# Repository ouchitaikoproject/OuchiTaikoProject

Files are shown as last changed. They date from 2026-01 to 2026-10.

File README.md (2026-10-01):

<div align="center">
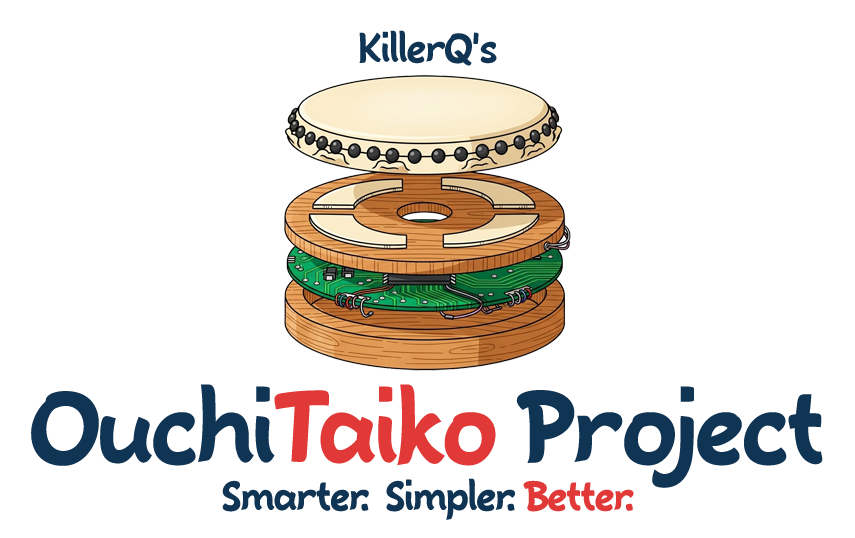
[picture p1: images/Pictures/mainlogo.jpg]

</div>

---

<div align="center">
<i>In Japanese, "ouchi" means "home," and "taiko" means "drum."
</br>  
Together, OuchiTaiko represents the joy of bringing the arcade Taiko experience into your own space.</i>
</div>

---

# Table of Contents

- [1. Project Overview](#project-overview)
- [Key Features and World Firsts Not Seen In Any Other Existing Projects](#key-features)
  - [1) Guided Calibrate](#guided-calibrate)
  - [2) Adaptive Baseline Software Intelligence (ABSI)](#absi)
  - [3) Custom Arcade Sensor Suspension Modeled After Japanese Taiko Arcade Hardware](#sensor-suspension)
  - [Complete Hardware & Features](#complete-hardware-features)
- [2. Parts List for Electronics](#parts-list-electronics)
- [3. Parts List for Hardware](#parts-list-hardware)
- [4. Assemble the Controller PCB](#assemble-controller-pcb)
- [5: Build the Sensor Housings](#build-sensor-housings)
  - [5.0: Print The Sensor Housings](#print-sensor-housings)
  - [5.1: Assemble Sensor Electronics](#assemble-sensor-electronics)
- [6: Build the Drum](#build-drum)
  - [6.1: Prepare the Wood](#prepare-the-wood)
  - [6.2: Assemble the Drum Structure](#assemble-drum-structure)
  - [6.3: Assemble The Rubber Isolators](#assemble-rubber-isolators)
  - [6.4: Mount the Sensor Housings to The Drum](#mount-sensor-housings-to-drum)
  - [6.5: Mounting The Hardware And Faceplates](#mounting-hardware-and-faceplates)
- [7: Control Box Connection](#control-box-connection)
  - [7.1: Floor Stand Mode](#floor-stand-mode)
  - [7.2: Table-Top Mode](#table-top-mode)
- [8: Flash the Firmware](#flash-the-firmware)
- [9: Calibration & Settings](#calibration-settings)
- [10: Files & Downloads](#files-downloads)
- [11: Basic Troubleshooting](#basic-troubleshooting)
- [12: Menu System Reference](#menu-system-reference)
- [13: About](#about)
- [14: Copyright Information](#copyright-information)

---

# 1. Project Overview

## The Finished Build
This guide walks you through building a full Arcade-Scale Taiko drum and controller that can be used in either **Floor-Standing Tripod Mode** or **Table-Top Mode**.

<div align="center">
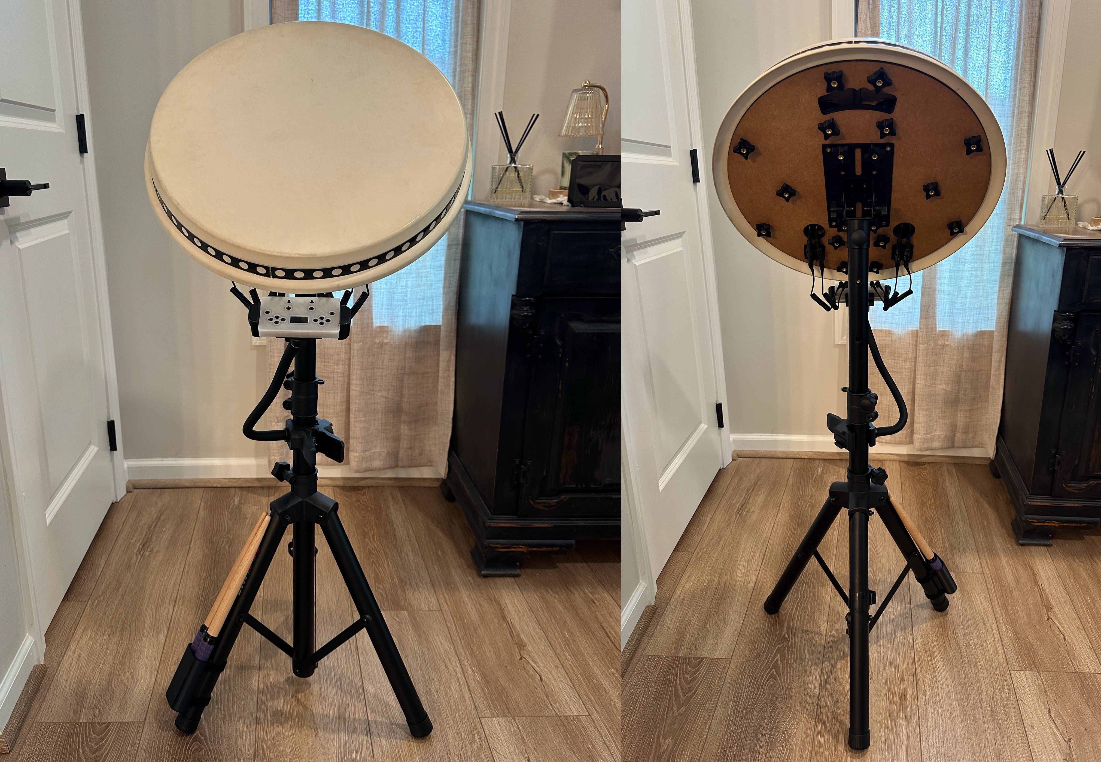
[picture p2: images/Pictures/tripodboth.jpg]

</div>

<div align="center">
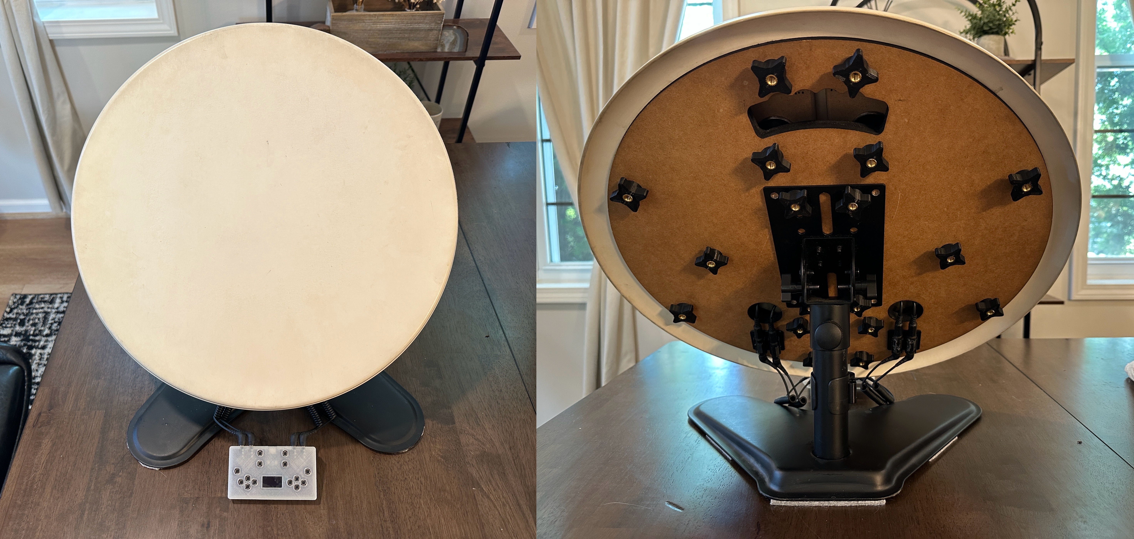
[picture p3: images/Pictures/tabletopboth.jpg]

</div>

---

Hi, I'm KillerQ - creator of the **OuchiTaiko Project**, an open-source guide for building a professional, arcade-grade Taiko drum controller.

This project is the result of over a year and a half of Research & Development focused on solving the high cost, limited availability, and inconsistent performance of commercial Taiko controllers. By combining a completely new software performance engine, a custom through-hole PCB, and a mechanically isolated sensor system, OuchiTaiko delivers arcade-level responsiveness with approachable DIY construction.

All you need are very basic soldering and woodworking skills.

This guide is intentionally thorough and detailed - the goal is simple: **less guessing, more building.**

---

# Key Features and World Firsts Not Seen In Any Other Existing Projects

Traditional Taiko controllers often require constant threshold tuning, extensive coding and firmware recompiling, or compromises between sensitivity and false triggers.

**OuchiTaiko solves these issues with three core systems:**

1. Guided Calibrate  
2. Adaptive Baseline Software Intelligence (ABSI)  
3. Custom Sensor Suspension System
---

## 1) Guided Calibrate
OuchiTaiko includes two Guided Calibrate options:

- Guided Calibrate for the preferred full setup workflow  
- On-device Guided Calibrate for the same method, but on the controller  
- No recompiling required  
- Fast threshold refinement  
- Easier crosstalk diagnosis  
- Quick retesting after hardware changes  

---

## 2) Adaptive Baseline Software Intelligence (ABSI)
ABSI was created by me just for this project, and I am very proud of it. It drastically improves stability through software rather than complex analog circuitry.

- Automatic sensitivity adjustment based on environmental noise  
- Dynamic baseline tracking  
- Stable long-term behavior without drift  

---

## 3) Custom Arcade Sensor Suspension Modeled After Japanese Taiko Arcade Hardware
A mechanically isolated sensor housing improves consistency and reduces noise.

Benefits include:

- More consistent hit detection  
- Reduced mechanical crosstalk  
- Cleaner signal processing  
- Long-term durability  

---

## Complete Hardware & Features

### Standalone Testing & Display
No PC required for basic verification.

- OLED display with live feedback  
- Visual confirmation of all 14 navigation buttons  
- Live hit display and mode readout  
- Instant sensor and button assignment wiring verification using only USB power  

---

### Professional Hardware

- Custom PCB designed specifically for this project  
- 14 navigation buttons for full game control  
- Adjustable drum mounting options  
- Dedicated sensor inputs for all four drum lanes 
- The entire Drum is modular so if a part ever fails, just that single part can be easily accessed and swapped out

---

### Controller Modes

| Mode | Platform Compatibility
|---|---|
| **Switch Tatacon** | Nintendo Switch
| **Switch Pro** | Nintendo Switch 
| **PS3 Dualshock3** | PC/Steam only
| **PS4 Tatacon** | PC/Steam only
| **PS4 Dualshock4** | PC/Steam only
| **Keyboard P1** | PC
| **Keyboard P2** | PC
| **Xbox 360** | PC/Xbox
| **Android (XInput)** | Android devices
| **iOS (XInput)** | iOS devices
| **Analog P1** | PC (TaikoArcadeLoader)
| **Analog P2** | PC (TaikoArcadeLoader)
| **MIDI** | PC/DAW software
| **Guided Calibrate** | Development/Testing

---

### Zero Coding Required

- Drag-and-drop firmware flashing  
- On-device menus  
- No recompiling for normal setup  
- No programming knowledge needed  

---

### Demo Video

- Gameplay: https://youtu.be/p4eFeo_LB5I?si=jDKb93B7uYx1qAux

---

# 2. Parts List for Electronics

<div align="right"><sub><a href="#table-of-contents">-Back to Top-</a></sub></div>

These linked parts are verified to work together as tested. Similar/comparable parts can be used, but at your own risk.

| Item | Pieces Needed | Product Link |
| --- | --- | --- |
| Waveshare RP2040-Zero | 1 | https://www.amazon.com/dp/B09SBCKYSC |
| 1N4148 diodes | 4 | https://www.amazon.com/dp/B0DN62QFYS |
| 0.1uF / 100nF ceramic capacitors | 4 | https://www.amazon.com/dp/B08B3VCK42 |
| 3.5mm female audio jack, PJ-320A | 4 | https://www.amazon.com/dp/B07KY862P6 |
| 3.5mm TRS male plugs with leads | 4 | https://www.amazon.com/dp/B0D72TV7Y5 |
| 1K ohm resistor, 1/2W | 4 | https://www.amazon.com/dp/B0FP1YFMVM |
| 27mm piezo sensors (for full size Drum Sensors) | 4 | https://www.amazon.com/dp/B07RK2TQ8D |
| 20mm piezo sensors (for smaller sensor option) | 4 | https://www.amazon.com/dp/B00SWO6VJ0 |
| 128x64 mono OLED display (I2C) | 1 | https://www.amazon.com/dp/B09T6SJBV5 |
| 6mm tactile switches with caps | 14 | https://www.amazon.com/dp/B07VQF8P2Y |
| 6" coiled 3.5mm TRS extension cable | 4 | https://www.amazon.com/dp/B0D7CXJ5LQ |
| 3.5mm TRS barrel coupler | 4 | https://www.amazon.com/dp/B072J3LGSQ |
| 6ft USB-A to USB-C cable | 1 | https://www.amazon.com/dp/B0CKXZML11 |

---

# 3. Parts List for Hardware

<div align="right"><sub><a href="#table-of-contents">-Back to Top-</a></sub></div>

## Required Tools & Supplies

1. Laser cutter, CNC, or alternative cutting method  
2. Soldering iron + solder  
3. Wire strippers / cutters  
4. Screwdrivers  
5. Hot glue gun  
6. Strong clamps  
7. Drill  
8. Router  
9. Sandpaper  
10. Utility knife  
11. Rubber mallet  

## Hardware Parts List

| Item | Pieces Needed | Product Link |
| --- | --- | --- |
| 1/4" (6mm) MDF, 2ft x 4ft | 2 | https://www.homedepot.com/p/1-4-in-x-2-ft-x-4-ft-MDF-1508104/202089069 |
| 1/4" x 1-1/2" OD stainless fender washers | 46 | https://www.amazon.com/dp/B0D8ZRL1CP |
| Wood glue | 1 | https://www.amazon.com/dp/B0002YQ378 |
| M3 x 8mm bolts (for full size sensors) | 8 | https://www.amazon.com/dp/B0FS1Q3FC2 |
| M3 x 8mm bolts (for smaller size sensors) | 8 | https://www.amazon.com/dp/B0FS1Q3FC2 |
| M3 x 5mm threaded inserts | 8 | https://www.amazon.com/dp/B0FS1Q3FC2 |
| M6 x 10mm wood threaded inserts | 14 | https://www.amazon.com/dp/B0CNLRFFH1 |
| M6 x 35mm nylon bolts | 14 | https://www.amazon.com/dp/B07L9ZS21T |
| M6 threaded 20mm x 15mm rubber isolators | 14 | https://www.amazon.com/dp/B0BKPHT6Y9 |
| PLA filament | 1 | https://www.amazon.com/dp/B081S5N5PC |
| Gel superglue | 1 | https://www.amazon.com/dp/B0006HUJCQ |
| Medium thread adhesive / Loctite | 1 | https://www.amazon.com/dp/B000FIXQXK |
| 2.2mm scuba knit neoprene fabric | 1 | https://www.amazon.com/dp/B0DK1B5LZ7 |
| Finger knobs with pass-through M6 threads | 18 | https://www.amazon.com/dp/B07RW9ZH4H |
| Mini PA speaker tripod stand (optional) | 1 | https://www.amazon.com/dp/B094N9YG72 |
| Desktop monitor stand (optional) | 1 | https://www.amazon.com/dp/B072QDMRS8 |
| Adjustable angle speaker bracket | 1 | https://www.amazon.com/dp/B0DR8NCZP6 |
| Phone holder w/ gooseneck arm (optional) | 1 | https://www.amazon.com/dp/B0F32MLBZX |
| Rubber Taiko drum cover (recommended) | 1 | https://taiko.ac/products/rubber-drum-pad |
| 1/4" roundover router bit | 1 | https://www.amazon.com/dp/B0C5DVBNLS |
| Clear spray glaze / lacquer | 1 | https://www.amazon.com/dp/B00D0293SA |
| Deburring tool (optional) | 1 | https://www.amazon.com/dp/B07RM1D6WD |

---

# 4. Assemble the Controller PCB

<div align="right"><sub><a href="#table-of-contents">-Back to Top-</a></sub></div>

<div align="center">
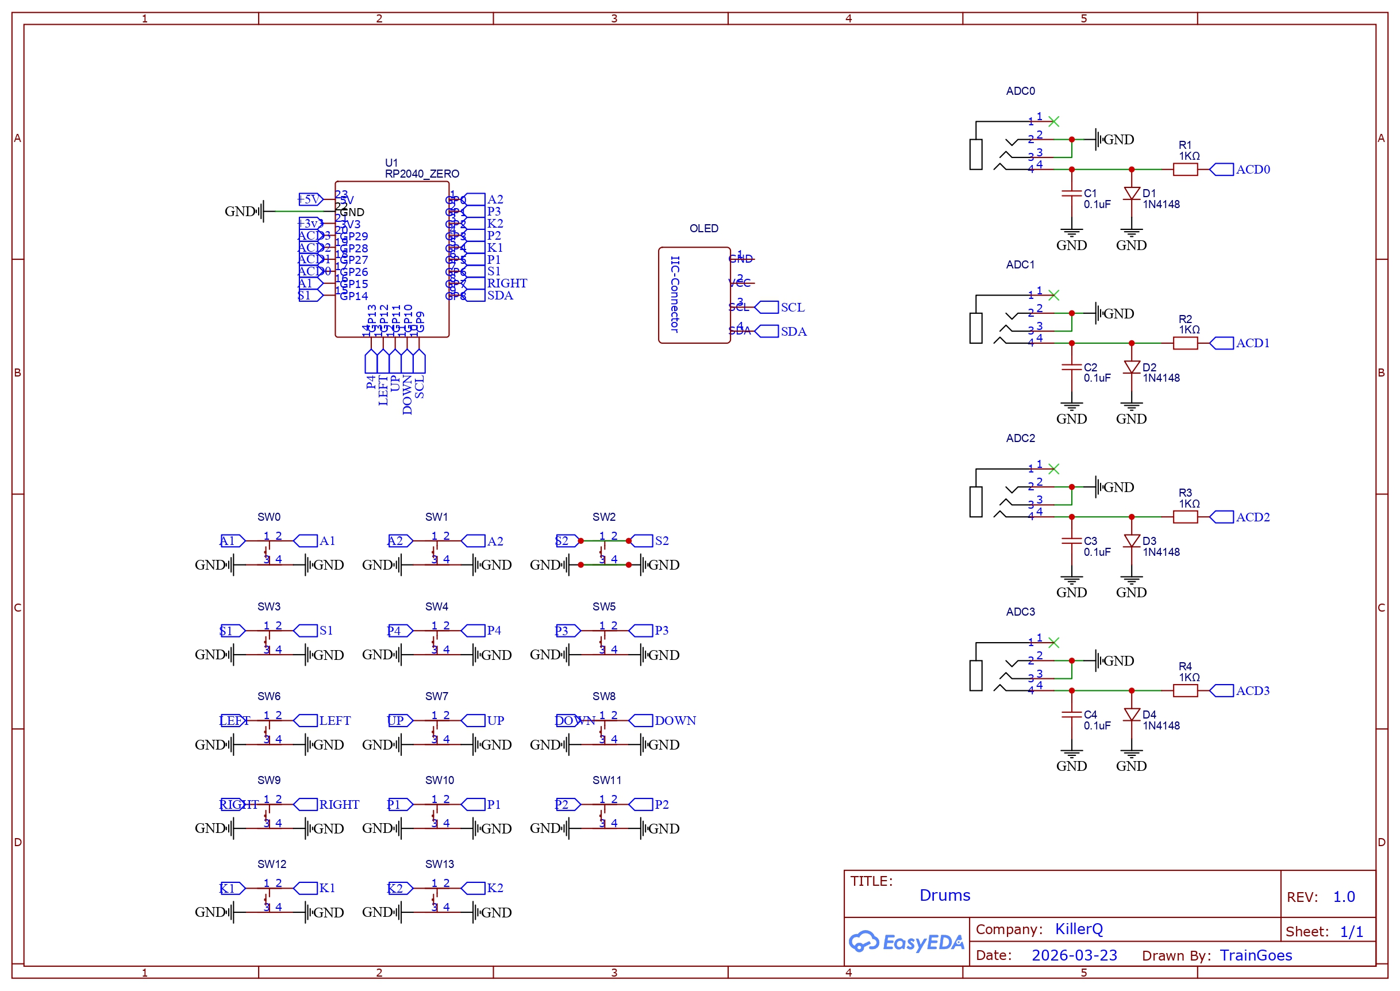
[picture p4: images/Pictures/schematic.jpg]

</div>

<div align="center">
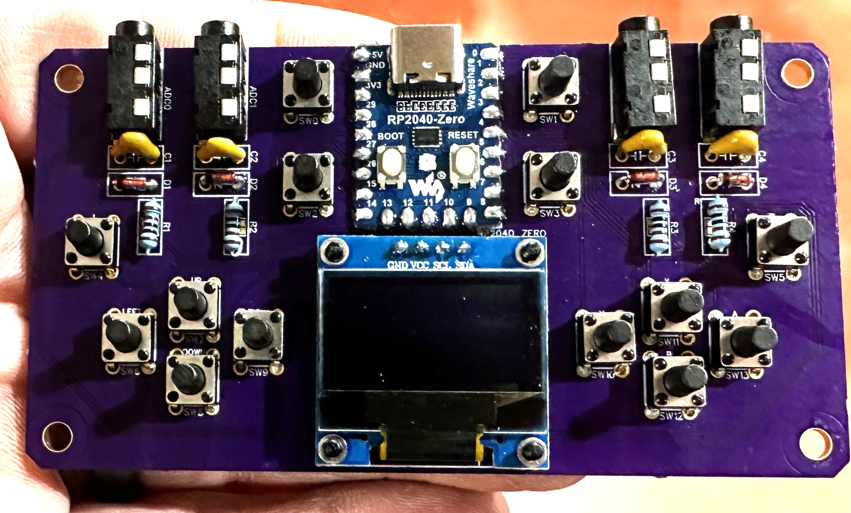
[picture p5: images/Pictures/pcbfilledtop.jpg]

</div>

## Purchase the OuchiTaiko Controller PCB (Circuit Board).

My project is set up to where you will order the through-hole circuit board and then solder the basic components in yourself.  This saves time, money, and eliminates any room for error.

I <i>highly</i> recommend purchasing the raw Controller PCB from OSHPARK PCB Fabrications. They are in the US, and all manufacturing is done in the US. They are very reasonably priced, and you can even pay for expedited production/shipping. They sell in sets of 3 only, but that price is still reasonable, and that way you have a spare in case you damage one, or you can split the order with a friend.  You may notice that this company charges more than others that manufacture outside of the US, but if you read around their site, you'll see that they quality is above-and-beyond and the boards have an amazing look and feel to them.

If you decide use OSHPARK here is a link to the Board that's already uploaded and verified on their site, and you can hit purchase right away. I do not make any money off of this link or benefit in any way - they just offer the convenient service of allowing me to upload the board so that people can simply add it to their cart and check out without the hassle of uploading the raw files and hoping everything is correct and verified after the upload, etc.

<a href="https://oshpark.com/shared_projects/mY0Hmilt">HERE is the link to the OSHPARK OuchiTaiko Controller Board Page</a>

However, since I made my project open source, you have 100% control over where to have the board manufactured.  If you have a company that you trust that you would like to use instead, here is the Gerber .zip file that contains all of the universal project files that the company will need to produce my OuchiTaiko PCB.  

[`ouchitaiko_pcb_gerber_v1_final.zip`](https://raw.githubusercontent.com/ouchitaikoproject/OuchiTaikoProject/main/download_files/ouchitaiko_pcb_gerber_v1_final.zip) is the PCB Gerber file package.

One person used https://jlcpcb.com/ and ordered my board (by uploading the above Gerber file) and had 5 boards made for about $6 total including shipping and it took around 2 weeks.

## Control PCB Overview

My custom OuchiTaiko PCB integrates controller logic, display wiring, navigation buttons, and drum input circuitry all together into a single compact board.

To finish building it, you will solder the following components to the board you have made:

- **1x Waveshare RP2040-Zero**  
- **14x tactile buttons**  
- **4x 1N4148 diodes**  
- **4x 1K resistors**  
- **4x 0.1uF capacitors**  
- **1x I2C OLED**  
- **4x PJ-320A TRS jacks**

That's it!  Everything is just attached via basic soldering.

---

## Recommended Assembly Order

### Step 1: Solder Passive Components
Install:

- `R1-R4` = 1K resistors

<div align="center">
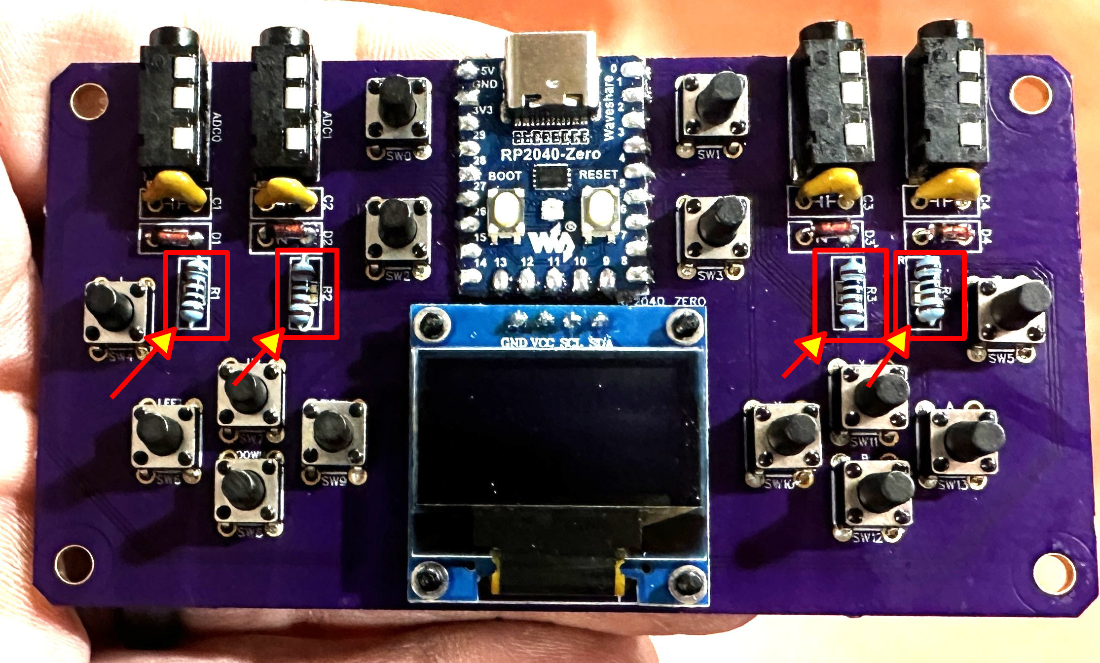
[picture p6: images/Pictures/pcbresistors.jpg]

</div>

- `C1-C4` = 0.1uF capacitors

<div align="center">
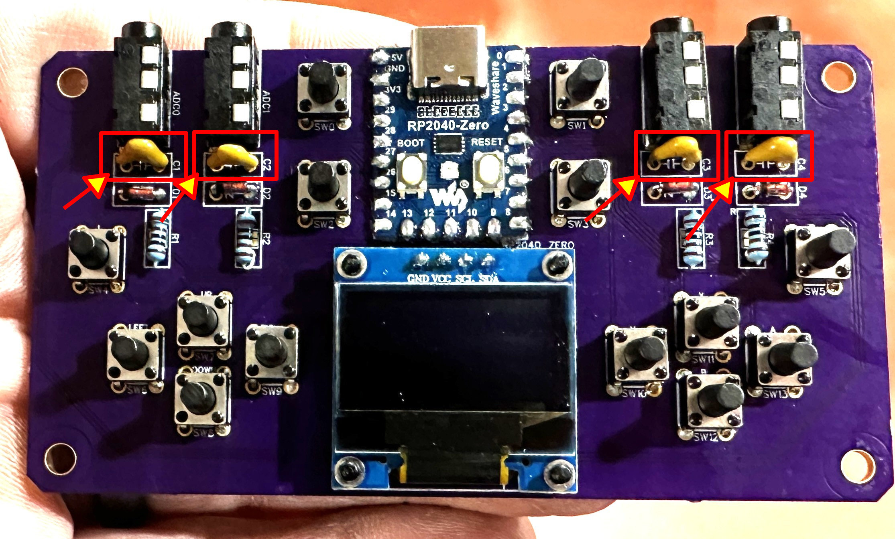
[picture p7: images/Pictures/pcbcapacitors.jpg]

</div>

- `D1-D4` = 1N4148 diodes

<div align="center">
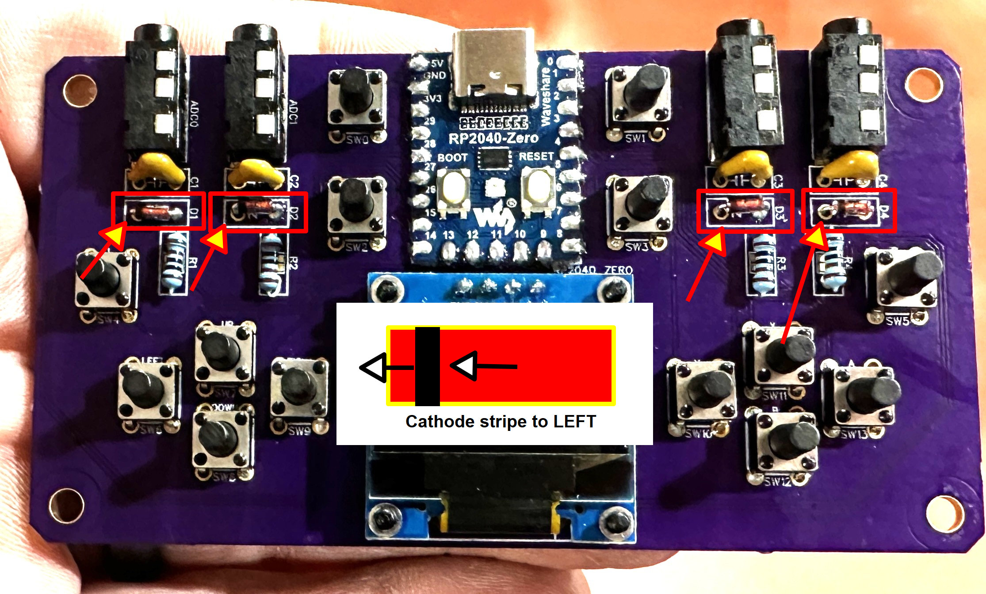
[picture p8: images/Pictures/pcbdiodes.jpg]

</div>

Important: Ensure diode black bands match the silkscreen (cathode to the **left** when viewed from above).

---

### Step 2: Solder the 14 Buttons
Install all navigation buttons.

<div align="center">
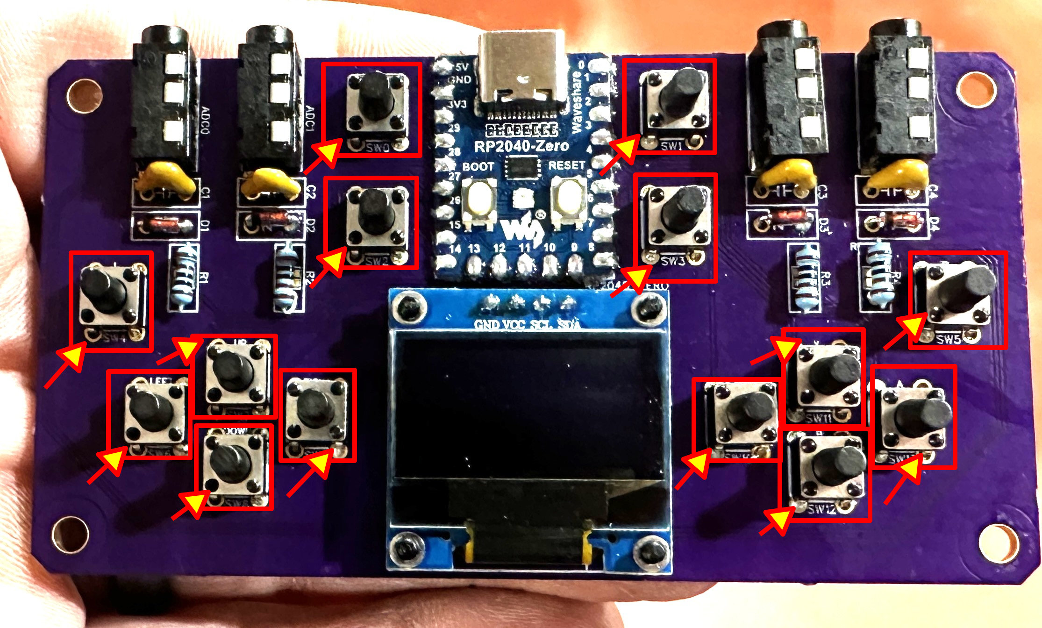
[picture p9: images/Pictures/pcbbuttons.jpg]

</div>

The button legs will actually appear in a rectangular layout orientation - longer on one side. The holes in the board will match that slightly rectangular shape - there is no polarity as long as that orientation is adhered to. Ensure each button sits flat before soldering all four legs.

---

### Step 3: Mount the OLED
Install the OLED using the following pin order (verify that yours matches):

- GND  
- VCC  
- SCL  
- SDA  

<div align="center">
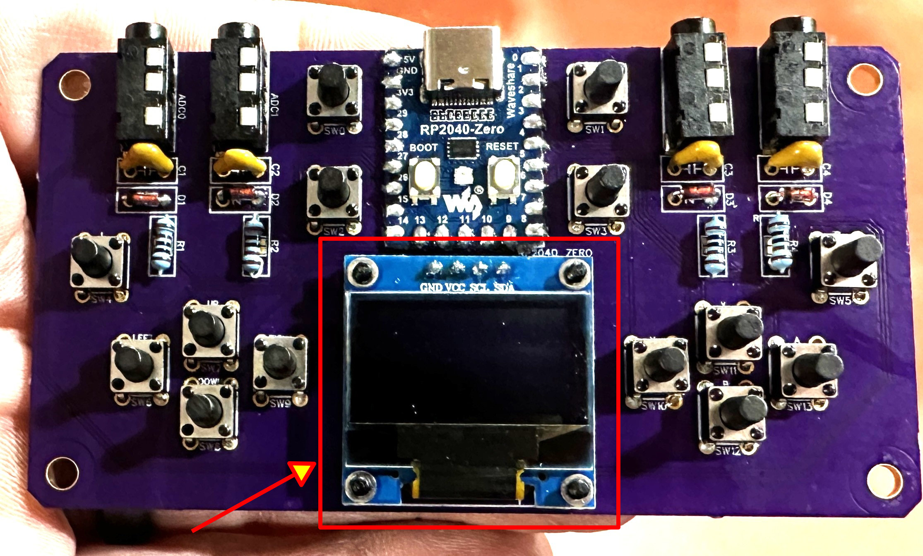
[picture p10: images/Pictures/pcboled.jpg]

</div>

---

### Step 4: Install the TRS Drum Input Jacks
Install the four PJ-320A jacks. Their pin layout only fits into one orientation.

<div align="center">
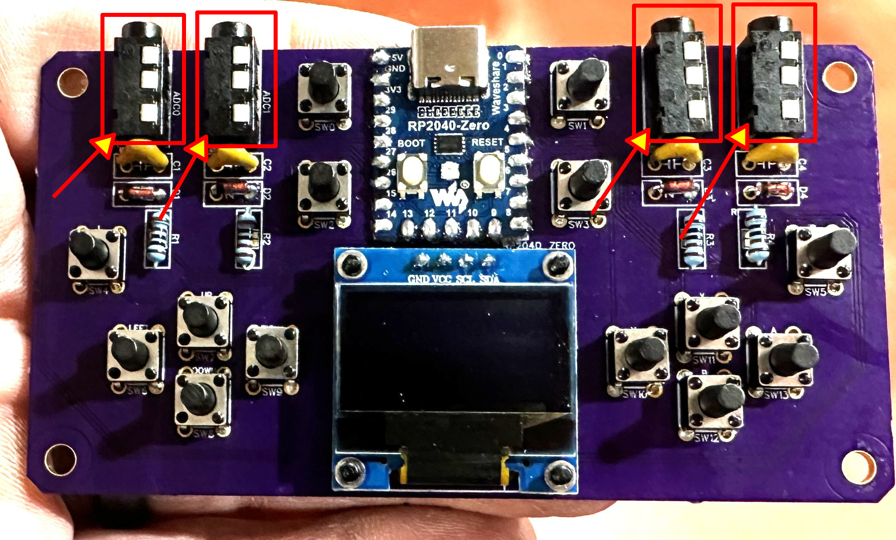
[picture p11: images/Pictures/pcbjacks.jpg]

</div>

---

### Step 5: Mount the RP2040-Zero
Install the Waveshare RP2040-Zero. Only the 20 castellated <i>perimeter pads</i> need soldering.

<div align="center">
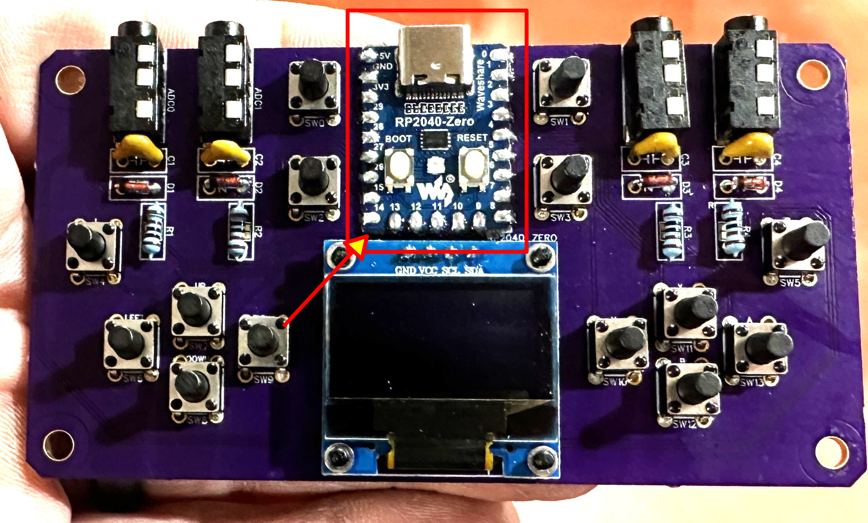
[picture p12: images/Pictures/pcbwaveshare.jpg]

</div>

A helpful soldering demonstration for soldering castellated pads:  
https://youtu.be/rGvvwXrv310?t=312

---

## Inspect Your Work

Before powering on, confirm:

- RP2040-Zero is aligned correctly  
- OLED pins are correct  
- All 14 buttons are soldered  
- All four drum lanes have resistor, capacitor, and diode installed  
- No solder bridges  
- All joints look solid  

If you were just building the controller and sensors for an existing drum that you already had, you can skip ahead to **Section 8: Flash the Firmware**.

---

# **5: Build the Sensor Housings**

## **5.0: Print The Sensor Housings**

\*\* download \*\* [`ouchitaiko_sensor_housing.stl`](https://raw.githubusercontent.com/ouchitaikoproject/OuchiTaikoProject/main/download_files/ouchitaiko_sensor_housing.stl) is the sensor housing STL file

Print 4 complete sets of Sensor Housings (each set has a top and bottom).

Use **PLA filament**.

**Printer Settings:** 0.2mm layer height, 40% Gyroid infill, no supports needed.

## **5.1: Assemble Sensor Electronics**

\*\* video \*\* [Video overview of sensor housing assembly](https://youtu.be/tQe-xDEqEdY)

(Note: If you choose to make the smaller version of the sensor housings because you're using them on a smaller drum, the below procedure is the same except you'll 3D print the smaller housing and bracket, you'll cut a 8mm neoprene disc (instead of 12mm) and you'll use the 20mm Piezo (instead of the 27mm Piezo).  The installation is the same, just smaller parts).

### **Cut neoprene discs**

Cut four **12mm neoprene discs** by using the SVG template.

\*\* download \*\* [Neoprene Disc Template Files are in the file packet here](#files-downloads)

### **Glue neoprene disc to housing**

Place several drops of **Superglue** into the raised center ring in the bottom shell of the housing. Place a single neoprene disc in this ring on top of the glue. Press lightly for 30 seconds.

<div align="center">
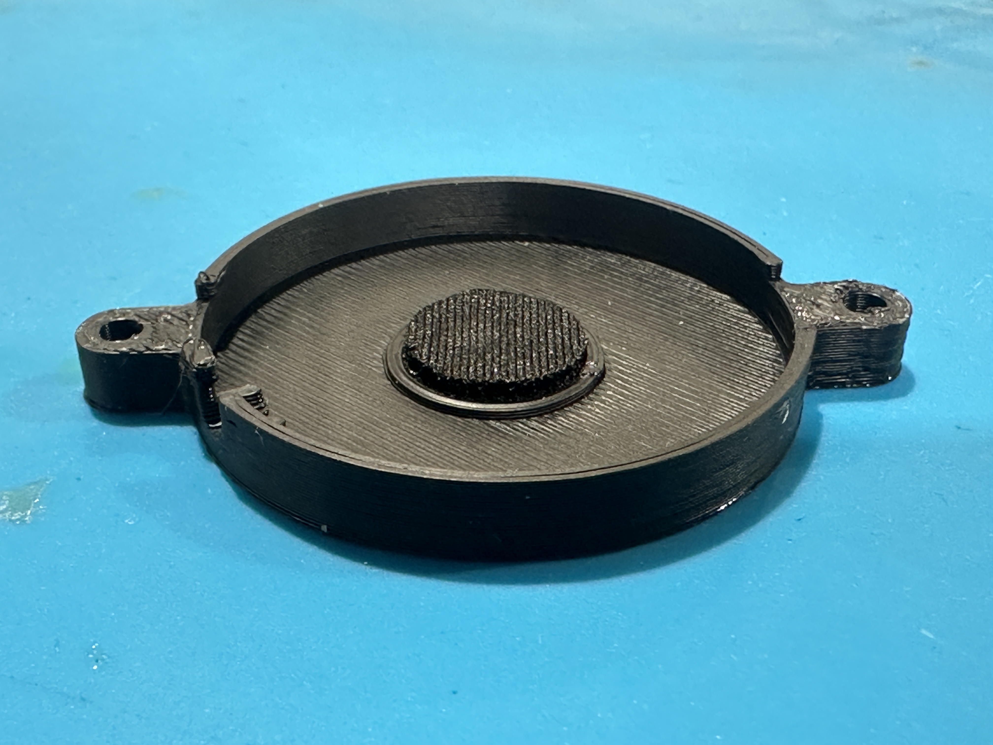
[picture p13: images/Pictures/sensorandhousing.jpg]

</div>

### **Prepare end of TRS Sensor Wires**

(**IMPORTANT** 
This guide assumes that your 3.5mm cable has the RED wire connected to the TIP of the TRS jack 
and that the BLACK wire is connected to the SLEEVE of the TRS jack. 

The result of the sensor wiring needs to be that the center of the disc is connected to the TIP
and that the brass part of the ring is connected to the SLEEVE of the TRS jack.)  

Since you are starting with long lengths of wire, you have two choices to proceed.

1. If you plan on building the drum in my guide, then you can cut the length of wire down to approximately 12" so that it will route cleanly through the drum and end up at the connectors at the base of the drum.
2. If you plan on using these sensors to add to a different or already existing drum, I suggest that you leave the wires at their full length. This allows more freedom of mounting and routing when using them with another drum.

With your chosen length of wire, strip the ends of each so that they expose approximately 10mm of red wire and approximately 8mm of black wire. Now strip off approximately 1mm of red and black insulation to expose the bare wire and tin each end with solder.

Repeat this process for all 4 wires.

The difference in length is because you want them to be slightly offset as in this photo: 

<div align="center">
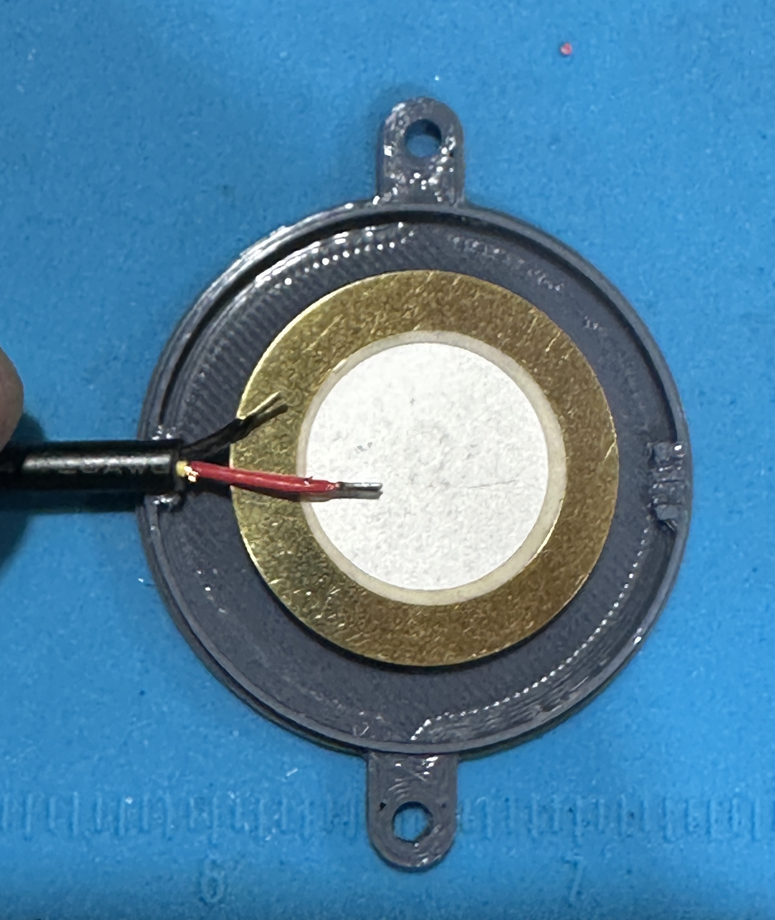
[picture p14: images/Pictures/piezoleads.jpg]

</div>

### **Solder to Piezo**

Now solder the **red** wire to piezo center disc, and solder the **black** wire to outer brass ring. The video linked at the beginning of this section illustrates how to do this easily.

<div align="center">
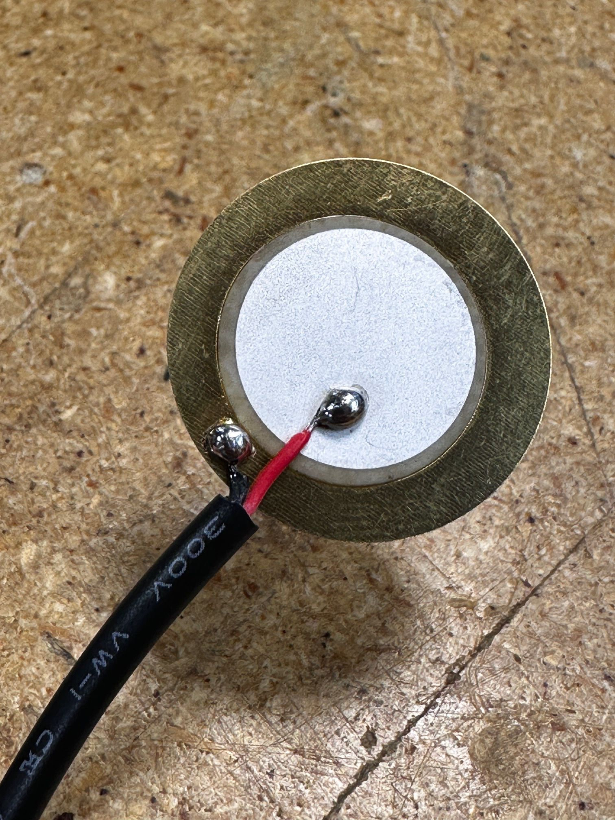
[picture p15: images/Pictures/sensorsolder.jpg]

</div>

### **Glue Piezo to Neoprene Mount**

Add several drops of **Superglue** onto the top surface of neoprene that is already glued to the bottom housing shell. Center the **piezo sensor** face up (the all-brass side faces *down*, your wires will be on the top) onto the neoprene. Press lightly for 30 seconds. 

\*\* note \*\* Pic varies slightly from your version - this was an earlier version.

<div align="center">
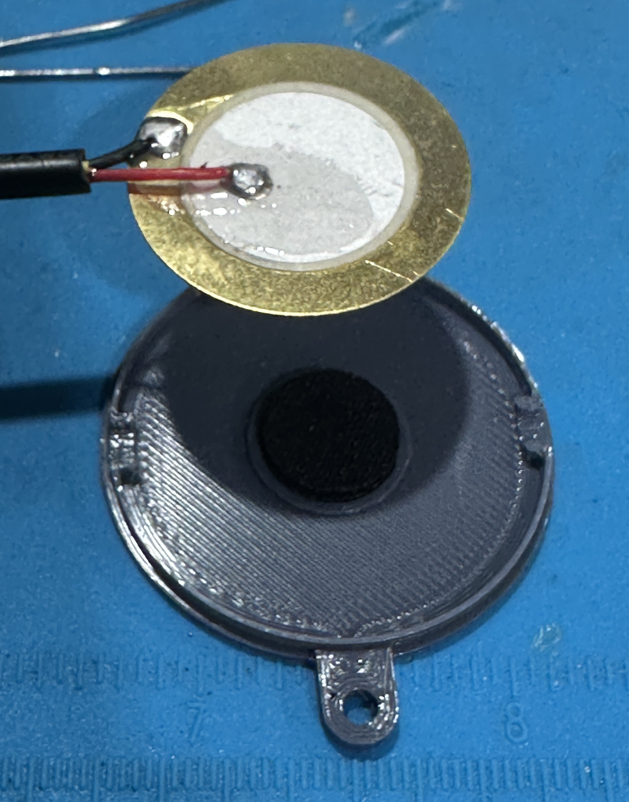
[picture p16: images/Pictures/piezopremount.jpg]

</div>

<div align="center">
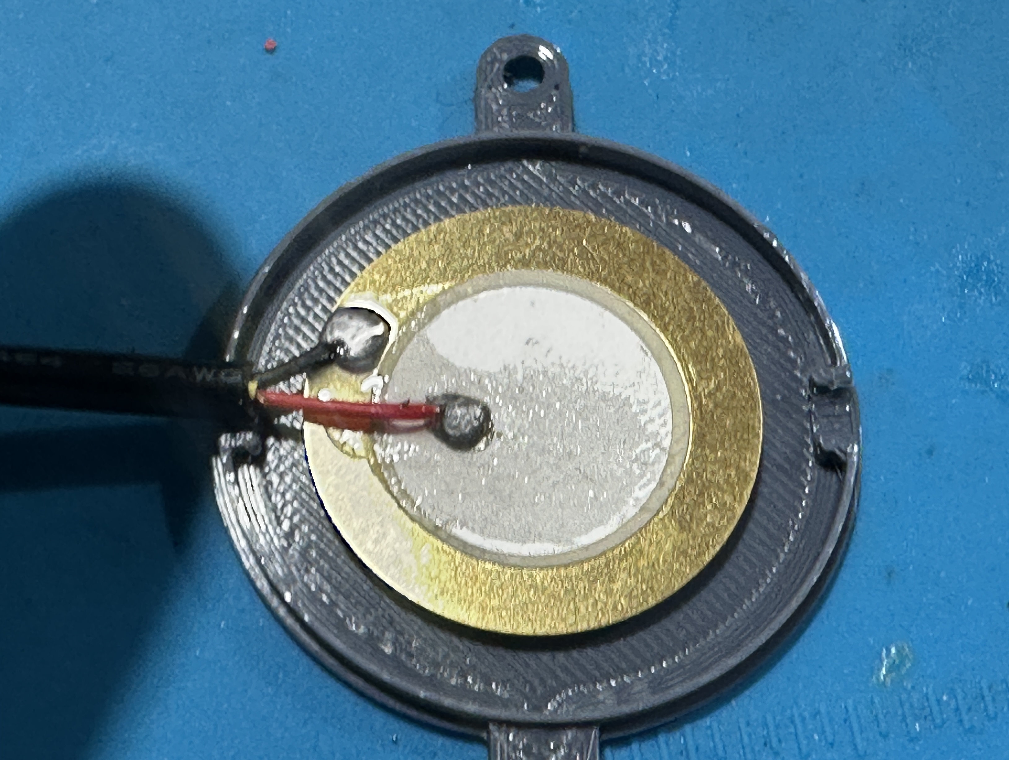
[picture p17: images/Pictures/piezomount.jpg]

</div>

### **Enclose Housing**

Add a drop of **Superglue** around the inner rim of the housing and then press the two halves together. Press and hold for 30 seconds. The top shell of the housing will nest into place when aligned properly.

After 30 seconds, add a little bit of **Hot Glue** to the wire where it meets against the outside of the housing - this will act as additional strain relief. 

<div align="center">
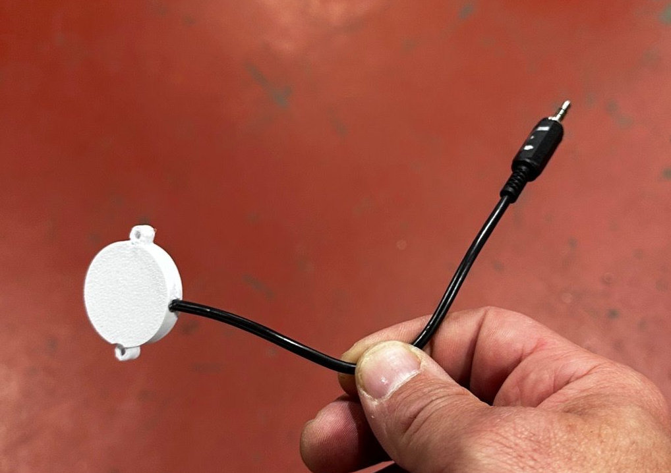
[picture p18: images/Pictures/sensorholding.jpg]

</div>

> Repeat these steps until you have 4 complete sensor assemblies.
>
> **Using these sensors with an existing drum that you have?**
> You can skip the full drum build. Jump to [**Section 6.4: Mount the Sensor Housings to The Drum**](#mount-sensor-housings-to-drum), then continue to [**Section 8: Flash the Firmware**](#flash-the-firmware).
>
> **Building a new drum using my guide?**
> If you are building the complete OuchiTaiko drum, continue below to Step #6 to begin constructing your Taiko Drum.

# **6: Build the Drum**

<div align="right"><sub><a href="#table-of-contents">-Back to Top-</a></sub></div>

**Important Scale Notice:** The SVG files provided in the download are the correct scale and should **NOT** be resized. The drum dimensions are precisely calculated to work with the sensor housings and other non-scalable components. If you try to make the drum smaller, other parts will not fit later in the project.

\*\* note \*\* Before cutting, verify the SVG files are at correct scale by checking the shapes in the SVG file against the listed dimensions noted in the KEY section of that same SVG file. 

**No laser cutter or CNC access?** No worries - there are other options. Ask a friend, local shop, or check if your area has a Makerspace. Alternatively, you can print the SVG files full-size across multiple sheets of paper (ensure your printer is set to 100% scale / "Actual Size"), and then overlay the paper on your wood as a template.  You would then cut and drill by hand. Double check that your printed templates are sized properly before cutting or drilling anything.

## **6.1: Prepare the Wood**

### **Cut all MDF wood pieces per SVG templates**

\*\* download \*\* [`ouchitaiko_laser_files.svg`](https://raw.githubusercontent.com/ouchitaikoproject/OuchiTaikoProject/main/download_files/ouchitaiko_laser_files.svg) and [`ouchitaiko_laser_files.lbrn2`](https://raw.githubusercontent.com/ouchitaikoproject/OuchiTaikoProject/main/download_files/ouchitaiko_laser_files.lbrn2) are the wood template files

Use your laser or CNC machine (or the method available to you) to cut out all of the wood components in the template files.

- You'll be printing one set of upper faceplates
- You'll be printing one set of lower faceplates
- You'll be printing 2x identical baseplates

<div align="center">
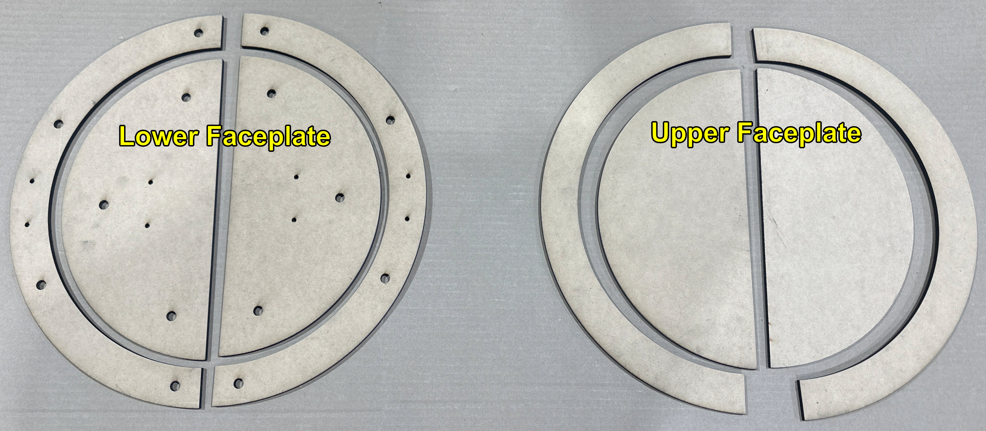
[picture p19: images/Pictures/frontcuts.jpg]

</div>

<div align="center">
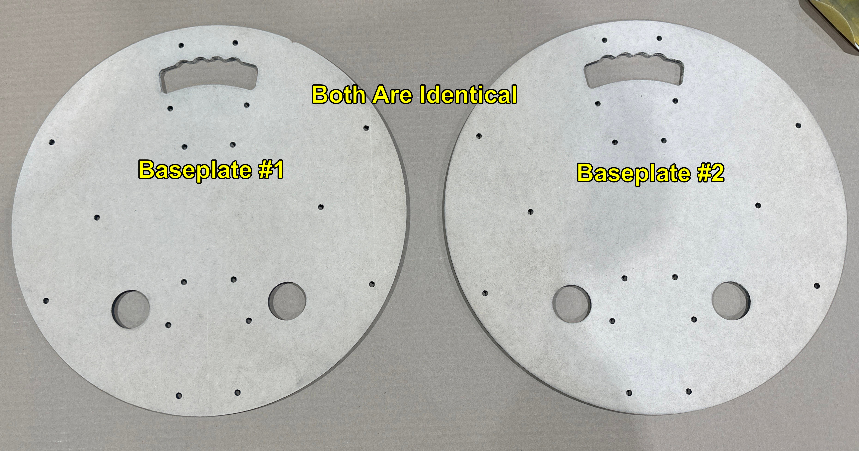
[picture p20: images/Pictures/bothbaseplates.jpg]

</div>

### **Sand smooth as needed**

Sand down any rough edges and surfaces from the cutting step, and wipe off sawdust to prepare for gluing.

## **6.2: Assemble the Drum Structure**

### **Glue the rear baseplates together**

Use **wood glue** to glue the two identical rear baseplates together (they are 100% identical, just align the holes and glue together). Clamp securely or weigh down and let dry for several hours. You can also temporarily insert some 6mm bolts into the holes to ensure the two plates remain exactly aligned. Until the glue really starts to set, periodically check the plates to make sure no shifting has occurred - if so, re-align and clamp harder.

Leave the clamps and weight on for at least 6 hours. Let the glue fully cure for 24 hours before continuing past the gluing steps.

<div align="center">
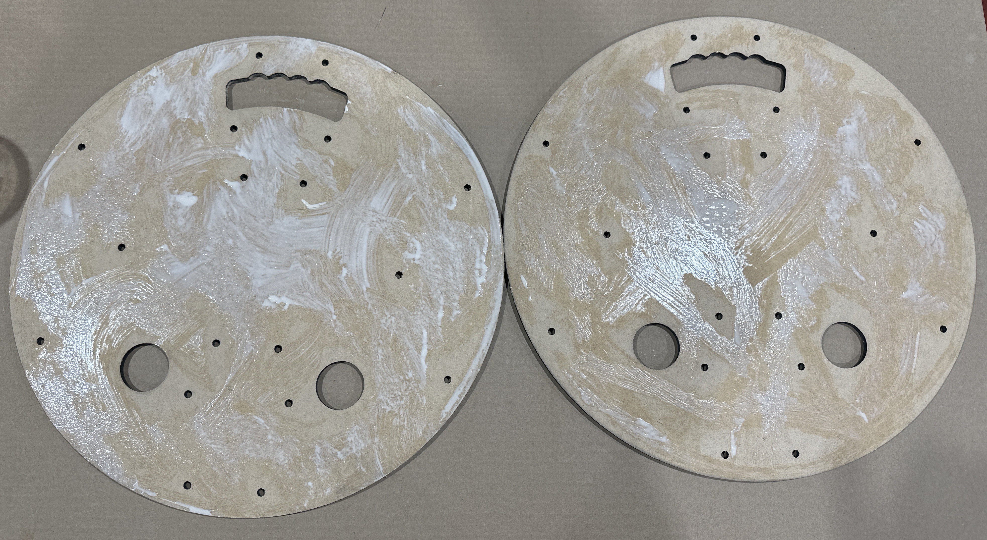
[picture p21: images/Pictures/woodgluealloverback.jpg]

</div>

<div align="center">
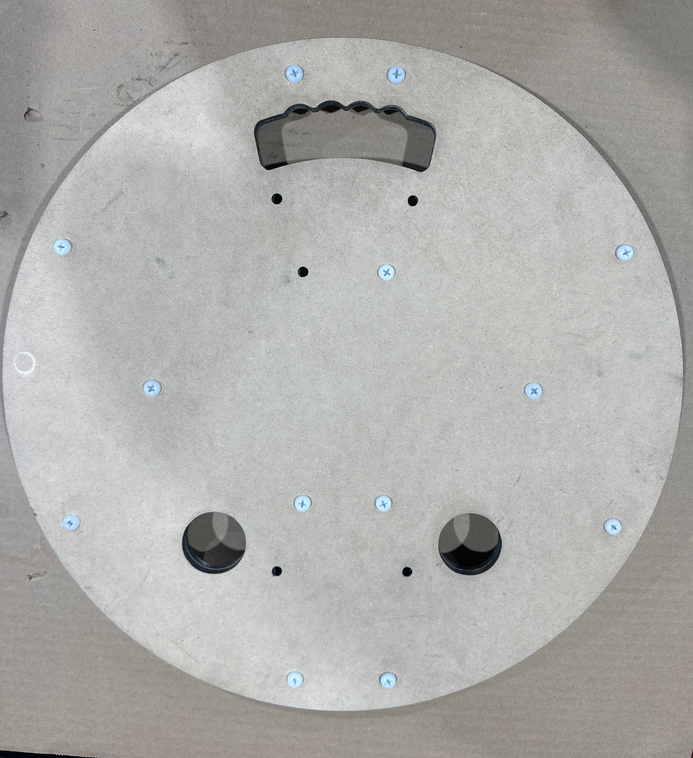
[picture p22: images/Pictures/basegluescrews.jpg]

</div>

<div align="center">
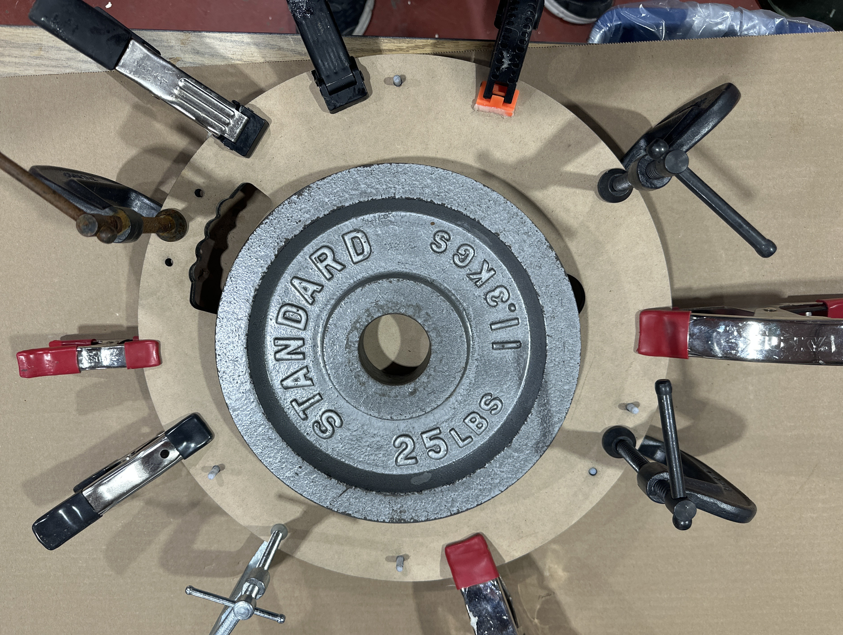
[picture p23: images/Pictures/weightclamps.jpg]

</div>

### **Assemble and glue the drum faceplates together**

There will be 4 finished drum faceplates that you will be assembling during this step: Left Ka, Left Don, Right Don, and Right Ka. Each faceplate consists of TWO pieces - a smooth TOP plate along with a corresponding BOTTOM plate with holes in it.

<div align="center">
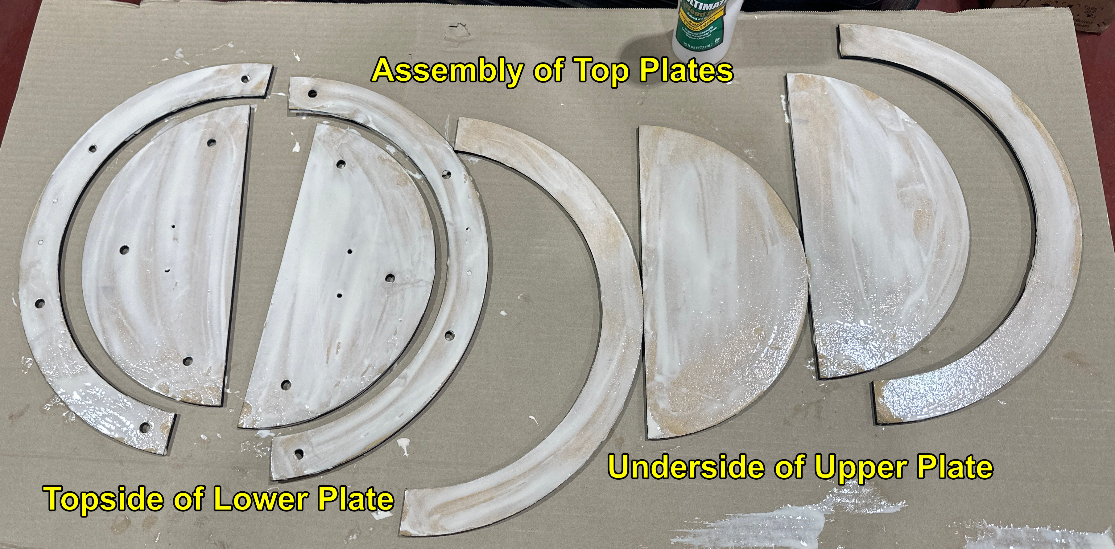
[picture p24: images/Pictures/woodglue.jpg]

</div>

<div align="center">
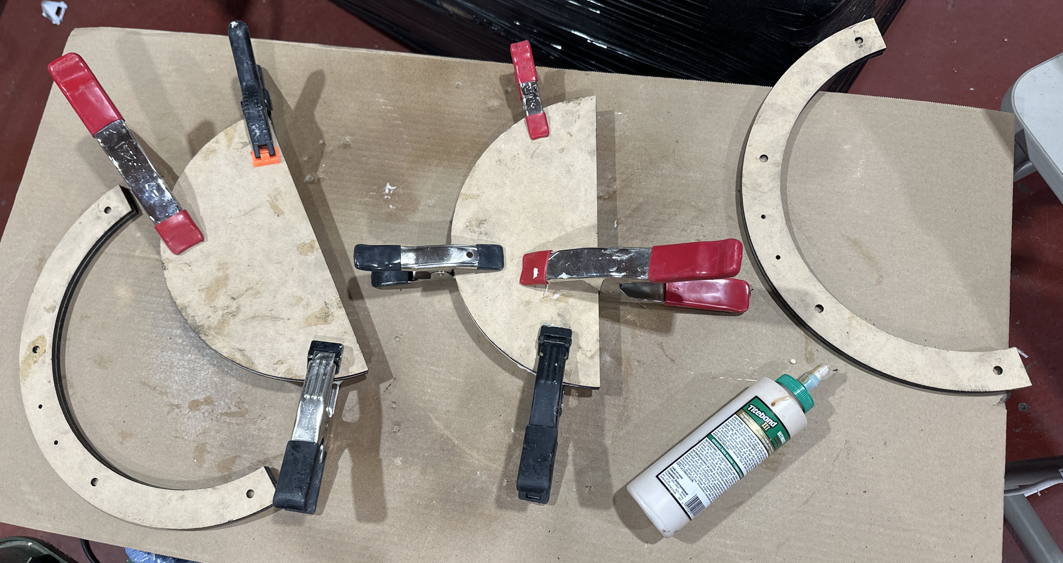
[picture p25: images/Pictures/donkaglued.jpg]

</div>

#### For Ka Plates

Let's start with the Ka plates - specifically, the Left Ka. You will be using the Left Ka TOP and the Left Ka BOTTOM plate.

Apply wood glue to the underside of the top Ka plate and apply wood glue to the topside of the lower Ka plate. Press the two pieces together and clamp or weigh them down. Until the glue really starts to set, periodically check the plates to make sure no shifting has occurred - if so, re-align and clamp harder. Leave the clamps and weight on for at least 6 hours. Let the glue fully cure for 24 hours before continuing past the gluing steps.

**Repeat this exact same process for the Right Ka.**

#### For Don Plates

Apply wood glue to the underside of the top Don plate and apply wood glue to the topside of the lower Don plate (don't forget, each piece is exactly the same in this step only, so it is up to you which is the top part and which is the bottom part). Press the two pieces together and clamp or weigh them down. Until the glue really starts to set, periodically check the plates to make sure no shifting has occurred - if so, re-align and clamp harder. Leave the clamps and weight on for at least 6 hours. Let the glue fully cure for 24 hours before continuing past the gluing steps.

**Repeat this exact same process for the Right Don.**

When complete, you will have 4 faceplates - each consisting of a top half and a bottom half.

### **Sand all Don, Ka, and Baseplate Edges**
- Sand any extra glue off of the surfaces of the drum and
- Be EXTRA sure to sand off any excess glue that has dripped out of the edges/seams.  This will ensure a clean, uniform surface to work with.

<div align="center">
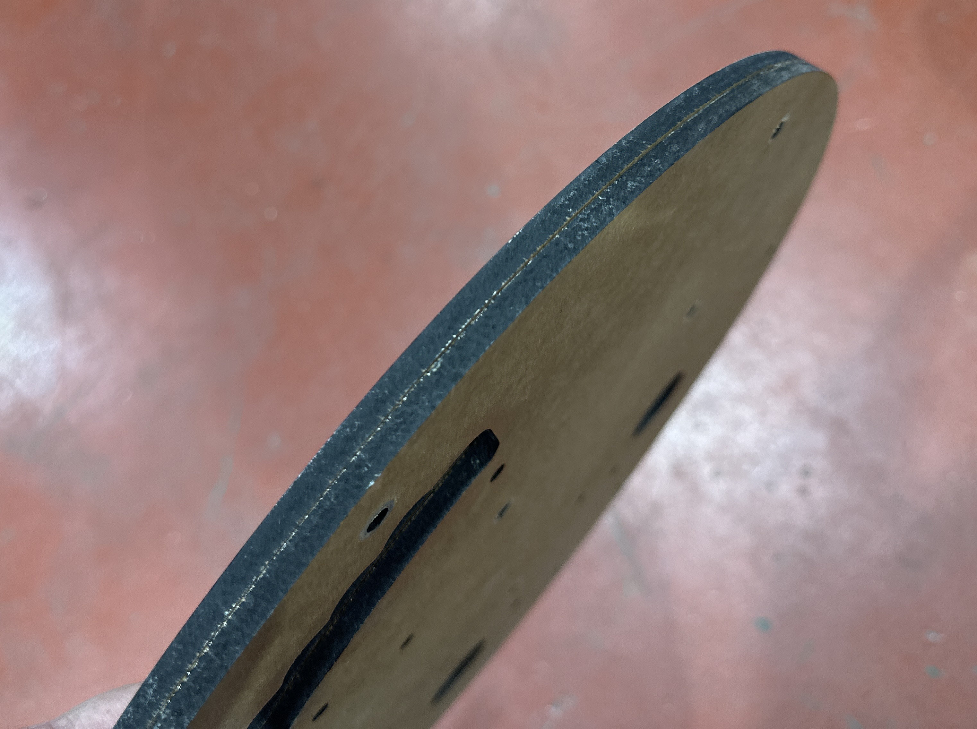
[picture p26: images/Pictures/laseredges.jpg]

</div>

### **Rout/Chamfer all Don Ka rim edges**

Using a router and a 1/4" roundover bit, route down every edge on the top and bottom of all glued pieces. If you don't have a router, you can use a deburring tool to lightly shave off the outer edges on the Don and Ka pieces. Sandpaper can also achieve a similar effect.

This procedure helps prevent stick damage and wear and tear on your drum and cover, as well as gives your drum a professional, clean look by softening/rounding down all of the sharp, 90 degree edges.

<div align="center">
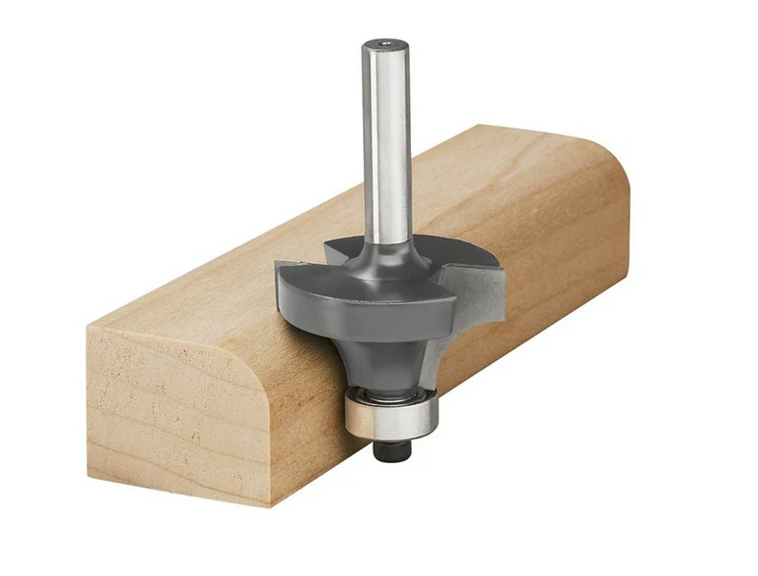
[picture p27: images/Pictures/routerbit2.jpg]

</div>

<div align="center">
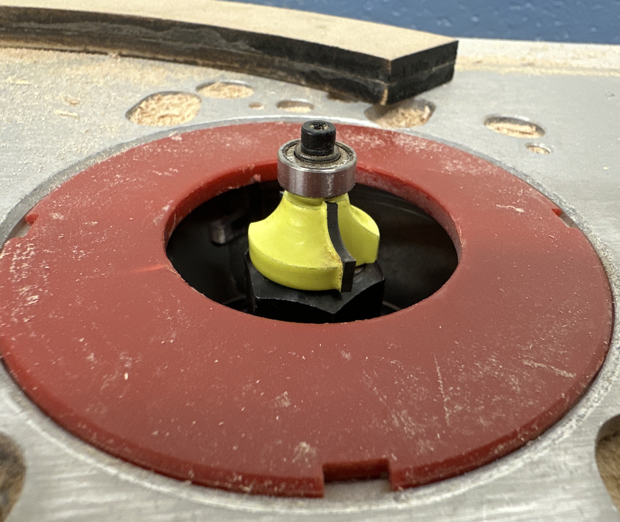
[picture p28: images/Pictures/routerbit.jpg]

</div>

<div align="center">
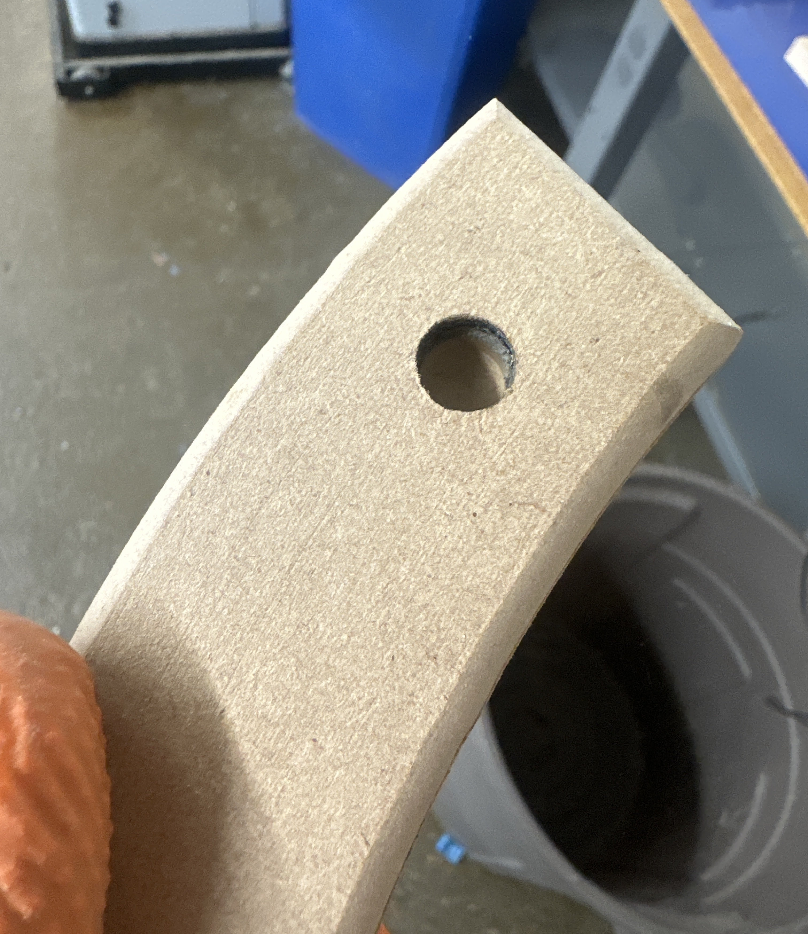
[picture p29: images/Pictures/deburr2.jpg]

</div>

<div align="center">
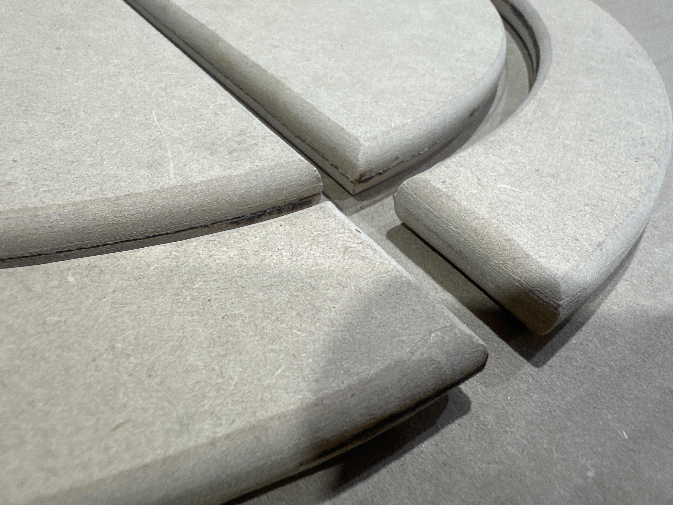
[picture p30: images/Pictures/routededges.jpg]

</div>

<div align="center">
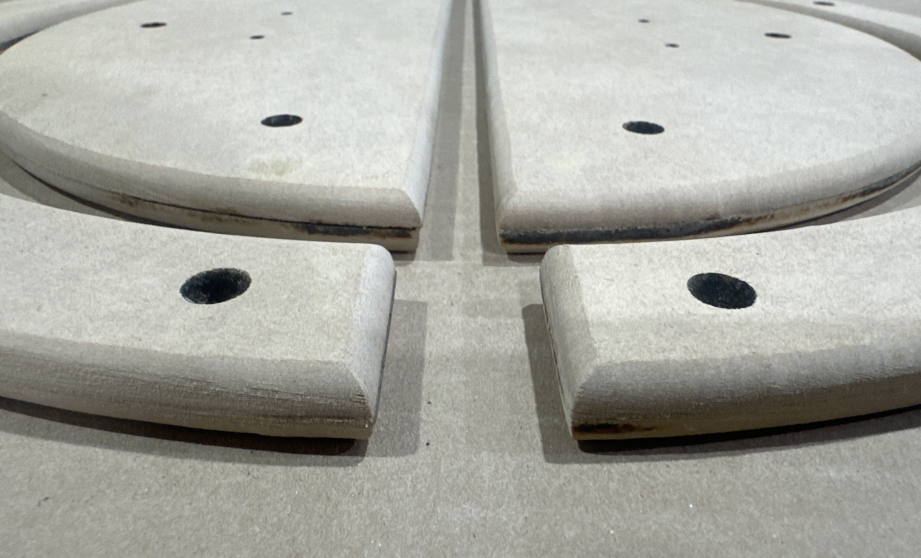
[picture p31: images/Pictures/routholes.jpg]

</div>

<div align="center">
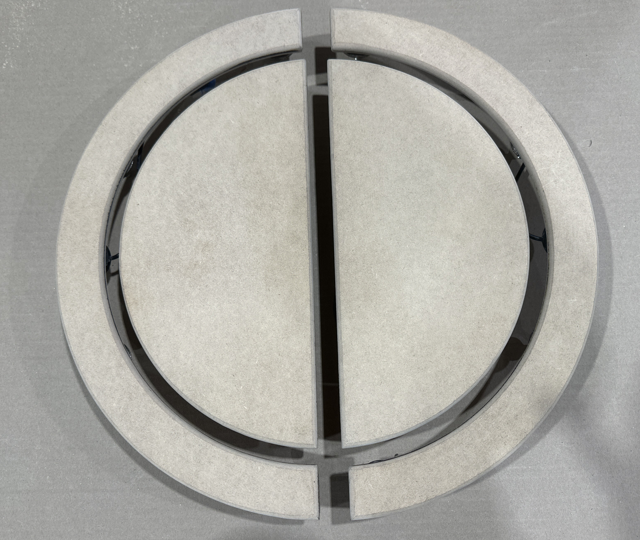
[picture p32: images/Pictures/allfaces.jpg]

</div>

### **Spray All Wood With Clear Lacquer**
You may now spray several coats of Clear Lacquer Spray Paint to the front back and sides all wood pieces.  This will help protect and seal the wood and reduce wear and tear.  Spray a single coat, let sit for 45 minutes.  Spray two more coats in a similar manner.  Let dry completely for 4 hours after the final coat before continuing.

### **Drill Holes For Threaded Inserts**

The following step allows the drum to be built with no visible mounting holes on the drum face. This improves aesthetics and reduces wear on sticks and the drum cover. You will drill holes into the underside of the top faceplates so the threaded inserts for the grommets can be installed from beneath and remain invisible.

The holes you will be working with are on the underside of the bottom Drum Face Plates.

Using a Drill press, insert a **9mm** diameter drill bit (or the specialized drill bit that came with your threaded wood inserts), and set it up so that when you drill press is fully lowered, the bottom of the drill bit is exactly 2mm above your drill press plate/table.  This way, you can ensure that every time you lower the drill press, you're getting the exact depth needed each time.

<div align="center">
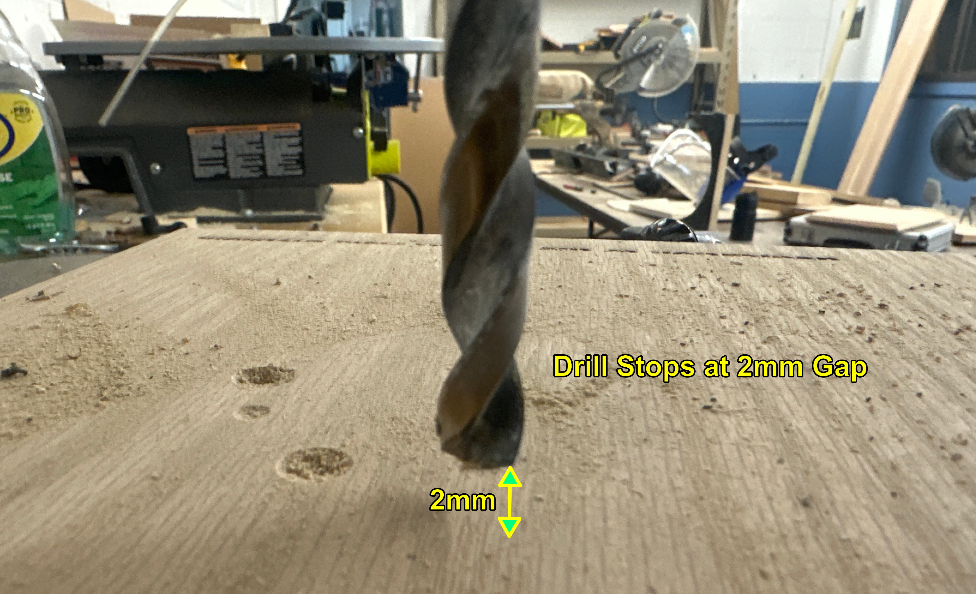
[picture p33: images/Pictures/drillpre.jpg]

</div>

If you don't have a drill press, and only have a standard drill, that's still ok.  In that case, measure the exact thickness of your Don and Ka Plates (should be 12mm-13mm) and subtract 2mm from that measurement and mark that new, lower number on your 9mm drill bit with a piece of tape. 

For example, if your Plates are exactly 13mm thick, take a piece of tape and put it on your drill bit so that the bottom edge of the tape is at exactly 11mm from the tip of the drill bit.  You'll simply drill down until the bottom of the tape is at the surface of your plate.  It is suggested to practice holes on a scrap piece of wood to make sure you have the hang of it, and that everything is working as planned.

<div align="center">
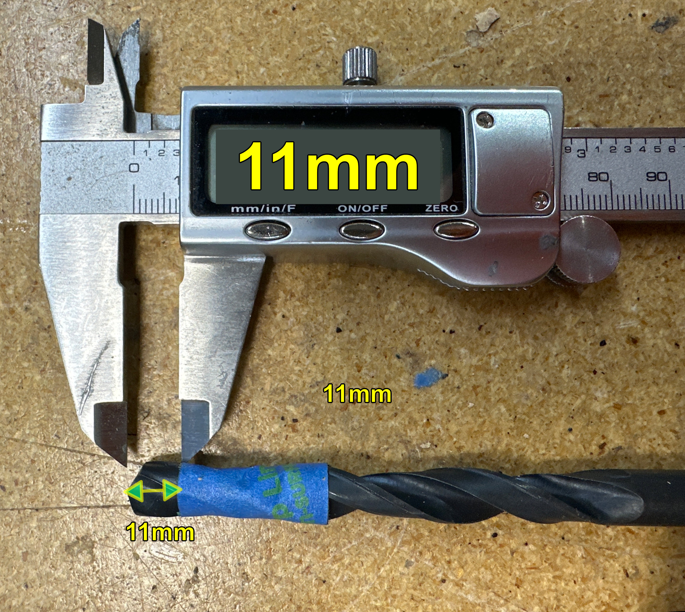
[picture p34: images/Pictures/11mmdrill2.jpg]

</div>

<div align="center">
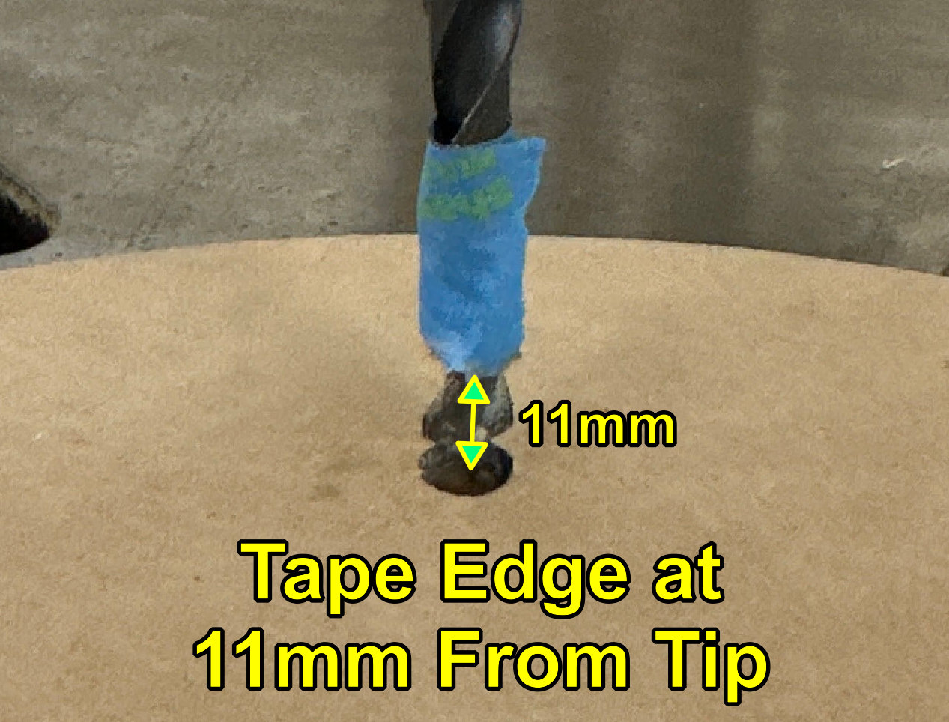
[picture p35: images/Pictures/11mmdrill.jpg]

</div>

Now that your drill depth is set, locate the 14 pre-cut **9.5mm** holes located on the underside of the top plates where the rubber grommets will go - you will be using those holes as a drill guide.

Carefully Drill **straight** down into those 9.5mm holes and turn them into new **9.5mm wide x 11mm deep** holes (or whatever your calculated depth was). **Repeat this for all 14 similar holes.**

<div align="center">
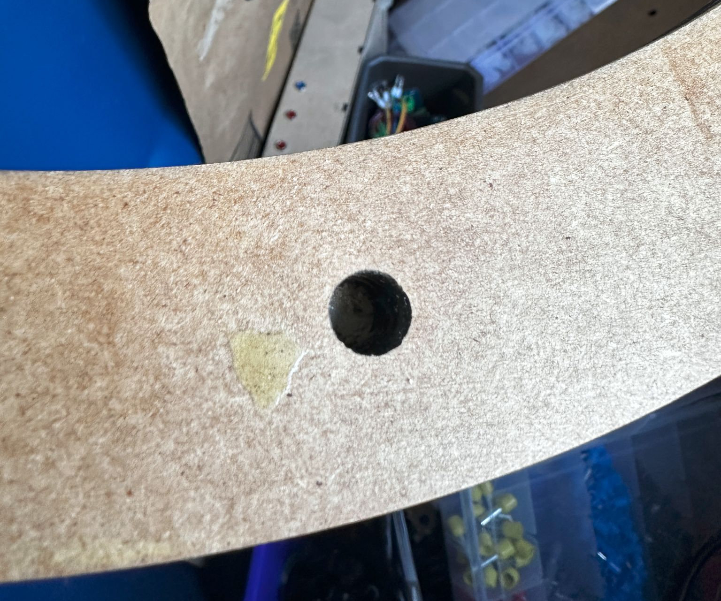
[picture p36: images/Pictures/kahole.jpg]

</div>

### **Chamfer/Bevel holes**

Using a Deburring tool, Chamfer/Bevel the (inner) rim of each of the 14 holes you just drilled hole so that the tapered head of the threaded inserts will tighten down flush and feel smooth when your fingers pass over them. This chamfering can be done with a sharp screwdriver or a sharp knife if you don't have a deburring tool. 

Additionally, if you have a drill press, or you can actually just twist the drill bit using your hand, you can use an 11mm drill bit and drill straight down into the top of your new 9.5mm holes for the depth of only about 1-2mm. This will create a chamfered rim just the same as the above steps.

Make sure you repeat this exact same process for all 14 holes.

<div align="center">
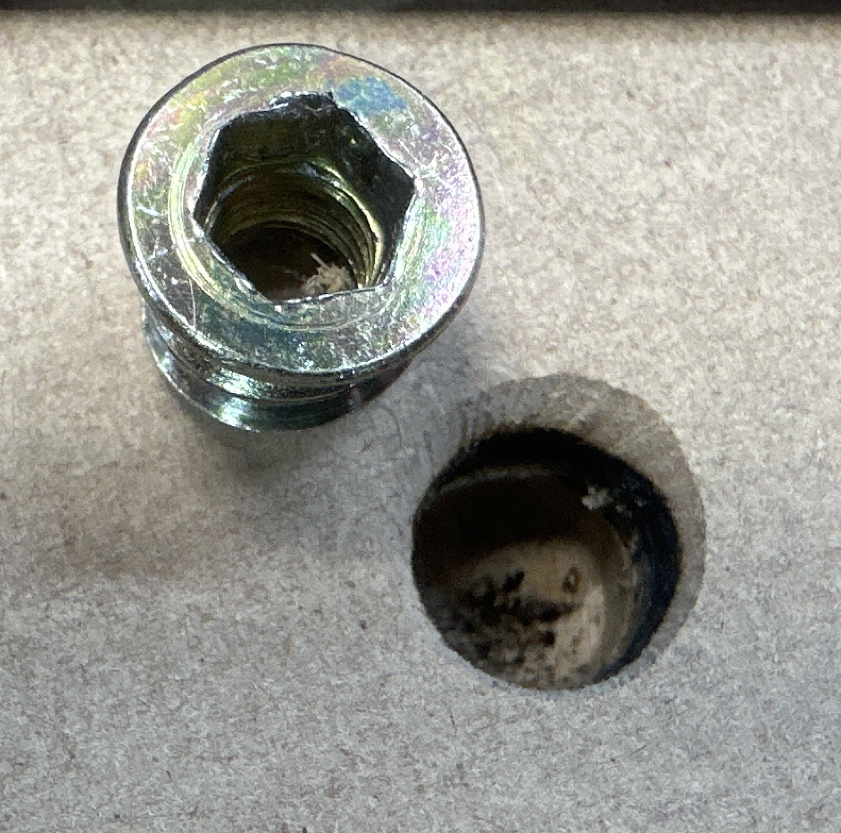
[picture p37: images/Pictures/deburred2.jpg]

</div>

<div align="center">
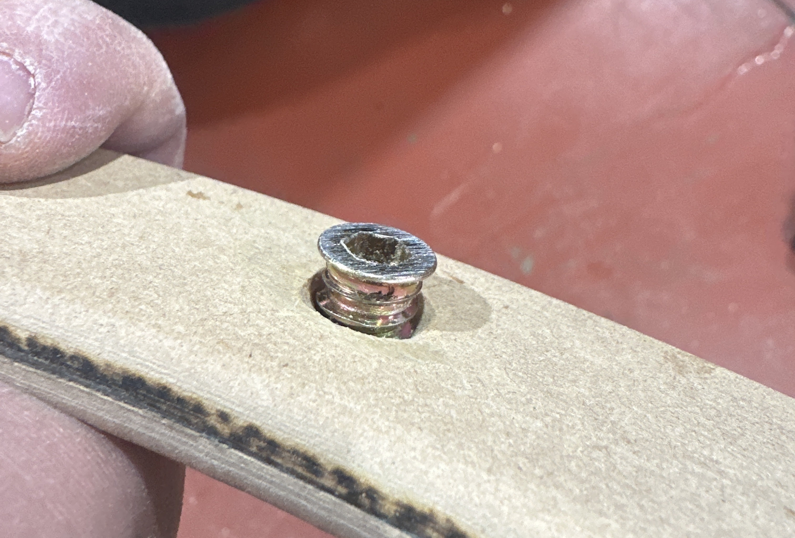
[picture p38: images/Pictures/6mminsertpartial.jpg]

</div>

### **Install the M6 threaded inserts**

Screw in the **14 individual M6 threaded wood inserts** into the corresponding holes until flush (add a drop of **Superglue** to the *outside* of threads to help permanently secure them to wood).  

If you feel that your threaded insert won't go flush, deburr a little more material to make the taper in the wood larger.

It is absolutely crucial that these threaded inserts are flush or JUST below the surface to ensure that the grommets in future steps will sit flush.

<div align="center">
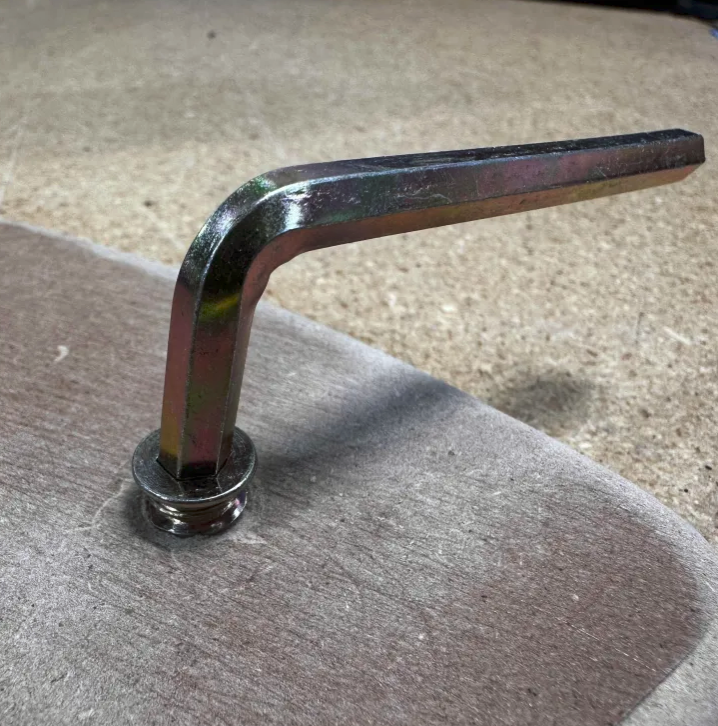
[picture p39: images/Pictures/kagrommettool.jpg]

</div>

<div align="center">
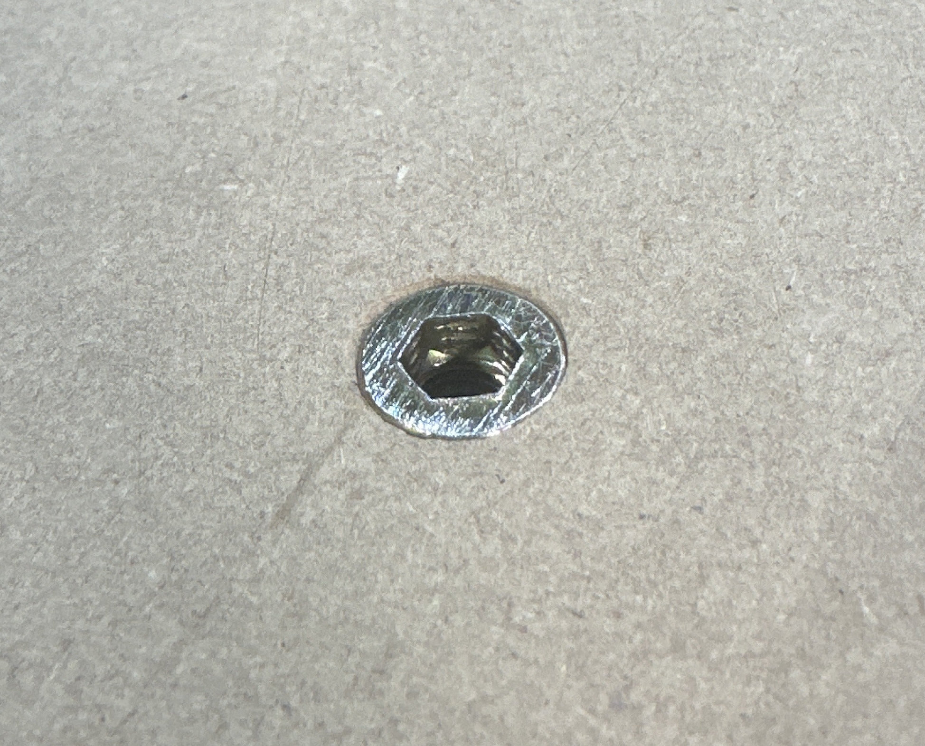
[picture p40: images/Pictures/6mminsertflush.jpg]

</div>

### **Install M3 threaded inserts into wooden faceplates**

Each faceplate has **two  4.5mm holes on the underside** where sensor housings will mount using M3 threaded inserts.  You'll be inserting a total of 8 M3x3mm threaded inserts

#### Installation

Place a small drop of superglue on the outer edge of each M3x3 threaded insert before you install it.  Rest the insert on top of the 4.5mm hole with the narrow side down, and make sure the insert is level.

<div align="center">

</div>
Using a hammer or rubber mallet, tap the insert into the wood until it's perfectly flush with the surface.  **Two M3x3mm threaded inserts** will be installed beneath each Don and Ka Top Plate.

<div align="center">

</div>

<div align="center">

</div>

This is how it will look when all M6 and M3 threaded inserts are installed:

<div align="center">

</div>

### **Prepare The Stainless Steel Mounts**

The Official Taiko Arcade Drum Controllers use large, machine-cut steel metal plates mounted to the rear of the wooden faceplates.  These metal plates add rigidity which, in turn, help absorb vibration, improve stick feedback, as well as help dampen the sound.  My original design for this project included plans to make your own metal plates, but that required heavy machinery which was extremely impractical and dangerous, not to mention, Steel plates can get very expensive.

I wouldn't let that stop me from creating the proper Arcade experience, however. I knew I needed to design a new method - a method that would replicate ALL of the benefits and feeling of the Steel Arcade Plates, without actual typical Steel Plate method.  After a few days of brainstorming, was able to create a solution that replaces the Steel Plates while retaining 100% of their benefit.

The 1/4" x 1-1/2 OD" Stainless Steel Fender Washers mounts you will be constructing in this next step is my perfect solution.  

You will still get the true arcade benefits of rigidity, vibration absorption, improved stick feedback, and sound dampening without ANY of trouble of using actual steel plates...and for only a few dollars!

#### Prepare the Stainless Steel Washer Stacks

(Note, the washers may have one side that is slightly sloped/rounded, if so, make that the top face and orient them all the same)

1. Use rubbing alcohol to clean the top and bottom surfaces of 42 1/4" x 1-1/2 OD" Stainless Steel Fender Washers .

2. Each stack will consist of 3 washers superglued together to make a single unit.

   <div align="center">
   
   </div>

3. Place 3 drops of superglue on top of one of the washers.

   <div align="center">
   
   </div>

4. Place another washer on top of the glue dots.  Hold the stack of two washers in your fingers and press them together for 30 seconds, making sure the edges stay evenly aligned.

   <div align="center">
   
   </div>

5. Place 3 drops of superglue on top of the new stack of two washers that you just fastened together.  Place the third washer on top of those new glue dots.

   <div align="center">
   
   </div>

6. Hold the new stack of three washers in your fingers and press them together for 30 seconds, making sure the edges stay evenly aligned.  This stack is complete, set it to the side.

   <div align="center">
   
   </div>

7. Repeat this until you have 14 stacks of 3 washers superglued together.

   <div align="center">
   
   </div>

8. Set these stacks off to the side and let them cure for at least 30 minutes while you assemble the rubber isolators in the next step.

## **6.3: Assemble The Rubber Isolators**

### **Cut nylon bolt head**

1. Measure 20mm of length on one of the 35mm Nylon Bolts.
2. Using a pair of cutters, cut and discard the remaining portion of the bolt that has the head attached. We will only be using the straight 20mm bolt portion for this project.
3. Repeat this process until you have 14 20mm bolts.

<div align="center">

</div>

<div align="center">

</div>

### **Apply Loctite to isolator**

Apply one drop or less of **Loctite** to threads on the inside of the rubber isolator threaded hole.

### **Install bolt in isolator**

Screw one end of the 20mm bolt into isolator until it stops.

<div align="center">

</div>

### **Apply Loctite to drum plate inserts**

Add one drop or less of **Loctite** to inside threads of the M6 threaded inserts on the bottom face of the drum plates.

### **Install isolator/Steel Washer assemblies**

(<a href="https://youtu.be/N6h3QC_hvl8?si=WZEyYCb-pd2_z-tV">HERE</a> is a timelapse video demonstrating how to mount the Isolators and Washers to the faceplate)

1. Place a washer stack over one of the 6mm threaded insert holes on the bottom of one of the faceplates.

   <div align="center">
   
   </div>

2. Feed the nylon end of the Isolator through the washer stack, and into the threaded insert.  Finger tighten and ensure that the washers do not move/spin and that there's no gap between the wood and the washers, or the washers and the grommet.

   <div align="center">
   
   </div>

3. This is how the sideview of the assembled Isolator/Washer set should look.  If there is a gap, ensure that the 6mm threaded insert is in fact flush to the wood surface.  If the washer stack IS flush, and a gap still remains, unscrew the nylon bolt from the wood, and carefully cut off an additional 1mm of length, and try again.  Repeat if necessary, only removing the smallest amount of bolt needed until everything is flush and snug.

   <div align="center">
   
   </div>

4. Repeat this step for all 14 mounting holes.

   <div align="center">
   
   </div>

## **6.4: Mount the Sensor Housings to The Drum**

(<a href="https://youtu.be/N6h3QC_hvl8?t=265">HERE</a> is a timelapse video demonstrating how to mount the sensor housings to the underside of the faceplates)

(Note: The smaller version of the sensor housings use mounting brackets that install using the same threaded-insert mounting hole spacing as the full-sized ones if you choose to go that route)

Mount your 4 completed housings to the underside of drum faces using **two M3x8mm screws** (you'll use M3x12 screws if using the smaller version of the sensors and brackets) for each housing and screwing them into the threaded inserts. Be sure that the bottom of the housing (the side with the neoprene disc glued to it) is flat against the wood.

Tighten snug so that the sensor housing is firmly pressed against the wood - but don't over-tighten.

<div align="center">

</div>

<div align="center">

</div>

Here is an example of the smaller housing with brackets mounted in the same holes:

<div align="center">

</div>

<div align="center">

</div>

Repeat this for each Don and Ka faceplate.

<div align="center">

</div>

## **6.5: Mounting The Hardware And Faceplates**

### **Mount Adjustable Speaker Plate**

1. Place your **speaker bracket** against the rear/bottom of your baseplate so aligns with the 4 pre-cut mounting holes.

2. Feed **Four M6x16 bolts** through a single 1/4" x 1-1/2 OD" Stainless Steel Fender Washer and then through the four mounting holes on the baseplate so that they come out through the speaker mounting plate holes. Use 4 M6 knobs to tightly secure the mounting plate against the rear of the Drum

<div align="center">

</div>

<div align="center">

</div>

### **Assemble Drum Faceplates to Rear Baseplate**

(<a href="https://youtu.be/N6h3QC_hvl8?t=488">HERE</a> is a timelapse video demonstrating how to mount the faceplates to the baseplate)

Now assemble the rest of the drum structure by feeding the 14 **M6x18 bolts** on the bottom of the 4 drum faces through baseplate holes of the rear baseplate. Be sure to route the sensor wires through the nearest, round cut-out in the baseplate.

<div align="center">

</div>

<div align="center">

</div>

### **Attach TRS barrel mounts**

\*\* download \*\* [`ouchitaiko_barrel_connector_mount.stl`](https://raw.githubusercontent.com/ouchitaikoproject/OuchiTaikoProject/main/download_files/ouchitaiko_barrel_connector_mount.stl) is the barrel mount STL file

1. Carefully flip the partially assembled drum over so that the drum faces don't fall out.
2. 3D print and attach **TRS barrel mounts** with adhesive tape as shown in the picture.
3. Place the four TRS couplers in the mounts. You will have one pair of barrel mounts on each side of the drum.
4. Attach the sensor wires to the top of their respective barrel connector.

<div align="center">

</div>

### **Attach the 6mm Knobs**

Attach a 6mm knob to all of the exposed bolts and tighten finger tight.  Now all 4 faceplates are securely fastened to the baseplate.

<div align="center">

</div>

### **Connect Control Box Extension cables**

Connect the ends of the coiled 3.5mm extension cables to the bottom of the Barrel Connectors.  These extension cables will eventually plug into the female TRS jacks on your Control Box. 

<div align="center">

</div>

---

# **7: Control Box Connection**

<div align="right"><sub><a href="#table-of-contents">-Back to Top-</a></sub></div>

## **7.1: Floor Stand Mode**

### **Mount drum to speaker stand**

Attach the drum and bracket to the speaker stand.

<div align="center">

</div>

### **Mount control box and connect signal wires**

Mount the control box to the phone holder arm and connect the drum TRS plugs to the matching control box TRS jacks. (This photo shows an older version of the control box, yours will be much smaller)

<div align="center">

</div>

## **7.2: Table-Top Mode**

### **Cut monitor stand tubing**

Shorten the monitor stand tube until the drum height feels right for your desk. The example shown is around `150mm`.

### **Place control box and connect wires**

Position the control box on the table and connect the drum signal wires.

### **Add drum cover**

Install an arcade drum cover if possible. Because the drum matches arcade diameter, official-style covers fit properly.

If needed, you can experiment with other materials such as:

- thin foam
- towel
- blanket
- mouse pad

Thresholds can always be adjusted later to match the cover you choose.

### **Adjust height and angle**

Set the final angle and height for comfort.

---

# **8: Flash the Firmware**

<div align="right"><sub><a href="#table-of-contents">-Back to Top-</a></sub></div>

\*\* download \*\* **Download the firmware files:**
- [`ouchitaiko_project_firmware_v1.uf2`](https://raw.githubusercontent.com/ouchitaikoproject/OuchiTaikoProject/main/download_files/ouchitaiko_project_firmware_v1.uf2)
- [`universal_flash_nuke.uf2`](https://raw.githubusercontent.com/ouchitaikoproject/OuchiTaikoProject/main/download_files/universal_flash_nuke.uf2)

## **Step 1: Enter Bootloader Mode**

Hold the **BOOT** button on the RP2040-Zero while connecting it to your PC. The board should appear as a removable `RPI-RP2` drive.

## **Step 2: Wipe the Board**

It is good practice to flash `universal_flash_nuke.uf2` before flashing the main firmware, especially when switching between builds.

1. Drag `universal_flash_nuke.uf2` onto the drive
2. Let the board reboot
3. Repeat once more if you want a completely clean start

## **Step 3: Flash the Firmware**

Drag `ouchitaiko_project_firmware_v1.uf2` onto the drive.

After the copy finishes, the board should automatically reboot into controller mode.

If it does not reboot on its own, wait a few seconds, unplug it, and reconnect it.

---

# **9: Calibration & Settings**

<div align="right"><sub><a href="#table-of-contents">-Back to Top-</a></sub></div>

## **Quick Hardware Check**

Before calibration:

1. Power the controller over USB
2. Verify the OLED turns on
3. Tap each drum lane and confirm you see hit feedback
4. Press each navigation button and confirm the correct label appears

## Guided Calibrate

The preferred calibration method is **Guided Calibrate**.

Note: Use the Web Browser/HTML method first whenever possible.

### Starting Thresholds

Start at:

- Ka Left: `225`
- Don Left: `190`
- Don Right: `190`
- Ka Right: `225`

### Build Expectations

Best results come from the intended OuchiTaiko build or another custom wooden drum that uses the same general mounting approach.

If you are not using the intended OuchiTaiko drum, make sure your drum build still does a good job reducing physical crosstalk. Sensor placement, mounting pressure, fit, adhesive use, and the drum's mechanical structure all matter. If the physical build is solid and crosstalk is well controlled, the sensors should still work perfectly fine. It may just take a little more calibration to get everything dialed in.

### Guided Calibrate (Web Tool)

1. Connect the controller over USB.
2. Put the controller in `Guided Calibrate` mode under `Controller Mode`.
3. Open the Guided Calibrate web tool using EDGE or CHROME.
4. Confirm the starting thresholds are `225 / 190 / 190 / 225`.
5. Follow the target pad shown on screen.
6. For each pad, do:
   - `5` fast normal hits
   - `1` hard hit
7. If another pad bleeds, raise only that pad and continue when prompted.
8. Repeat until the target pad stays clean.
9. Continue through all four pads.
10. Review the final thresholds.
11. Save to the controller.
12. Test in-game.

### Guided Calibrate (On-Device)

The same method is also available on the controller.

Menu path:

`Drum Tuning -> Guided Calibrate`

1. Select Guided Calibrate.
2. Read the intro and instruction screens, then follow the target pad shown on screen.
3. For each pad, do:
   - `5` fast normal hits
   - `1` hard hit
4. If bleed is detected, the controller will <b><i>automatically</i></b> raise only the offending pad and ask you to hit the same target pad again.
5. Continue until all four pads pass.
6. Review the final thresholds.
7. Save.

### Notes

- If one pad still false triggers, raise only that pad and test again.
- Good physical isolation still helps reduce crosstalk.

## **Manual Threshold Adjustment**

Use **Manual Thresholds** to fine-tune settings after testing in Guided Calibrate.

### **Access**

1. Tap **START + SELECT** together
2. Go to **Drum Tuning**
3. Select **Manual Thresholds**

### **Layout**

`KL   DL   DR   KR`

### **Controls**

| Button | Action |
| --- | --- |
| **LEFT / RIGHT** | Select drum |
| **UP / DOWN** | Adjust threshold |
| **A (EAST)** | Save |
| **B (SOUTH)** | Cancel |

### **Threshold Guide**

- lower value = more sensitive
- higher value = less sensitive
- range = `0-4095`

## **Controller Mode Selection**

Open the menu, select **Controller Mode**, choose the desired mode, and confirm with **A**. The controller will reboot automatically when the mode changes.

Available modes:

- Switch Tatacon
- Switch Pro
- PS3 Dualshock3
- PS4 Tatacon
- PS4 Dualshock4
- Keyboard Player 1
- Keyboard Player 2
- Xbox 360
- Android
- iOS
- Analog Player 1
- Analog Player 2
- MIDI Controller
- Guided Calibrate

---

# **10: Files & Downloads**

<div align="right"><sub><a href="#table-of-contents">-Back to Top-</a></sub></div>

Current download files:

- [`ouchitaiko_pcb_gerber_v1_final.zip`](https://raw.githubusercontent.com/ouchitaikoproject/OuchiTaikoProject/main/download_files/ouchitaiko_pcb_gerber_v1_final.zip) - PCB (circuit board) Gerber files
- [`ouchitaiko_laser_files.svg`](https://raw.githubusercontent.com/ouchitaikoproject/OuchiTaikoProject/main/download_files/ouchitaiko_laser_files.svg) - Wood cutting templates in SVG Format
- [`ouchitaiko_laser_files.lbrn2`](https://raw.githubusercontent.com/ouchitaikoproject/OuchiTaikoProject/main/download_files/ouchitaiko_laser_files.lbrn2) - LightBurn laser cutting project file
- [`ouchitaiko_sensor_housing.stl`](https://raw.githubusercontent.com/ouchitaikoproject/OuchiTaikoProject/main/download_files/ouchitaiko_sensor_housing.stl) - Standard size sensor housing STL
- [`ouchitaiko_sensor_housing_small.stl`](https://raw.githubusercontent.com/ouchitaikoproject/OuchiTaikoProject/main/download_files/ouchitaiko_sensor_housing_small.stl) - Smaller size sensor housing STL
- [`ouchitaiko_barrel_connector_mount.stl`](https://raw.githubusercontent.com/ouchitaikoproject/OuchiTaikoProject/main/download_files/ouchitaiko_barrel_connector_mount.stl) - TRS barrel mount STL
- [`ouchitaiko_controller_shell.stl`](https://raw.githubusercontent.com/ouchitaikoproject/OuchiTaikoProject/main/download_files/ouchitaiko_controller_shell.stl) - controller shell STL
- [`ouchitaiko_project_firmware_v1.uf2`](https://raw.githubusercontent.com/ouchitaikoproject/OuchiTaikoProject/main/download_files/ouchitaiko_project_firmware_v1.uf2) - main controller firmware
- [`universal_flash_nuke.uf2`](https://raw.githubusercontent.com/ouchitaikoproject/OuchiTaikoProject/main/download_files/universal_flash_nuke.uf2) - flash wipe/reset utility
- [`guided_calibrate.html`](https://raw.githubusercontent.com/ouchitaikoproject/OuchiTaikoProject/main/download_files/guided_calibrate.html) - web-based guided calibration tool

---

# **11: Basic Troubleshooting**

<div align="right"><sub><a href="#table-of-contents">-Back to Top-</a></sub></div>

## **OLED does not turn on**
- check OLED pin order
- inspect solder joints
- confirm the RP2040-Zero is installed correctly

## **A drum lane does not register**
- check piezo solder joints
- confirm the TRS wiring
- verify the lane components are populated on the PCB
- confirm the sensor jack is fully inserted

## **A lane causes false hits on another lane**
- switch to **Guided Calibrate**
- use the Guided Calibrate web tool
- raise the threshold of the falsely triggered lane
- retest

## **Board does not appear as `RPI-RP2`**
- reconnect while holding **BOOT**
- try another USB cable
- try another USB port

---

# **12: Menu System Reference**

<div align="right"><sub><a href="#table-of-contents">-Back to Top-</a></sub></div>

## **Quick Access**

- Tap **START + SELECT** together to open the system menu

## **Navigation Controls**

| Button | Action |
| --- | --- |
| **LEFT / RIGHT** | Navigate menu items or move between threshold fields |
| **UP / DOWN** | Adjust selected threshold |
| **EAST (A)** | Confirm / save |
| **SOUTH (B)** | Back / cancel |

## **Main Menu**

- Controller Mode
- Drum Tuning
- Advanced
- USB Flash Mode
- About

## **Drum Tuning**

- Guided Calibrate
- Manual Thresholds
- Reset Thresholds

## **Advanced**

- Reset ALL Settings
- Hold Time (Debounce)

## **Idle Screen**

When not in the menu, the OLED shows:

- current controller mode
- live drum hit feedback
- button press indicator
- menu hint text

---

# **13: About**

<div align="right"><sub><a href="#table-of-contents">-Back to Top-</a></sub></div>

This project builds on the work of several excellent open-source projects and community members.

The original firmware base, menu logic, and OSD direction were adapted from **[DonCon2040](https://github.com/ravinrabbid/DonCon2040)** by **ravinrabbid**.

Circuit inspiration came from **[HIDtaiko](https://github.com/kasasiki3/HIDtaiko/tree/master)** by **kasasiki3**.

Additional thanks:

- **Gadgetoid** for [pico-universal-flash-nuke](https://github.com/Gadgetoid/pico-universal-flash-nuke)
- **Allspice** for early prototype testing from a beginner-builder perspective as well as excellent guide formatting suggestions.
- **Moshir** for helping review the guide for clarity and flow.
- **Train** for converting my custom circuit diagram circuit into a proper Gerber file. Amazing Work!
- **Frost** for being the first user to order a PCB and assemble the complete controller.
- **Ermagerd** for testing the sensors and controller and putting it to the ultimate player test - since I feel he's the best, and most engaging live streaming Taiko Player on the Internet!

Useful community resources:

- [Taiko no Tatsujin Modding Discord](https://discord.com/invite/HFm37aA5zr)
- [Cons&Stuff :) Discord](https://discord.gg/kMBTYTmw7)
- [OpenStick Community / GP2040-CE Discord](https://discord.com/invite/openstickcommunity-1049366310389289001)

## **Closing Thoughts**

Thanks for taking the time to build OuchiTaiko.

If you have project-specific questions or suggestions, use the GitHub Discussions page. You can also ask in the Discord communities above.  I am unsure how much time I will be able to dedicate to answering questions and troubleshooting edge-case scenarios, but I will try to check in and assist when possible.

### **Spread the Word**

If you build one, share it. Tag me (`KillerQ97`) if you post your results.

Enjoy, have fun, and peace out.

[www.ouchitaiko.com](https://www.ouchitaiko.com)

---

# **14: Copyright Information**

<div align="right"><sub><a href="#table-of-contents">-Back to Top-</a></sub></div>

## **Attribution Chain**

- **Original DonCon2040 firmware:** (c) ravinrabbid (MIT License)
- **HIDtaiko components:** (c) kasasiki3 (Apache License 2.0)
- **Custom modifications and features:** Created by KillerQ

**Copyright (c) 2025 KillerQ**

## **Legal Compliance Notice**

Any distribution of this firmware, binary or source, must include:

1. the MIT license from DonCon2040
2. the Apache 2.0 license from HIDtaiko
3. copyright notices from both upstream projects
4. attribution to contributors

Repository license files:

- [LICENSE-MIT](LICENSE-MIT)
- [LICENSE-APACHE](LICENSE-APACHE)

## **Summary**

This project is transparent about its licensing and gives full credit to the upstream projects that made it possible.

Thank you to ravinrabbid and kasasiki3 for their open-source work.

**KillerQ**

[www.ouchitaiko.com](https://www.ouchitaiko.com)

---

*OuchiTaiko Project | Smarter. Simpler. Better.*

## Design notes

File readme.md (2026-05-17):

<div align="center">

</div>

---

<div align="center">
<i>In Japanese, “ouchi” means “home,” and “taiko” means “drum.”  
Together, OuchiTaiko represents the joy of bringing the arcade Taiko experience into your own space.</i>
</div>

---

# 1. Project Overview

### The Finished Build
My guide walks you through building a full arcade‑style Taiko drum controller that can be used in either **Floor‑Standing Tripod Mode** or **Table‑Top Mode**.

<div align="center">

</div>

<div align="center">

</div>

---

Hi, I’m KillerQ — creator of the **OuchiTaiko Project**, an open‑source guide for building a professional, arcade‑grade Taiko drum controller.

This project is the result of over a year of R&D focused on solving the high cost, limited availability, and inconsistent performance of commercial Taiko controllers. By combining **Adaptive Baseline Software Intelligence (ABSI)**, a custom through‑hole PCB, and a mechanically isolated sensor system, OuchiTaiko delivers arcade‑level responsiveness with approachable DIY construction.

All you need is basic soldering and woodworking skill. The linked parts are verified to work together, though compatible alternatives are welcome.

This guide is intentionally thorough — the goal is simple: **less guessing, more building.**

---

# Key Features

## World‑First Innovations

Traditional Taiko controllers often require constant threshold tuning, firmware recompiles, or compromises between sensitivity and false triggers.

**OuchiTaiko solves these issues with three core systems:**

1. Guided Calibration  
2. Adaptive Baseline Software Intelligence (ABSI)  
3. Custom Sensor Suspension System
---

### 1) Guided Calibration
OuchiTaiko includes two guided calibration options:

- HTML Guided Calibration for the preferred full setup workflow  
- on-device Guided Calibrate for the same method on the controller  
- no recompiling required  
- fast threshold refinement  
- easier crosstalk diagnosis  
- quick retesting after hardware changes  

---

### 2) Adaptive Baseline Software Intelligence (ABSI)
ABSI improves stability through software rather than complex analog circuitry.

- automatic sensitivity adjustment based on environmental noise  
- dynamic baseline tracking  
- stable long‑term behavior without drift  

---

### 3) Custom Arcade Sensor Suspension
A mechanically isolated sensor housing improves consistency and reduces noise.

Benefits include:

- More consistent hit detection  
- Reduced mechanical crosstalk  
- Cleaner signal processing  
- Long‑term durability  

---

## Complete Hardware & Features

### Standalone Testing & Display
No PC required for basic verification.

- OLED display with live feedback  
- Visual confirmation of all 14 navigation buttons  
- Live hit display and mode readout  
- Instant wiring verification using only USB power  

---

### Professional Hardware

- Custom PCB designed specifically for this project  
- 14 navigation buttons for full game control  
- Adjustable drum mounting options  
- Dedicated sensor inputs for all four drum lanes  

---

### Controller Modes

| Mode | Platform Compatibility
|---|---|
| **Switch Tatacon** | Nintendo Switch
| **Switch Pro** | Nintendo Switch 
| **PS3 Dualshock3** | PC/Steam only
| **PS4 Tatacon** | PC/Steam only
| **PS4 Dualshock4** | PC/Steam only
| **Keyboard P1** | PC
| **Keyboard P2** | PC
| **Xbox 360** | PC/Xbox
| **Android (XInput)** | Android devices
| **iOS (XInput)** | iOS devices
| **Analog P1** | PC (TaikoArcadeLoader)
| **Analog P2** | PC (TaikoArcadeLoader)
| **MIDI** | PC/DAW software
| **Debug** | Development/Testing

---

### Zero Coding Required

- Drag‑and‑drop firmware flashing  
- On‑device menus  
- No recompiling for normal setup  
- No programming knowledge needed  

---

### Demo Video

- Gameplay: https://youtu.be/p4eFeo_LB5I?si=jDKb93B7uYx1qAux

---

# 2. Parts List for Electronics

<div align="right"><sub><a href="#table-of-contents">-Back to Top-</a></sub></div>

These linked parts are verified to work together as tested.

| Item | Pieces Needed | Product Link |
| --- | --- | --- |
| Waveshare RP2040‑Zero | 1 | https://www.amazon.com/dp/B09SBCKYSC |
| 1N4148 diodes | 4 | https://www.amazon.com/dp/B0DN62QFYS |
| 0.1uF / 100nF ceramic capacitors | 4 | https://www.amazon.com/dp/B08B3VCK42 |
| 3.5mm female audio jack, PJ‑320A | 4 | https://www.amazon.com/dp/B07KY862P6 |
| 3.5mm TRS male plugs with leads | 4 | https://www.amazon.com/dp/B0D72TV7Y5 |
| 1K ohm resistor, 1/2W | 4 | https://www.amazon.com/dp/B0FP1YFMVM |
| 27mm piezo sensors | 4 | https://www.amazon.com/dp/B07RK2TQ8D |
| 128x64 mono OLED display (I2C) | 1 | https://www.amazon.com/dp/B09T6SJBV5 |
| 6mm tactile switches with caps | 14 | https://www.amazon.com/dp/B07VQF8P2Y |
| 6" coiled 3.5mm TRS extension cable | 4 | https://www.amazon.com/dp/B0D7CXJ5LQ |
| 3.5mm TRS barrel coupler | 4 | https://www.amazon.com/dp/B07YSCGBL7 |
| 6ft USB‑A to USB‑C cable | 1 | https://www.amazon.com/dp/B0CKXZML11 |

---

# 3. Parts List for Hardware

<div align="right"><sub><a href="#table-of-contents">-Back to Top-</a></sub></div>

## Required Tools & Supplies

1. Laser cutter, CNC, or alternative cutting method  
2. Soldering iron + solder  
3. Wire strippers / cutters  
4. Screwdrivers  
5. Hot glue gun  
6. Strong clamps  
7. Drill  
8. Router  
9. Sandpaper  
10. Utility knife  
11. Rubber mallet  

## Hardware Parts List

| Item | Pieces Needed | Product Link |
| --- | --- | --- |
| 1/4" (6mm) MDF, 2ft x 4ft | 2 | https://www.homedepot.com/p/1-4-in-x-2-ft-x-4-ft-MDF-1508104/202089069 |
| 1/4" x 1‑1/2" OD stainless fender washers | 46 | https://www.amazon.com/dp/B0D8ZRL1CP |
| Wood glue | 1 | https://www.amazon.com/dp/B0002YQ378 |
| M3 x 8mm bolts | 8 | https://www.amazon.com/dp/B07CMQ1SQH |
| M3 x 5mm threaded inserts | 8 | https://www.amazon.com/dp/B0CLKCQ2SH |
| M6 x 10mm wood threaded inserts | 14 | https://www.amazon.com/dp/B0CNLRFFH1 |
| M6 x 35mm nylon bolts | 14 | https://www.amazon.com/dp/B07L9ZS21T |
| M6 threaded 20mm x 15mm rubber isolators | 14 | https://www.amazon.com/dp/B0BKPHT6Y9 |
| PLA filament | 1 | https://www.amazon.com/dp/B081S5N5PC |
| Gel superglue | 1 | https://www.amazon.com/dp/B0006HUJCQ |
| Medium thread adhesive / Loctite | 1 | https://www.amazon.com/dp/B000FIXQXK |
| 2.2mm scuba knit neoprene fabric | 1 | https://www.amazon.com/dp/B0DK1B5LZ7 |
| Finger knobs with pass‑through M6 threads | 18 | https://www.amazon.com/dp/B07RW9ZH4H |
| Mini PA speaker tripod stand (optional) | 1 | https://www.amazon.com/dp/B094N9YG72 |
| Desktop monitor stand (optional) | 1 | https://www.amazon.com/dp/B072QDMRS8 |
| Adjustable angle speaker bracket | 1 | https://www.amazon.com/dp/B0DR8NCZP6 |
| Phone holder w/ gooseneck arm (optional) | 1 | https://www.amazon.com/dp/B0F32MLBZX |
| Rubber Taiko drum cover (recommended) | 1 | https://taiko.ac/products/rubber-drum-pad |
| 1/4" roundover router bit | 1 | https://www.amazon.com/dp/B0C5DVBNLS |
| Clear spray glaze / lacquer | 1 | https://www.amazon.com/dp/B00D0293SA |
| Deburring tool (optional) | 1 | https://www.amazon.com/dp/B07RM1D6WD |

---

# 4. Assemble the Control PCB

<div align="right"><sub><a href="#table-of-contents">-Back to Top-</a></sub></div>

<div align="center">

</div>

<div align="center">

</div>

## Control PCB Overview

The custom PCB integrates controller logic, display wiring, navigation buttons, and drum input circuitry into one compact board.

You will solder:

- **1× Waveshare RP2040‑Zero**  
- **14× tactile buttons**  
- **4× 1N4148 diodes**  
- **4× 1K resistors**  
- **4× 0.1uF capacitors**  
- **1× I2C OLED**  
- **4× PJ‑320A TRS jacks**

---

## Recommended Assembly Order

### Step 1: Solder Passive Components
Install:

- `R1-R4` = 1K resistors

<div align="center">

</div>

- `C1-C4` = 0.1uF capacitors

<div align="center">

</div>

- `D1-D4` = 1N4148 diodes

<div align="center">

</div>

Important: Ensure diode black bands match the silkscreen (cathode to the **left** when viewed from above).

---

### Step 2: Solder the 14 Buttons
Install all navigation buttons.

<div align="center">

</div>

The button legs will actually appear in a rectangular layout - longer on one side. The holes will match that shape - there is no polarity as long as that orientation is adhered to. Ensure each button sits flat before soldering all four legs.

---

### Step 3: Mount the OLED
Install the OLED using the following pin order (verify yours matches):

- GND  
- VCC  
- SCL  
- SDA  

<div align="center">

</div>

---

### Step 4: Install the TRS Drum Input Jacks
Install the four PJ‑320A jacks. Their pin layout only fits one orientation.

<div align="center">

</div>

---

### Step 5: Mount the RP2040‑Zero
Install the Waveshare RP2040‑Zero. Only the 20 castellated perimeter pads need soldering.

<div align="center">

</div>

A helpful soldering demonstration:  
https://youtu.be/rGvvwXrv310?t=312

---

## Inspect Your Work

Before powering on, confirm:

- RP2040‑Zero is aligned correctly  
- OLED pins are correct  
- All 14 buttons are soldered  
- All four drum lanes have resistor, capacitor, and diode installed  
- No solder bridges  
- All joints look solid  

Firmware flashing is covered in **Section 7**.

---

# **5: Build the Drum**

<div align="right"><sub><a href="#table-of-contents">-Back to Top-</a></sub></div>

**Important Scale Notice:** The SVG files provided in the download are the correct scale and should **NOT** be resized. The drum dimensions are precisely calculated to work with the sensor housings and other non-scalable components. If you try to make the drum smaller, other parts will not fit later in the project.

💡 **Scale Verification:** Before cutting, verify the SVG files are at correct scale by checking the shapes in the SVG file against the listed dimensions noted in the KEY section of that same SVG file. 

**No laser cutter or CNC access?** No worries - there are other options. Ask a friend, local shop, or check if your area has a Makerspace. Alternatively, you can print the SVG files full-size across multiple sheets of paper (ensure your printer is set to 100% scale / "Actual Size"), and then overlay the paper on your wood as a template.  You would then cut and drill by hand. Double check that your printed templates are sized properly before cutting or drilling anything.

---

## **5.1: Prepare the Wood**

### **Cut all MDF wood pieces per SVG templates**

💾 [SVG Template packet located here](#9-files--downloads)

Use your laser or CNC machine (or the method available to you) to cut out all of the wood components in the template files.

- You'll be printing one set of upper faceplates
- You'll be printing one set of lower faceplates
- You'll be printing 2x identical baseplates

<div align="center">

</div>

<div align="center">

</div>

---

### **Sand smooth as needed**

Sand down any rough edges and surfaces from the cutting step, and wipe off sawdust to prepare for gluing.

---

## **5.2: Assemble the Drum Structure**

### **Glue the rear baseplates together**

Use **wood glue** to glue the two identical rear baseplates together (they are 100% identical, just align the holes and glue together). Clamp securely or weigh down and let dry for several hours. You can also temporarily insert some 6mm bolts into the holes to ensure the two plates remain exactly aligned. Until the glue really starts to set, periodically check the plates to make sure no shifting has occurred - if so, re-align and clamp harder.

Leave the clamps and weight on for at least 6 hours. Let the glue fully cure for 24 hours before continuing past the gluing steps.

<div align="center">

</div>

<div align="center">

</div>

<div align="center">

</div>

---

### **Assemble and glue the drum faceplates together**

There will be 4 finished drum faceplates that you will be assembling during this step: Left Ka, Left Don, Right Don, and Right Ka. Each faceplate consists of TWO pieces - a smooth TOP plate along with a corresponding BOTTOM plate with holes in it.

<div align="center">

</div>

<div align="center">

</div>

**For Ka Plates:**

Let's start with the Ka plates - specifically, the Left Ka. You will be using the Left Ka TOP and the Left Ka BOTTOM plate.

Apply wood glue to the underside of the top Ka plate and apply wood glue to the topside of the lower Ka plate. Press the two pieces together and clamp or weigh them down. Until the glue really starts to set, periodically check the plates to make sure no shifting has occurred - if so, re-align and clamp harder. Leave the clamps and weight on for at least 6 hours. Let the glue fully cure for 24 hours before continuing past the gluing steps.

**Repeat this exact same process for the Right Ka.**

**For Don Plates:**

Apply wood glue to the underside of the top Don plate and apply wood glue to the topside of the lower Don plate (don't forget, each piece is exactly the same in this step only, so it is up to you which is the top part and which is the bottom part). Press the two pieces together and clamp or weigh them down. Until the glue really starts to set, periodically check the plates to make sure no shifting has occurred - if so, re-align and clamp harder. Leave the clamps and weight on for at least 6 hours. Let the glue fully cure for 24 hours before continuing past the gluing steps.

**Repeat this exact same process for the Right Don.**

When complete, you will have 4 faceplates - each consisting of a top half and a bottom half.

---
### **Sand all Don, Ka, and Baseplate Edges**
- Sand any extra glue off of the surfaces of the drum and
- Be EXTRA sure to sand off any excess glue that has dripped out of the edges/seams.  This will ensure a clean, uniform surface to work with.

<div align="center">

</div>

---
### **Rout/Chamfer all Don Ka rim edges**

Using a router and a 1/4" roundover bit, rout down every edge on the top and bottom of all glued pieces. If you don't have a router, you can use a deburring tool to lightly shave off the outer edges on the Don and Ka pieces.  Sandpaper can also achieve a similar effect.

This procedure helps prevent stick damage and wear and tear on your drum and cover, as well as gives your drum a professional, clean look by softening/rounding down all of the sharp, 90 degree edges.

<div align="center">

</div>

<div align="center">

</div>

<div align="center">

</div>

<div align="center">

</div>

<div align="center">

</div>

<div align="center">

</div>

---

### **Spray All Wood With Clear Lacquer**
You may now spray several coats of Clear Lacquer Spray Paint to the front back and sides all wood pieces.  This will help protect and seal the wood and reduce wear and tear.  Spray a single coat, let sit for 45 minutes.  Spray two more coats in a similar manner.  Let dry completely for 4 hours after the final coat before continuing.

---

### **Drill Holes For Threaded Inserts**

The following step allows the drum to be built with no visible mounting holes on the drum face. This improves aesthetics and reduces wear on sticks and the drum cover. You will drill holes into the underside of the top faceplates so the threaded inserts for the grommets can be installed from beneath and remain invisible.

The hols you will be workin with are on the underside of the bottom Drum Face Plates.

Using a Drill press, insert a **9mm** diameter drill bit (or the specialized drill bit that came with your threaded wood inserts), and set it up so that when you drill press is fully lowered, the bottom of the drill bit is exactly 2mm above your drill press plate/table.  This way, you can ensure that every time you lower the drill press, you're getting the exact depth needed each time.

<div align="center">

</div>

If you don't have a drill press, and only have a standard drill, that's still ok.  In that case, measure the exact thickness of your Don and Ka Plates (should be 12mm-13mm) and subtract 2mm from that measurement and mark that new, lower number on your 9mm drill bit with a piece of tape. 

For example, if your Plates are exactly 13mm thick, take a piece of tape and put it on your drill bit so that the bottom edge of the tape is at exactly 11mm from the tip of the drill bit.  You'll simply drill down until the bottom of the tape is at the surface of your plate.  It is suggested to practice holes on a scrap piece of wood to make sure you have the hang of it, and that everything is working as planned.

<div align="center">

</div>

<div align="center">

</div>

Now that your drill depth is set, locate the 14 pre-cut **9.5mm** holes located on the underside of the top plates where the rubber grommets will go - you will be using those holes as a drill guide.

Carefully Drill **straight** down into those 9.5mm holes and turn them into new **9.5mm wide x 11mm deep** holes (or whatever your calculated depth was). **Repeat this for all 14 similar holes.**

<div align="center">

</div>

---

### **Chamfer/Bevel holes**

Using a Deburring tool, Chamfer/Bevel the (inner) rim of each of the 14 holes you just drilled hole so that the tapered head of the threaded inserts will tighten down flush and feel smooth when your fingers pass over them. This chamfering can be done with a sharp screwdriver or a sharp knife if you don't have a deburring tool. 

Additionally, if you have a drill press, or you can actually just strist the drill bit using your hand, you can use an 11mm drill bit and drill straignt down intop the top of your new 9.5mm holes for the depth of ONLY anout 1-2mm.  this will create a chamfered rim just the same as the above steps.

Make sure you repeat this exact same process for all 14 holes.

<div align="center">

</div>

<div align="center">

</div>

---

### **Install the M6 threaded inserts**

Screw in the **14 individual M6 threaded wood inserts** into the corresponding holes until flush (add a drop of **Superglue** to the *outside* of threads to help permanently secure them to wood).  

If you feel that your threaded insert won't go flush, deburr a little more material to make the taper in the wood larger.

It is absolutely crucial that these threaded inserts are flush or JUST below the surface to ensure that the grommets in future steps will sit flush.

<div align="center">

</div>

<div align="center">

</div>

---

### **Install M3 threaded inserts into wooden faceplates**

Each faceplate has **two  4.5mm holes on the underside** where sensor housings will mount using M3 threaded inserts.  You'll be inserting a total of 8 M3x3mm threaded inserts

**Installation:**

Place a small drop of superglue on the outer edge of each M3x3 threaded insert before you install it.  Rest the insert on top of the 4.5mm hole with the narrow side down, and make sure the insert is level.

<div align="center">
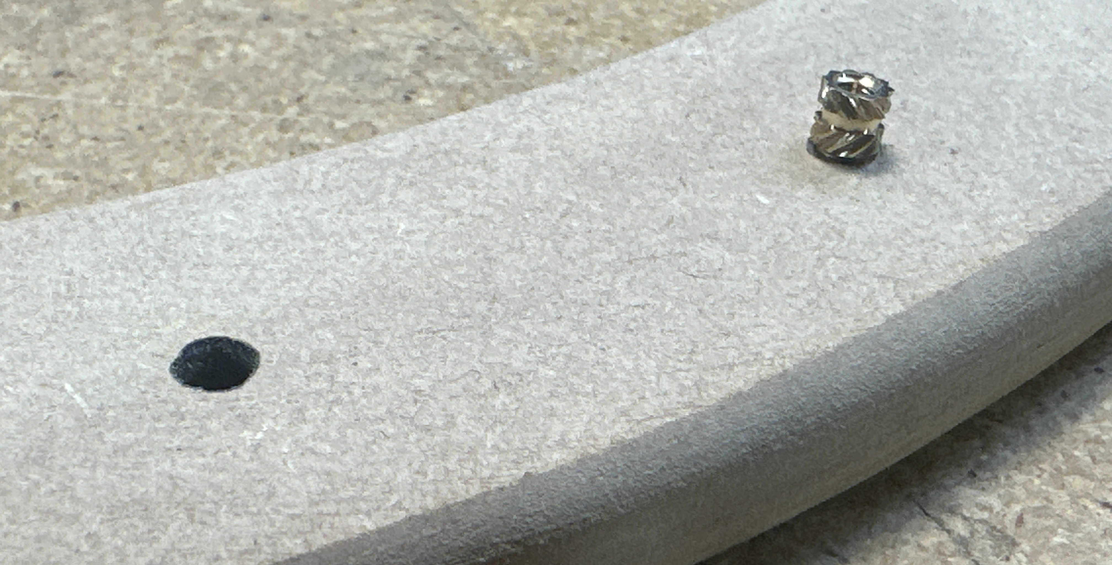
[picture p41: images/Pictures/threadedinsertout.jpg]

</div>
Using a hammer or rubber mallet, tap the insert into the wood until it's perfectly flush with the surface.  **Two M3x3mm threaded inserts** will be installed beneath each Don and Ka Top Plate.

<div align="center">
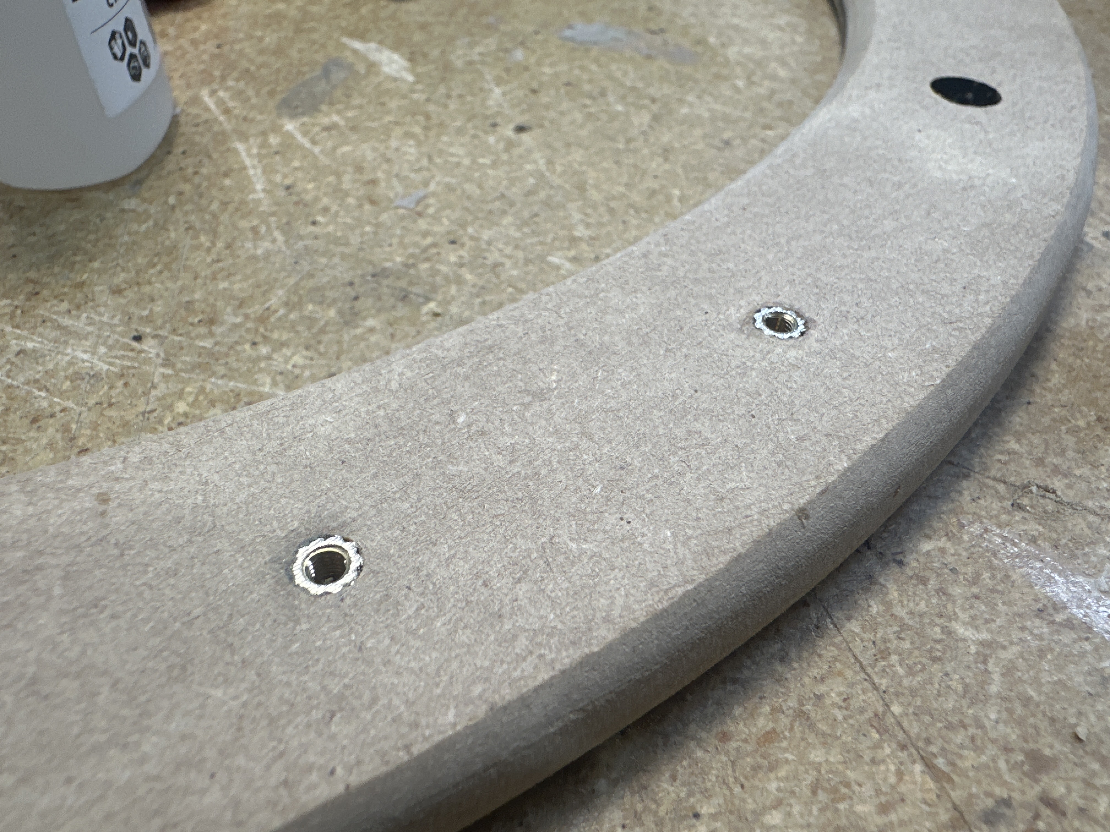
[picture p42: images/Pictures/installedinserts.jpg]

</div>

<div align="center">
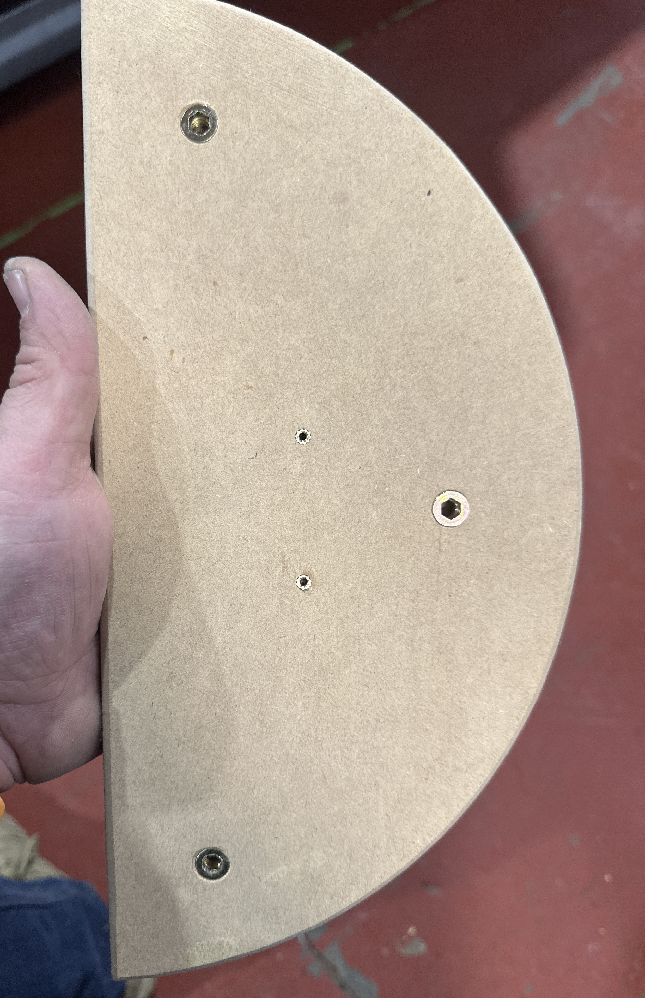
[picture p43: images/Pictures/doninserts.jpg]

</div>

This is how it will look when all M6 and M3 threaded inserts are installed:

<div align="center">
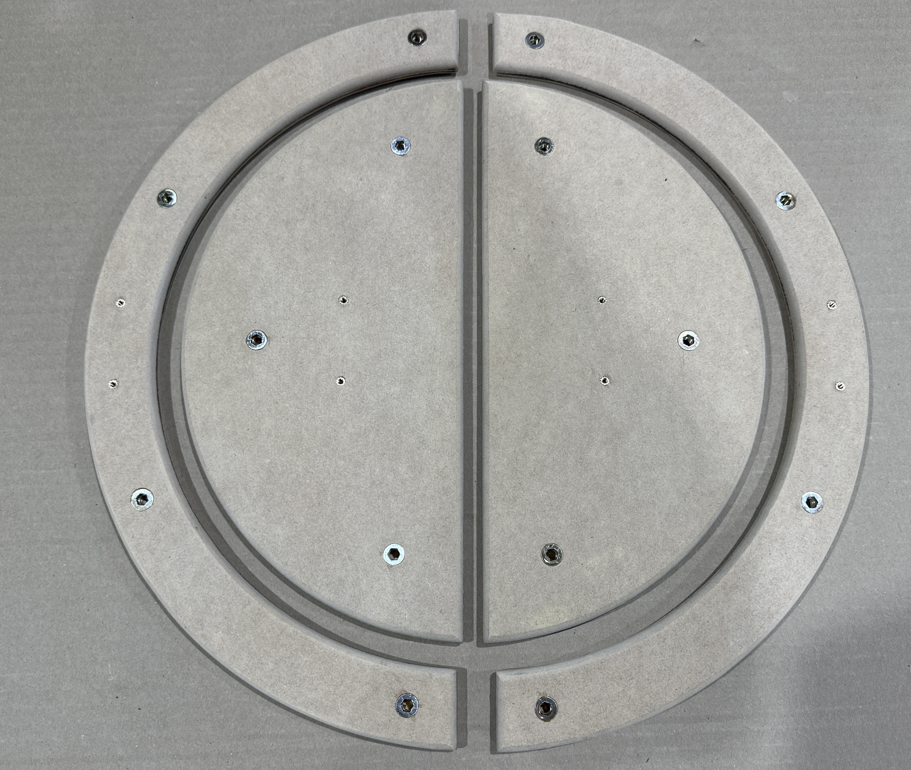
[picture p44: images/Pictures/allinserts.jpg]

</div>

---
### **Prepare The Stainless Steel Mounts**

The Official Taiko no Tatsujin Arcade Drum Controllers use large, machine-cut steel metal plates mounted to the rear of the wooden faceplates.  These metal plates add rigidity which, in turn, help absorb vibration, improve stick feedback, as well as help dampen the sound.  My original design for this project included plans to make your own metal plates, but that required heavy machinery which was extremely impractical and dangerous, not to mention, Steel plates can get very expensive.

I wouldn't let that stop me from creating the proper Arcade experience, however. I knew I needed to design a new method - a method that would replicate ALL of the benefits and feeling of the Steel Arcade Plates, without actual typical Steel Plate method.  After a few days of brainstorming, was able to create a solution that replaces the Steel Plates while retaining 100% of their benefit.

The 1/4" x 1-1/2 OD" Stainless Steel Fender Washers mounts you will be constructing in this next step is my perfect solution.  

You will still get the true arcade benefits of rigidity, vibration absorption, improved stick feedback, and sound dampening without ANY of trouble of using actual steel plates...and for only a few dollars!

**Prepare the Stainless Steel Washer Stacks:**

(Note, the washers may have one side that is slightly sloped/rounded, if so, make that the top face and orient them all the same)

1. Use rubbing alcohol to clean the top and bottom surfaces of 42 1/4" x 1-1/2 OD" Stainless Steel Fender Washers .

2. Each stack will consist of 3 washers superglued together to make a single unit.

   <div align="center">
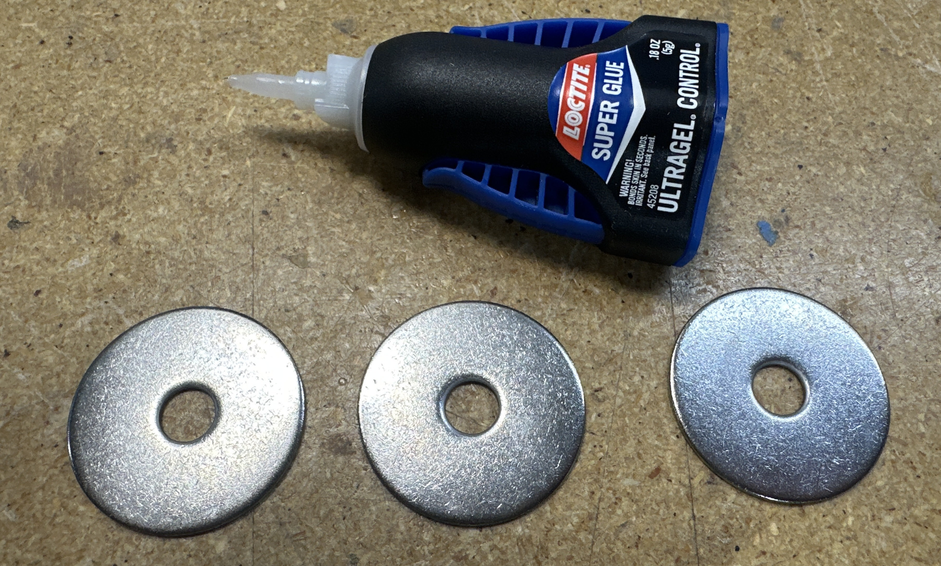
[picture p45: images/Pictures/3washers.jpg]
   
   </div>

3. Place 3 drops of superglue on top of one of the washers.

   <div align="center">
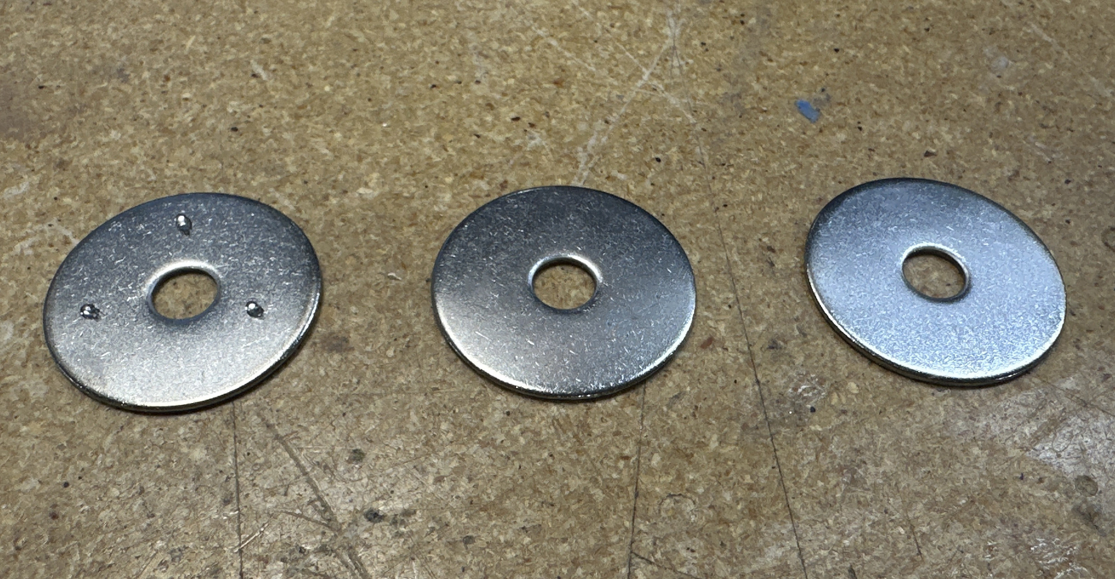
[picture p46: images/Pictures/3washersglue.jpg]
   
   </div>

4. Place another washer on top of the glue dots.  Hold the stack of two washers in your fingers and press them together for 30 seconds, making sure the edges stay evenly aligned.

   <div align="center">
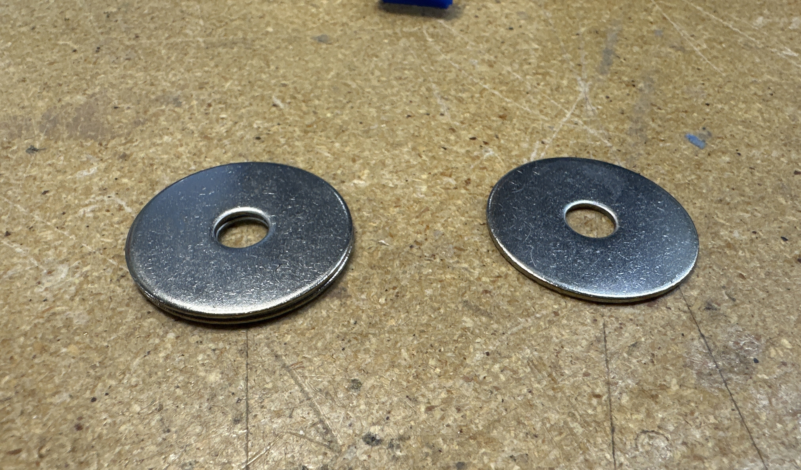
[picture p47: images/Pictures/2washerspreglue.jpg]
   
   </div>

5. Place 3 drops of superglue on top of the new stack of two washers that you just fastened together.  Place the third washer on top of those new glue dots.

   <div align="center">
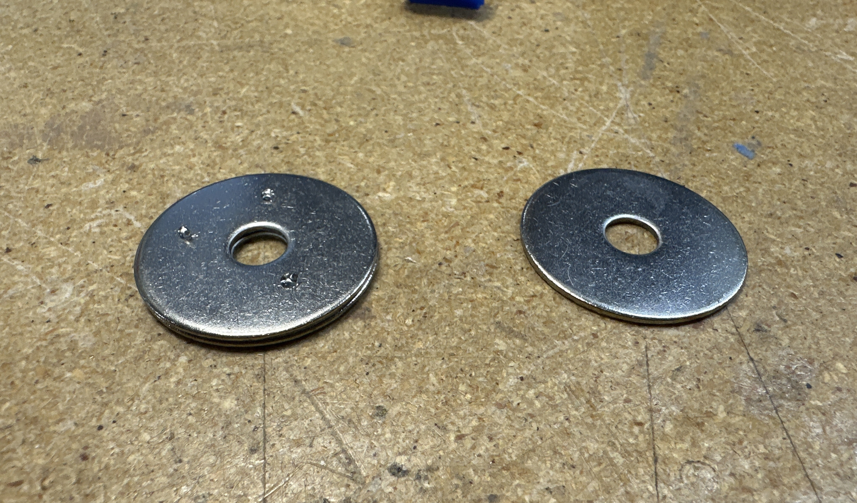
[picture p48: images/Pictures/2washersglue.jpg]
   
   </div>

6. Hold the new stack of three washers in your fingers and press them together for 30 seconds, making sure the edges stay evenly aligned.  This stack is complete, set it to the side.

   <div align="center">
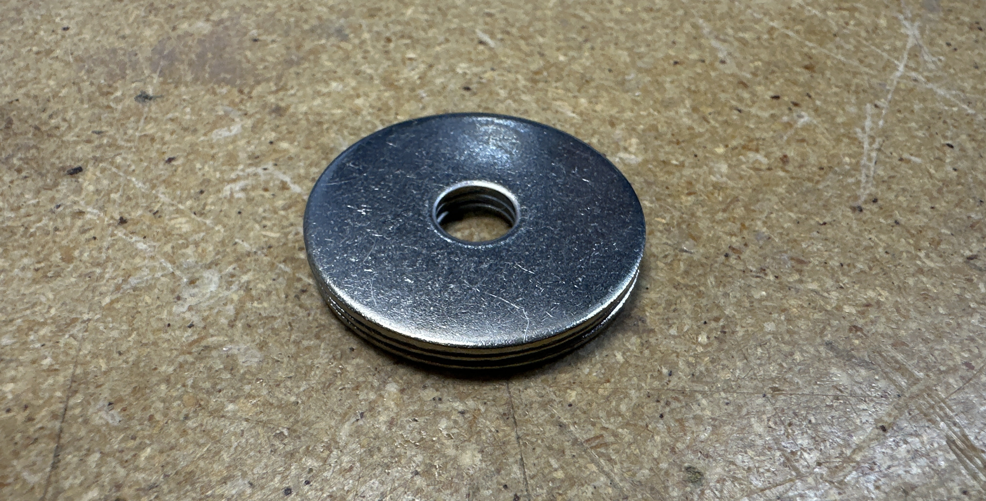
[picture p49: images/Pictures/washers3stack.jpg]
   
   </div>

7. Repeat this until you have 14 stacks of 3 washers superglued together.

   <div align="center">
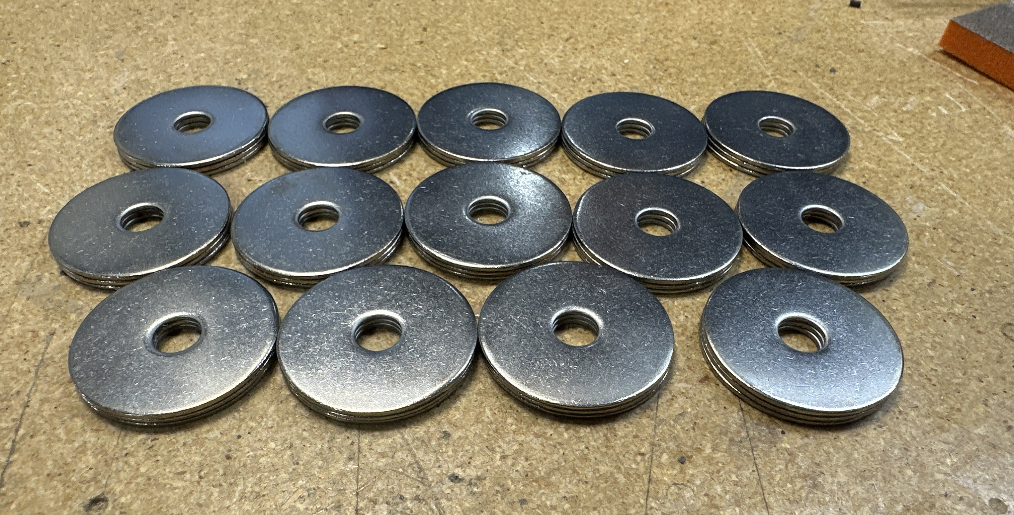
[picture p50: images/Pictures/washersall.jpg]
   
   </div>

8. Set these stacks off to the side and let them cure for at least 30 minutes while you assemble the rubber isolators in the next step.

## **5.3: Assemble The Rubber Isolators**

### **Cut nylon bolt head**

1. Measure 20mm of length on one of the 35mm Nylon Bolts.
2. Using a pair of cutters, cut and discard the remining portion of the bolt that has the head attached.  We will only be using the straight 20mm bolt portion for this project.
3. Repeat this process until you have 14 20mm bolts.

<div align="center">
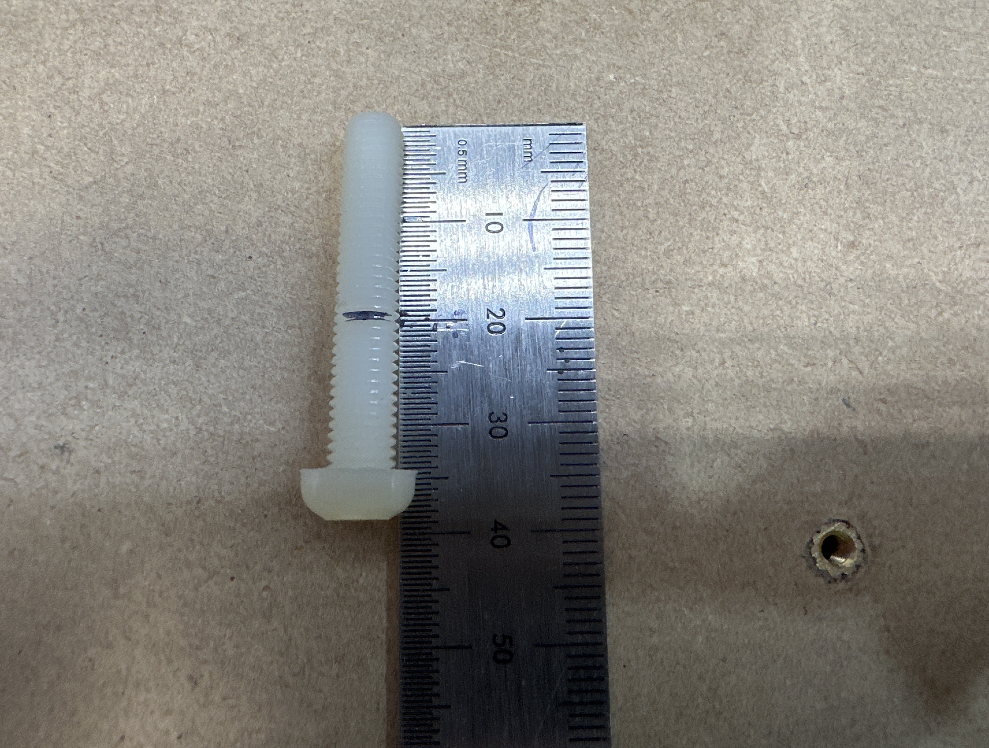
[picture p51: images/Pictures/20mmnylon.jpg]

</div>

<div align="center">
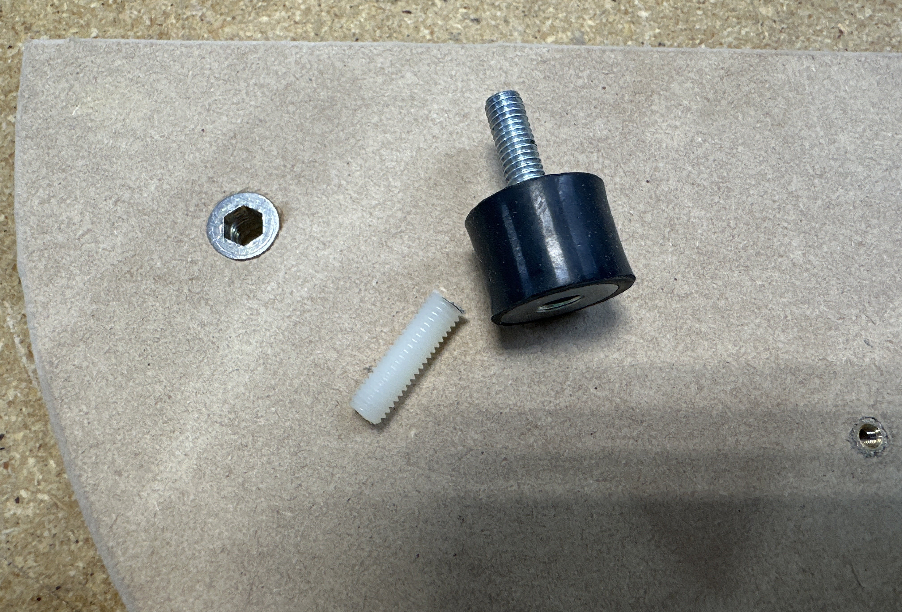
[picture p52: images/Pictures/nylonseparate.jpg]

</div>

---

### **Apply Loctite to isolator**

Apply one drop or less of **Loctite** to threads on the inside of the rubber isolator threaded hole.

---

### **Install bolt in isolator**

Screw one end of the 20mm bolt into isolator until it stops.

<div align="center">
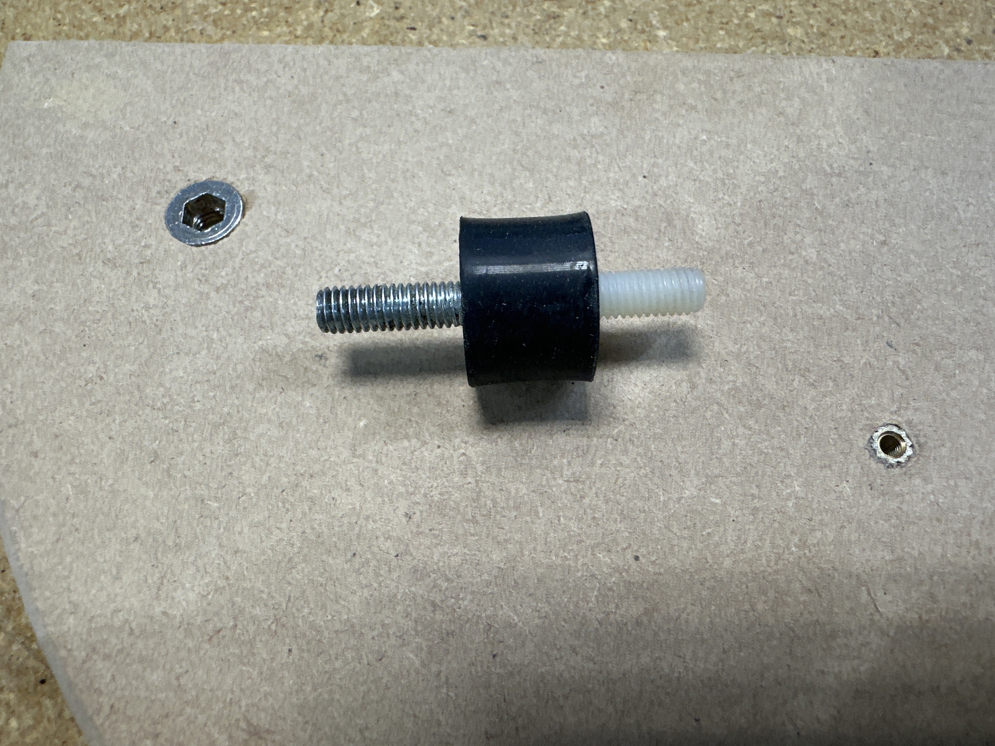
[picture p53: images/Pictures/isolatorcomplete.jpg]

</div>

---

### **Apply Loctite to drum plate inserts**

Add one drop or less of **Loctite** to inside threads of the M6 threaded inserts on the bottom face of the drum plates.

---

### **Install isolator/Steel Washer assemblies**

(<a href="[URL_GOES_HERE](https://youtu.be/N6h3QC_hvl8?si=WZEyYCb-pd2_z-tV)">HERE</a> is a timelapse video demonstrating how to mount the Isolators and Washers to to the faceplate)

1. Place a washer stack over one of the 6mm threaded insert holes on the bottom of one of the faceplates.

   <div align="center">
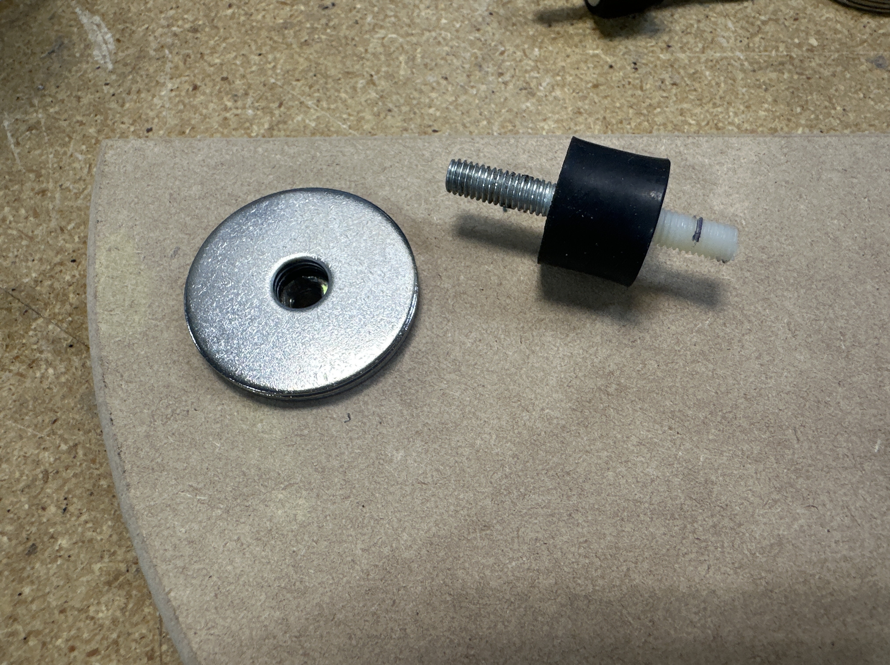
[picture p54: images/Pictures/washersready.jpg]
   
   </div>

2. Feed the nylon end of the Isolator through the washer stack, and into the threaded insert.  Finger tighten and ensure that the washers do not move/spin and that there's no gap between the wood and the washers, or the washers and the grommet.

   <div align="center">
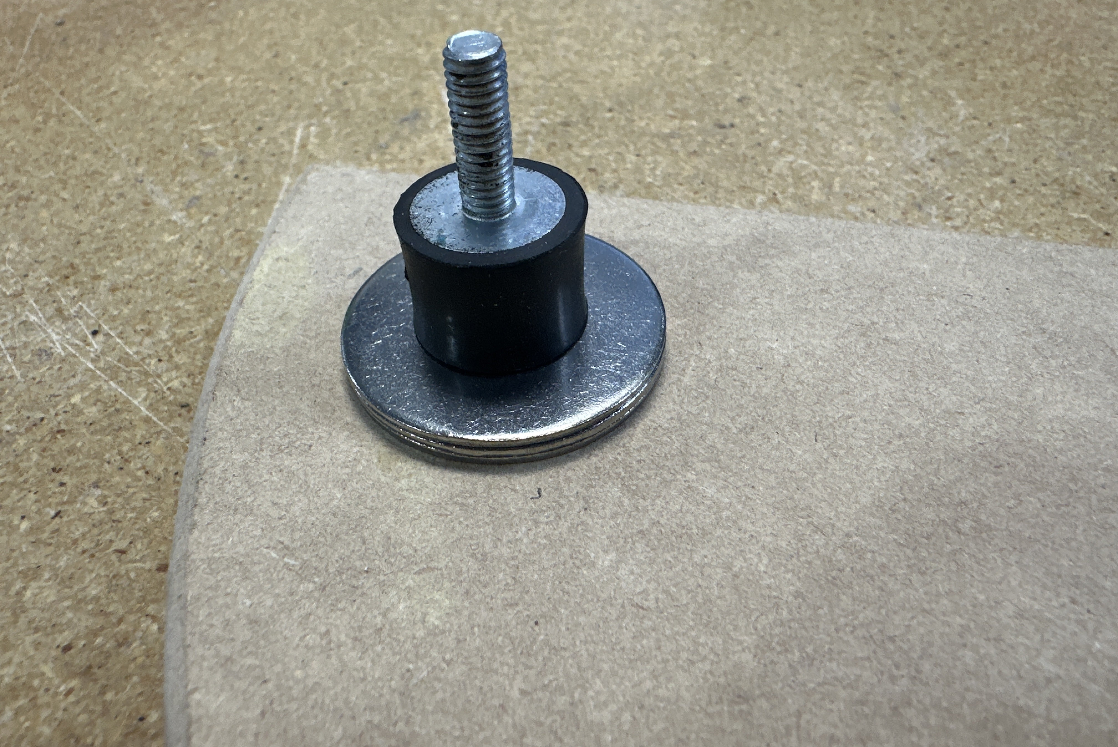
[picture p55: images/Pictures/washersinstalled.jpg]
   
   </div>

3. This is how the sideview of the assembled Isolator/Washer set should look.  If there is a gap, ensure that the 6mm threaded insert is in fact flush to the wood surface.  If the washer stack IS flush, and a gap still remains, unscrew the nylon bolt from the wood, and carefully cut off an additional 1mm of length, and try again.  Repeat if necessary, only removing the smallest amount of bolt needed until everything is flush and snug.

   <div align="center">
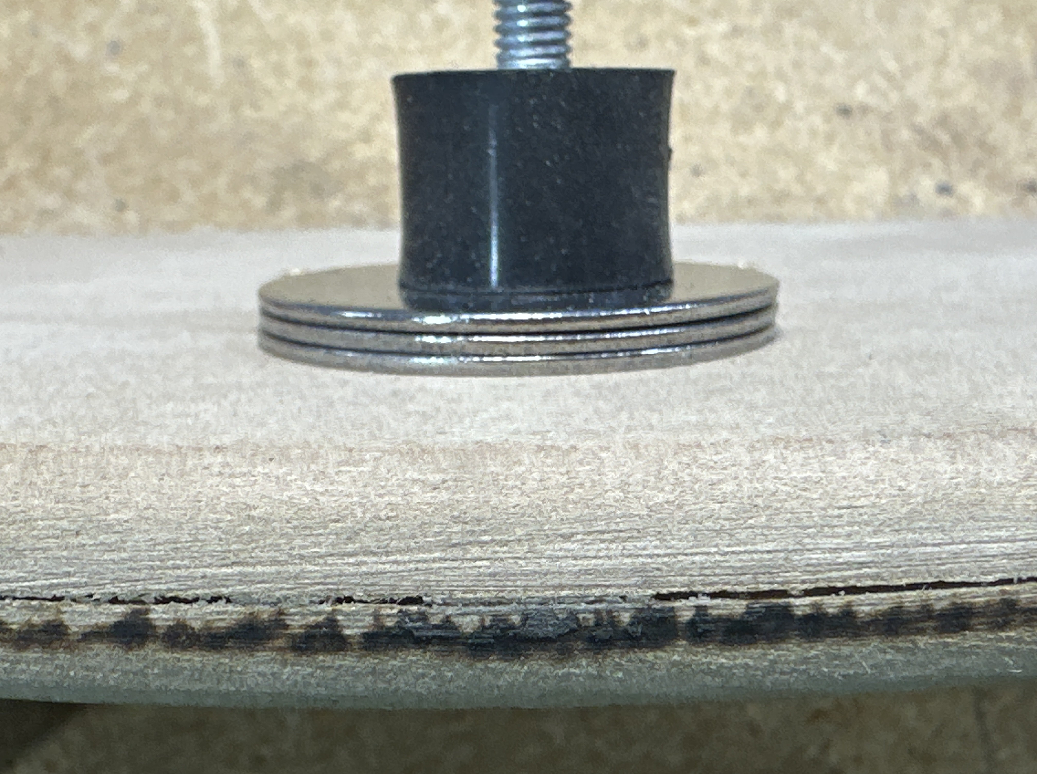
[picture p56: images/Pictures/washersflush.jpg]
   
   </div>

4. Repeat this step for all 14 mounting holes.

   <div align="center">
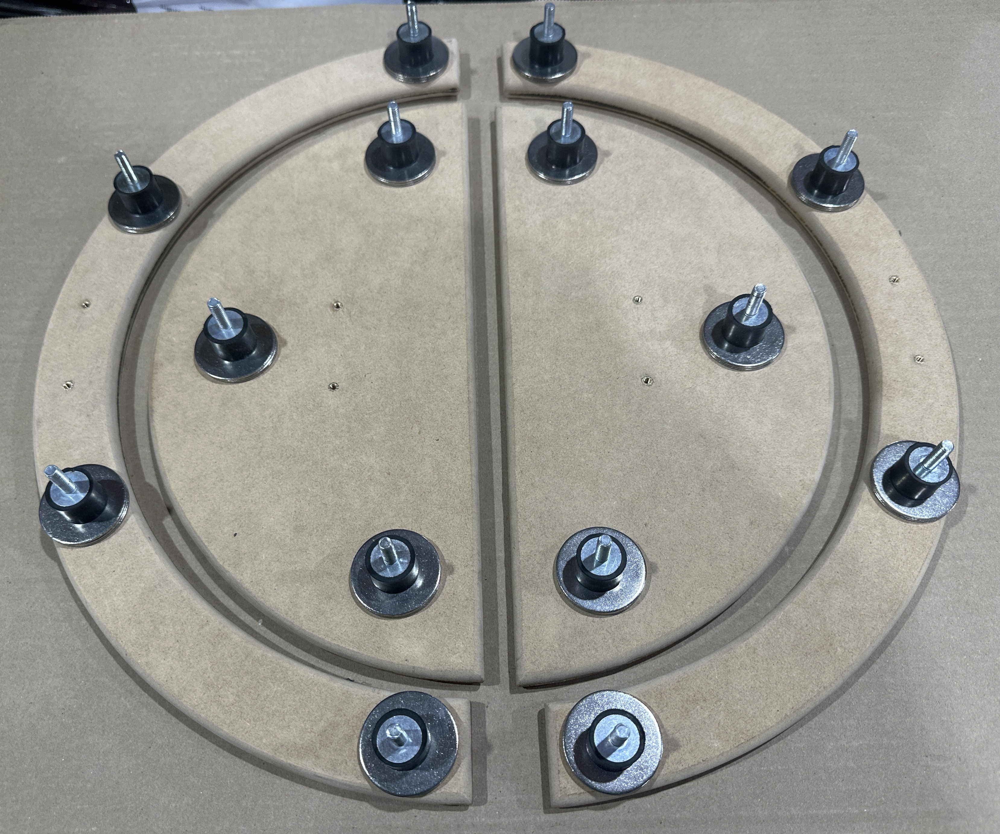
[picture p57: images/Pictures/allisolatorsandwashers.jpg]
   
   </div>

---

## **5.4: Print Sensor Housings**

### **Print The Sensor Housings**

💾 [Sensor Housing files are in the file packet here](#9-files--downloads)

Print 4 complete sets of Sensor Housings (each set has a top and bottom).

Use **PLA filament**.

**Printer Settings:** 0.2mm layer height, 40% Gyroid infill, no supports needed.

---

## **5.5: Assemble Sensor Electronics**

🎥 [Video overview of sensor housing assembly](https://youtu.be/tQe-xDEqEdY)

### **Cut neoprene discs**

Cut four **12mm neoprene discs** by using the SVG template.

💾 [Neoprene Disc Template Files are in the file packet here](#9-files--downloads)

---

### **Glue neoprene disc to housing**

Place several drops of **Superglue** into the raised center ring in the bottom shell of the housing. Place a single neoprene disc in this ring on top of the glue. Press lightly for 30 seconds.

<div align="center">

</div>

---

### **Prepare end of TRS Wire**

Cut the ends of your TRS wire so that they are approximately 10mm for the red and approximately 8mm for the black.  The difference in lenght is because you want them to be slightly offset as in this photo: 

<div align="center">

</div>

---

### **Solder to Piezo**

Now solder the **red** wire to piezo center disc, and solder the **black** wire to outer brass ring. The video linked at the beginning of this section illustrates how to do this properly.

<div align="center">

</div>

---

### **Glue Piezo to Neoprene Mount**

Add several drops of **Superglue** onto the top surface of neoprene that is already glued to the bottom housing shell. Center the **piezo sensor** face up (the all-brass side faces *down*, your wires will be on the top) onto the neoprene. Press lightly for 30 seconds. Be sure that the wire is laying across the strain relief channel portion on one side of the bottom housing channel.

💡 **Note:** Pic varies slightly from your version - this was an earlier version. You will have a more pronounced strain relief channel.

<div align="center">

</div>

<div align="center">

</div>
---

### **Enclose Housing**

Add a drop of **Superglue** to the strain relief channel *below* the wire, as well as on top, and add a few drops to the upper housing around the inside rim. Now assemble the top and bottom housing pieces together, press and hold for 30 seconds. The top shell of the housing will nest into place when aligned properly.

<div align="center">

</div>

#### **Repeat these steps so that you end up with 4 complete sensor assemblies**

---

### **Mount the Sensor Housings to The Drum**

(Here is a timelapse video demonstrating how to mount the sensor housing to the faceplates)

Mount your 4 completed housings to the underside of drum faces using **two M3x8mm screws** for each housing and screwing them into the threaded inserts. Be sure that the bottom of the housing (the side with the neoprene disc glued to it) is flast against the wood.

Tighten snug so that the sensor housing is firmly pressed against the wood - but don't over-tighten.

<div align="center">
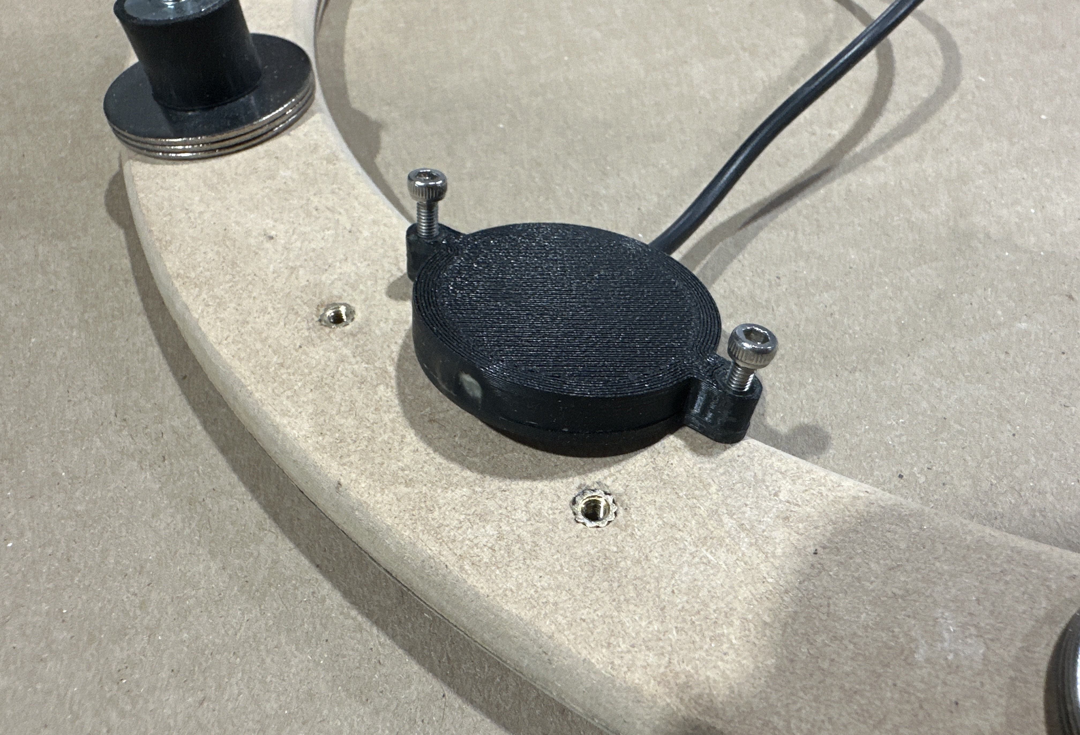
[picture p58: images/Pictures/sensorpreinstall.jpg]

</div>

<div align="center">
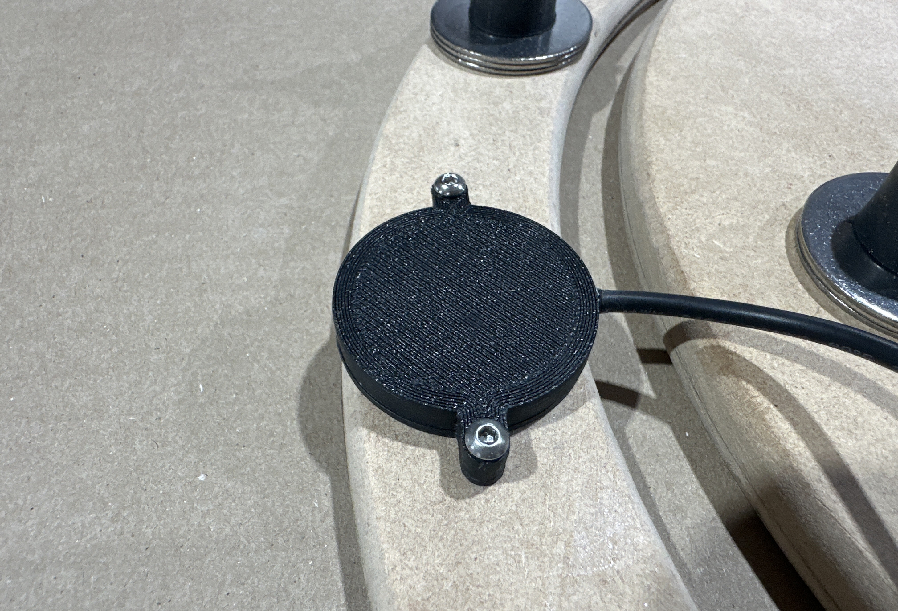
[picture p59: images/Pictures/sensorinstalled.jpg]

</div>

Repeat this for each Don and Ka faceplate.

<div align="center">
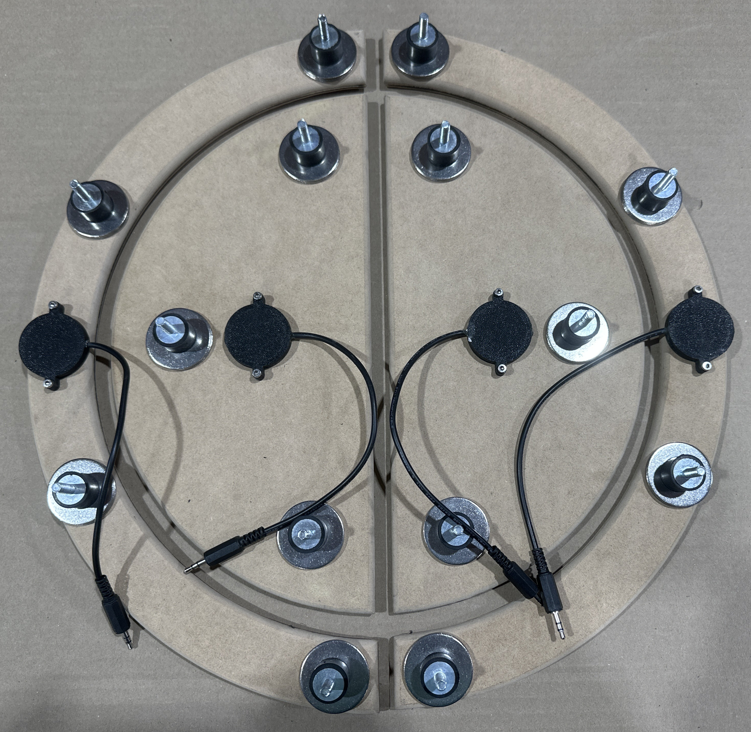
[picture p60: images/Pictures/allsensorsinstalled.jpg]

</div>

---

## **5.6: Mounting Hardware And Faceplates**

### **Mount Adjustable Speaker Plate**

1. Place your **speaker bracket** against the rear/bottom of your baseplate so aligns with the 4 pre-cut mounting holes.

2. Feed **Four M6x16 bolts** though a single 1/4" x 1-1/2 OD" Stainless Steel Fender Washer and then through the four mounting holes on the baseplate so that they come out through the speaker mounting plate holes.  Use 4 M6 knobs to tightly secure the mounting plate against the rear of the Drum

<div align="center">
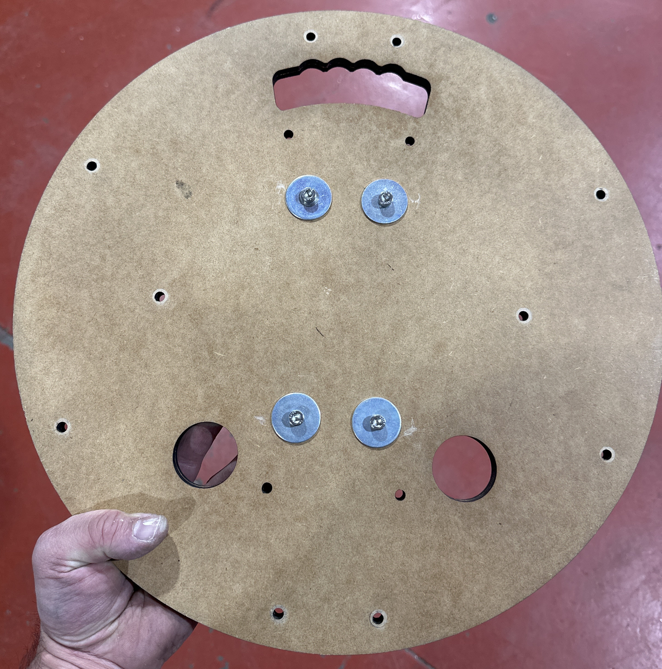
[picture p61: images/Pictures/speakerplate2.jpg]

</div>

<div align="center">
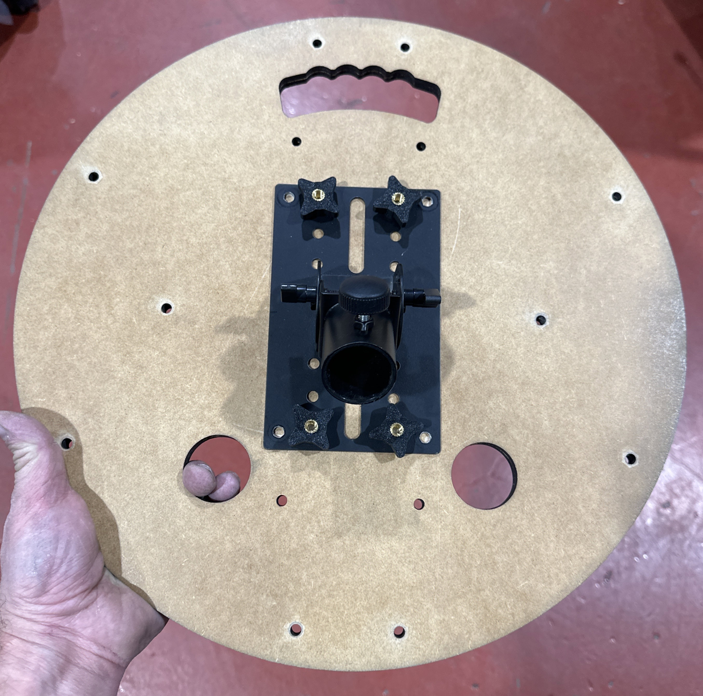
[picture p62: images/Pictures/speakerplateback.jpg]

</div>

---

### **Assemble Drum Faceplates to Rear Baseplate**

(Here is a timelapse video demonstrating how to mount the faceplates to the baseplate)

Now assemble the rest of the drum structure by feeding the 14 **M6x18 bolts** on the bottom of the 4 drum faces through baseplate holes of the rear baseplate. Be sure to route the sensor wires through the nearest, round cut-out in the baseplate.

<div align="center">
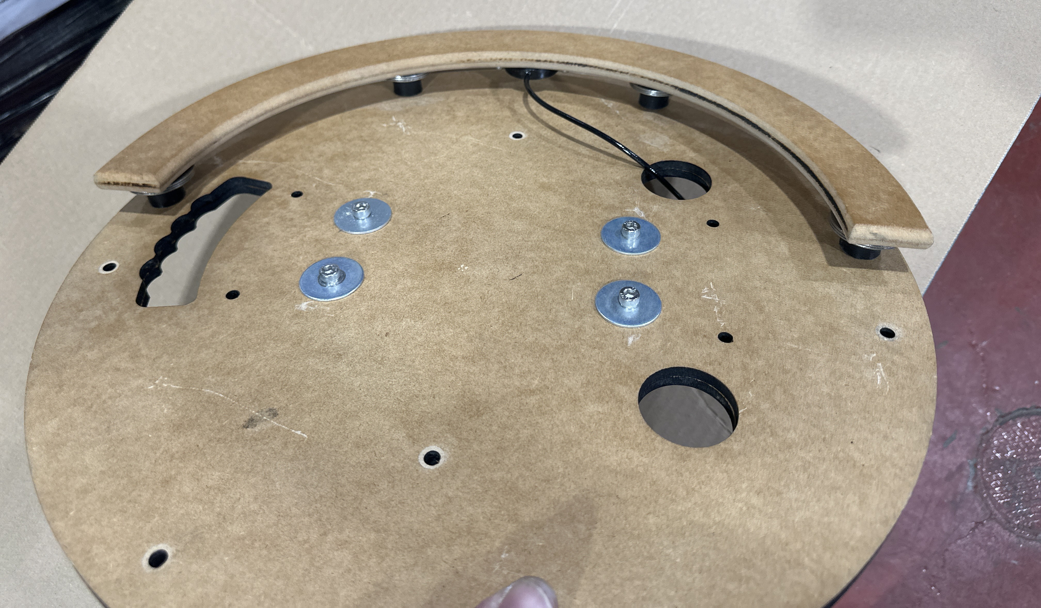
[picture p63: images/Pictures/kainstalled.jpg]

</div>

<div align="center">
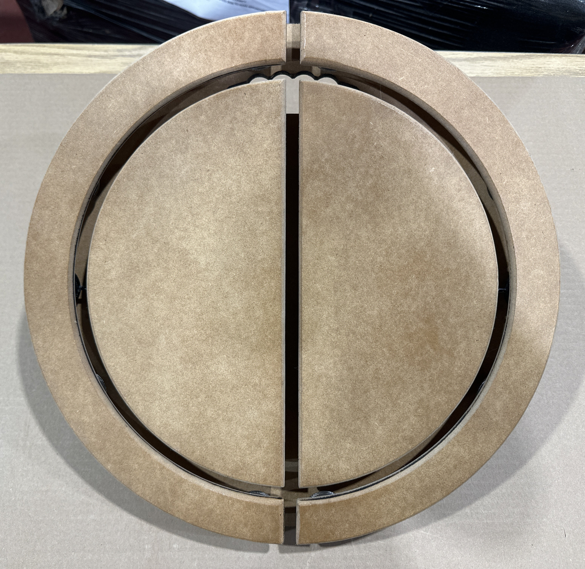
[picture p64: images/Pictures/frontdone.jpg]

</div>

---

### **Attach TRS barrel mounts**

💾 [Barrel Mount Files are in the file packet here](#9-files--downloads)

1. Carefully flip the partially assembled drum over so that the drum faces dont fall out.
2. 3D Print and Attach **TRS barrel mounts** with adhesive tape as seen in picture.

2. Place the four TRS couplers in the mounts. You will have one pair of Barrel Mounts on each side of the drum.
3. Attach the sensor wires to the top of their respective Barrel Connector

<div align="center">

</div>

---

### **Attach the 6mm Knobs**

Attach a 6mm knob to all of the exposed bolts and tighten finger tight.  Now all 4 faceplates are securely fastened to the baseplate.

<div align="center">

</div>

### **Connect Control Box Extension cables**

Connect the ends of the coiled 3.5mm extension cables to the bottom of the Barrel Connectors.  These extension cables will eventually plug into the female TRS jacks on your Control Box. 

<div align="center">

</div>

---

# **6: Control Box Connection**

<div align="right"><sub><a href="#table-of-contents">-Back to Top-</a></sub></div>

## **6.1: Floor Stand Mode**

### **Mount drum to speaker stand**

Attach the drum and bracket to the speaker stand.

<div align="center">

</div>

### **Mount control box and connect signal wires**

Mount the control box to the phone holder arm and connect the drum TRS plugs to the matching control box TRS jacks.

<div align="center">

</div>

## **6.2: Table-Top Mode**

### **Cut monitor stand tubing**

Shorten the monitor stand tube until the drum height feels right for your desk. The example shown is around `150mm`.

### **Place control box and connect wires**

Position the control box on the table and connect the drum signal wires.

### **Add drum cover**

Install an arcade drum cover if possible. Because the drum matches arcade diameter, official-style covers fit properly.

If needed, you can experiment with other materials such as:

- thin foam
- towel
- blanket
- mouse pad

Thresholds can always be adjusted later to match the cover you choose.

### **Adjust height and angle**

Set the final angle and height for comfort.

---

# **7: Flash the Firmware**

<div align="right"><sub><a href="#table-of-contents">-Back to Top-</a></sub></div>

💾 **Download the firmware files:**
- [OuchiTaiko Firmware](#9-files--downloads)
- [Flash Nuke](#9-files--downloads)

## **Step 1: Enter Bootloader Mode**

Hold the **BOOT** button on the RP2040-Zero while connecting it to your PC. The board should appear as a removable `RPI-RP2` drive.

## **Step 2: Wipe the Board**

It is good practice to flash `universal_flash_nuke.uf2` before flashing the main firmware, especially when switching between builds.

1. Drag `universal_flash_nuke.uf2` onto the drive
2. Let the board reboot
3. Repeat once more if you want a completely clean start

## **Step 3: Flash the Firmware**

Drag the OuchiTaiko `.uf2` firmware file onto the drive.

After the copy finishes, the board should automatically reboot into controller mode.

If it does not reboot on its own, wait a few seconds, unplug it, and reconnect it.

---

# **8: Calibration & Settings**

<div align="right"><sub><a href="#table-of-contents">-Back to Top-</a></sub></div>

## **Quick Hardware Check**

Before calibration:

1. Power the controller over USB
2. Verify the OLED turns on
3. Tap each drum lane and confirm you see hit feedback
4. Press each navigation button and confirm the correct label appears

## Guided Calibration

The preferred calibration method is the **HTML Guided Calibrate** page.

Use the HTML method first whenever possible.

### Starting Thresholds

Start at:

- Ka Left: `285`
- Don Left: `285`
- Don Right: `285`
- Ka Right: `285`

### HTML Guided Calibrate

1. Connect the controller over USB.
2. Put the controller in `Web Calibrate` mode.
3. Open the HTML Guided Calibrate page.
4. Confirm the thresholds are `285 / 285 / 285 / 285`.
5. Follow the target pad shown on screen.
6. For each pad, do:
   - `5` fast normal hits
   - `1` hard hit
7. If another pad bleeds, raise only that pad and retry.
8. Repeat until the target pad stays clean.
9. Continue through all four pads.
10. Review the final thresholds.
11. Save to the controller.
12. Test in-game.

### On-Device Guided Calibrate

The same method is also available on the controller.

Menu path:

`Drum Tuning -> Guided Calibrate`

1. Start Guided Calibrate.
2. Follow the target pad shown on screen.
3. For each pad, do:
   - `5` fast normal hits
   - `1` hard hit
4. If bleed is detected, retry that same pad.
5. Continue until all four pads pass.
6. Review the final thresholds.
7. Save.

### Notes

- If one pad still false triggers, raise only that pad and test again.
- Good physical isolation still helps reduce crosstalk.

## **Manual Threshold Adjustment**

Use **Manual Thresholds** to fine-tune settings after testing in the HTML calibration page.

### **Access**

1. Hold **SELECT** for 1 second
2. Go to **Drum Tuning**
3. Select **Manual Thresholds**

### **Layout**

`KL   DL   DR   KR`

### **Controls**

| Button | Action |
| --- | --- |
| **LEFT / RIGHT** | Select drum |
| **UP / DOWN** | Adjust threshold |
| **A (EAST)** | Save |
| **B (SOUTH)** | Cancel |

### **Threshold Guide**

- lower value = more sensitive
- higher value = less sensitive
- range = `0-4095`

## **Controller Mode Selection**

Open the menu, select **Controller Mode**, choose the desired mode, and confirm with **A**. The controller will reboot automatically when the mode changes.

Available modes:

- Switch Tatacon
- Switch Pro
- PS3 Dualshock3
- PS4 Tatacon
- PS4 Dualshock4
- Keyboard Player 1
- Keyboard Player 2
- Xbox 360
- Android
- iOS
- Analog Player 1
- Analog Player 2
- MIDI Controller
- Web Calibrate

---

# **9: Files & Downloads**

<div align="right"><sub><a href="#table-of-contents">-Back to Top-</a></sub></div>

Add your file packet links here:

- firmware `.uf2`
- `universal_flash_nuke.uf2`
- SVG templates
- sensor housings
- barrel mounts
- neoprene template
- HTML calibration page

---

# **10: Basic Troubleshooting**

<div align="right"><sub><a href="#table-of-contents">-Back to Top-</a></sub></div>

### **OLED does not turn on**
- check OLED pin order
- inspect solder joints
- confirm the RP2040-Zero is installed correctly

### **A drum lane does not register**
- check piezo solder joints
- confirm the TRS wiring
- verify the lane components are populated on the PCB
- confirm the sensor jack is fully inserted

### **A lane causes false hits on another lane**
- switch to **Web Calibrate**
- use the HTML calibration page
- raise the threshold of the falsely triggered lane
- retest

### **Board does not appear as `RPI-RP2`**
- reconnect while holding **BOOT**
- try another USB cable
- try another USB port

---

# **11: Menu System Reference**

<div align="right"><sub><a href="#table-of-contents">-Back to Top-</a></sub></div>

## **Quick Access**

- Hold **SELECT** for about 1 second to open the system menu

## **Navigation Controls**

| Button | Action |
| --- | --- |
| **LEFT / RIGHT** | Navigate menu items or move between threshold fields |
| **UP / DOWN** | Adjust selected threshold |
| **EAST (A)** | Confirm / save |
| **SOUTH (B)** | Back / cancel |

## **Main Menu**

- Controller Mode
- Drum Tuning
- Advanced
- USB Flash Mode
- About

## **Drum Tuning**

- Guided Calibrate
- Manual Thresholds
- Reset Thresholds

## **Advanced**

- Reset ALL Settings
- Hold Time (Debounce)

## **Idle Screen**

When not in the menu, the OLED shows:

- current controller mode
- live drum hit feedback
- button press indicator
- menu hint text

---

# **12: About**

<div align="right"><sub><a href="#table-of-contents">-Back to Top-</a></sub></div>

This project builds on the work of several excellent open-source projects and community members.

The original firmware base, menu logic, and OSD direction were adapted from **[DonCon2040](https://github.com/ravinrabbid/DonCon2040)** by **ravinrabbid**.

Circuit inspiration came from **[HIDtaiko](https://github.com/kasasiki3/HIDtaiko/tree/master)** by **kasasiki3**.

Additional thanks:

- **Gadgetoid** for [pico-universal-flash-nuke](https://github.com/Gadgetoid/pico-universal-flash-nuke)
- **Allspice** for early build feedback from a beginner-builder perspective
- **Moshir** for helping review the guide for clarity and flow
- **Train** for converting my hand-drawn circuit into a gorgeous Gerber File.

Useful community resources:

- [Taiko no Tatsujin Modding Discord](https://discord.com/invite/HFm37aA5zr)
- [Cons&Stuff :) Discord](https://discord.gg/qEpzyvf8DY)
- [OpenStick Community / GP2040-ce Discord](https://discord.com/invite/openstickcommunity-1049366310389289001)

## **Closing Thoughts**

Thanks for taking the time to build OuchiTaiko.

If you have project-specific questions or suggestions, use the GitHub Discussions page. You can also ask in the Discord communities above.

### **Spread the Word**

If you build one, share it. Tag me (`KillerQ97`) if you post your results.

Enjoy, have fun, and peace out.

[www.ouchitaiko.com](https://www.ouchitaiko.com)

---

# **13: Copyright Information**

<div align="right"><sub><a href="#table-of-contents">-Back to Top-</a></sub></div>

## **Attribution Chain**

- **Original DonCon2040 firmware:** (c) ravinrabbid (MIT License)
- **HIDtaiko components:** (c) kasasiki3 (Apache License 2.0)
- **Custom modifications and features:** Created by KillerQ

**Copyright (c) 2025 KillerQ**

## **Legal Compliance Notice**

Any distribution of this firmware, binary or source, must include:

1. the MIT license from DonCon2040
2. the Apache 2.0 license from HIDtaiko
3. copyright notices from both upstream projects
4. attribution to contributors

Repository license files:

- [LICENSE-MIT](LICENSE-MIT)
- [LICENSE-APACHE](LICENSE-APACHE)

## **Summary**

This project is transparent about its licensing and gives full credit to the upstream projects that made it possible.

Thank you to ravinrabbid and kasasiki3 for their open-source work.

**KillerQ**

[www.ouchitaiko.com](https://www.ouchitaiko.com)

---

*OuchiTaiko Project | Smarter. Simpler. Better.*

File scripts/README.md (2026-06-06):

<div align="center">

</div>

---

<div align="center">
*In Japanese, 'ouchi' (おうち) means 'home' and 'taiko' (太鼓) means 'drum.' Together, 'OuchiTaiko' represents the joy of bringing the authentic Taiko experience from the arcade into your own space.*
</div>

---

# **Table of Contents**
- [1: Project Overview/Unique Features](#1-project-overview)
- [2: Parts List for Electronics](#2-parts-list-for-electronics)
- [3: Parts List for Hardware](#3-parts-list-for-hardware)
- [4: Build the Circuit](#4-build-the-circuit)
- [5: Build the Drum](#5-build-the-drum)
- [6: Control Box](#6-control-box)
- [7: Flash The Firmware](#7-flash-the-firmware)
- [8: Calibration & Settings](#8-calibration--settings)
- [9: Files & Downloads](#9-files--downloads)
- [10: Basic Troubleshooting](#10-basic-troubleshooting)
- [11: Menu Tree Structure/Quick Reference](#11-menu-system-reference)
- [12: About](#12-about)
- [13: Copyright Information](#13-copyright-information)

---

# **1: Project Overview**

#### The Finished Build - You'll be building and creating this entire setup:

<div align="center">

</div>

<div align="center">

</div>

<div align="center">

</div>
<div align="center">

</div>

<div align="center">

</div>

---

Hi, I'm KillerQ, the Creator of the **OuchiTaiko Project** - an open-source build guide for a professional arcade-grade Taiko drum controller unlike anything currently available.

This guide represents 8 months of research and development, addressing the limited availability and high cost of commercial units. Using **Adaptive Baseline Software Intelligence (ABSI)**, this design achieves arcade-level performance through intelligent software instead of complex analog circuits or custom PCBs.

All you need is basic soldering and woodworking skills. The components linked in this guide work together as tested, though compatible alternatives are welcome.

Don't be worried about the length of this guide - it was purposely created that way to guide the user through every single step of the process - leaving nothing to question.  Less thinking, more doing!

---

# **Key Features**

## **World-First Innovations** 

**The following three innovations were designed and created just for this project and, as of this writing, do not exist at all in any other Taiko Drum Controllers - DIY, or Professionally manufactured.  You're among the first to enjoy their benefits!**

**The Problem:** Traditional Taiko drum controllers require manual threshold adjustments through trial-and-error, often involving recompiling firmware or endless menu tweaking. Users struggle to find the perfect balance between sensitivity (missing hits) and false triggers (ghost hits from vibrations).

**The OuchiTaiko Solution is three-fold:**

1) Auto Calibration
2) Adaptive Baseline Analysis
3) Custom Sensor Housing

### **1) Auto Calibrate - Intelligent Threshold Detection**
The **Auto Calibrate** system intelligently analyzes your actual playing style and automatically calculates optimal sensitivity settings:

✅ **Eliminates manual tweaking** - no more trial-and-error  
✅ **Prevents false triggers** - intelligent 50-point safety margins  
✅ **Adapts to you** - learns your unique playing dynamics  
✅ **Future-proof** - recalibrate anytime conditions change

### **2) Adaptive Baseline Software Intelligence (ABSI)**

Achieves superior performance through elegant software:

- **Automatic sensitivity adjustment** based on environmental noise
- **Dynamic baseline tracking** adapts to temperature, humidity, and mounting changes
- **Zero calibration drift** over time

### **3) Custom Arcade Sensor Suspension**

Drum trigger sensors use **custom-designed suspension mounting** that improves upon the ones found in the actual Japanese Arcade machines.

Proper sensor suspension ensures:
- Consistent trigger response
- Elimination of mechanical crosstalk
- Accurate hit detection
- Long-term durability under heavy play

---

## **🎮 Complete Hardware & Features**

### **Standalone Testing & Display**

**No PC required** for setup, calibration, or troubleshooting:
- **OLED display** with real-time hit feedback and animated hit icons
- **Visual confirmation** of all 14 navigation buttons
- **Live stats:** Drum hit animations, controller mode, button press indicator, menu hints
- **Instant verification** that everything is wired correctly

Calibrate and test your entire system with just USB power--see exactly what's happening before you ever plug into a console or PC.

### **Professional Hardware**

- **Custom Sensor Housing and Optimized Software:** Enhanced mechanical and electronic false-trigger isolation
- **14 Game Navigation Buttons:** Full in-game navigation regardless of game version
- **Professional Mounting:** Optimal hardware stabilization via adjustable base and, angled drum face mount

### **14 Input Modes for Maximum Compatibility**

- Nintendo Switch Tatacon (HORI NSW-079 Taiko Drum)
- Nintendo Switch Pro Controller
- Sony PS3 Dualshock3 (PC/Steam only)
- Sony PS4 Tatacon Drum (HORI PS4-095 Taiko Drum) (PC/Steam only)
- Sony PS4 Dualshock4 (PC/Steam only)
- Keyboard Player 1
- Keyboard Player 2
- Microsoft Xbox Xbox360 (XInput)
- Android (XInput)
- iOS (XInput)
- Analog Player 1 (XInput)(Compatible with TaikoArcadeLoader)
- Analog Player 2 (XInput)(Compatible with TaikoArcadeLoader)
- MIDI Controller
- Debug Mode

### **Zero Coding or Programming Required**

- **Drag-and-drop firmware** for instant setup
- **On-screen menus** for all settings and calibration
- **Automatic updates** without recompiling
- **No technical knowledge needed**--if you can follow instructions and use a soldering iron, you can build this

---

### 🎥 Demo Videos

- [Gameplay](https://youtu.be/p4eFeo_LB5I?si=jDKb93B7uYx1qAux)

---

# **2: Parts List for Electronics**

<div align="right"><sub><a href="#table-of-contents">-Back to Top-</a></sub></div>

The Amazon links reference parts that are 100% compatible when used together. You can source these items from any supplier as long as they meet the specifications.

**Important:** "Quantity" refers to the number of individual items you need, NOT the number of packages you need to order since some items come with multiple items in one package.

<div style="overflow-x: auto;">

| #  | Item | Qty | Product Link |
| -- | --- | --- | --- |
| 1  | XIAO RP2040 board (Seeed Studio) | 1 | [Link](https://www.amazon.com/dp/B0DRNTQ338) |
| 2  | GODIYMODULES MCP23017 I2C expander board | 1 | [Link](https://www.amazon.com/dp/B0DSLPRKKZ) |
| 3  | 1N4148 diodes | 4 | [Link](https://www.amazon.com/dp/B0DN62QFYS) |
| 4  | 0.1uF/100nF ceramic capacitors | 4 | [Link](https://www.amazon.com/dp/B08B3VCK42) |
| 5  | 3.5mm TRS female jacks w/ screw terminals | 4 | [Link](https://www.amazon.com/dp/B017CBTLJK) |
| 6  | 3.5mm TRS male plugs w/ standard ends | 4 | [Link](https://www.amazon.com/dp/B07Y8JGFS1) |
| 7  | 27mm piezo sensors | 4 | [Link](https://www.amazon.com/dp/B07RK2TQ8D) |
| 8  | 128x64 mono OLED display (I2C) | 1 | [Link](https://www.amazon.com/dp/B09T6SJBV5) |
| 9  | 6mm x 6mm x 8mm tactile switches | 14  | [Link](https://www.amazon.com/dp/B0827LX3FV) |
| 10 | 22 AWG Siamese wire | 1 | [Link](https://www.amazon.com/dp/B0CN76L8G3) |
| 11 | USB-C to USB-A female coupler | 1 | [Link](https://www.amazon.com/dp/B0CY314DCJ) |
| 12 | Short USB-C to USB-C extension cable | 1 | [Link](https://www.amazon.com/dp/B0DFHG5LNY) |
| 13 | 6 inch, coiled 3.5mm TRS audio extension cable (male to male) | 4 | [Link](https://www.amazon.com/dp/B0D7CXJ5LQ) |
| 14 | 3.5mm TRS barrel coupler | 4 | [Link](https://www.amazon.com/dp/B072J3LGSQ) |
| 15 | 4-pin, 0.2 inch pitch screw terminal blocks | 2 | [Link](https://www.amazon.com/dp/B098QMNHPJ) |
| 16 | 22 AWG 4-wire ribbon connection wire | 1 | [Link](https://www.amazon.com/dp/B09X47XBFS) |
| 17 | ElectroCookie circuit board (88.9mm x 96.5mm) | 1 | [Link](https://www.amazon.com/dp/B07YSCGBL7) |
| 18 | 10ft USB-A to USB-A cable | 1 | [Link](https://www.amazon.com/dp/B08FTDWPTX) |
| 19 | M2 x 3 x 3 threaded inserts | 4 | [Link](https://www.amazon.com/dp/B0FD7DQS8Y) |
| 20 | M2 x 4 bolts | 4 | [Link](https://www.amazon.com/dp/B0D3X4LJD2) |
| 21 | 22 AWG wire ferrules and crimper | 8 | [Link](https://www.amazon.com/dp/B0DRJ9CDNG) |

</div>

---

# **3: Parts List for Hardware**

<div align="right"><sub><a href="#table-of-contents">-Back to Top-</a></sub></div>

## **Required Tools and Supplies**

This guide assumes you have access to the following:

1. Laser cutter or CNC machine (or other means to cut wood)
2. Soldering iron and solder
3. Wire strippers/cutters
4. Screwdrivers
5. Hot glue gun
6. Strong clamps
7. Drill
8. Router
9. Sandpaper
10. Utility knife
11. Rubber mallet

## **Hardware Parts List**

<div style="overflow-x: auto;">

| # | Item | Qty  | Product Link |
| ---- | --- | ---- | --- |
| 1 | 6mm cabinet-grade MDF (1/4 inch thick works too). Amount needed dictated by sizes in SVG files | 1 | [Home Depot](https://www.homedepot.com/p/1-4-in-x-2-ft-x-4-ft-Medium-Density-Fiberboard-1508104/202089069) |
| 2 | 1/4" x 1-1/2" OD stainless steel fender washers | 46 | [Link](https://www.amazon.com/dp/B0D8ZRL1CP) |
| 3 | Strong wood glue | 1 | [Link](https://www.amazon.com/dp/B0002YQ378) |
| 4 | M3 x 8mm bolts | 8 | [Link](https://www.amazon.com/dp/B07CMQ1SQH) |
| 5 | M3 x 5mm threaded inserts | 8 | [Link](https://www.amazon.com/dp/B0CLKCQ2SH) |
| 6 | M6 x 10mm wood threaded inserts | 14 | [Link](https://www.amazon.com/dp/B0CNLRFFH1) |
| 7 | M6 x 35mm nylon bolts | 14 | [Link](https://www.amazon.com/dp/B07L9ZS21T) |
| 8 | M6 threaded 20mm x 15mm rubber isolators (one side M6 female, other side with M6 x 18mm bolt) | 14 | [Link](https://www.amazon.com/dp/B0BKPHT6Y9) |
| 9 | 3D printer filament (PLA) | 1 | [Link](https://www.amazon.com/dp/B081S5N5PC) |
| 10 | Gel superglue | 1 | [Link](https://www.amazon.com/dp/B0006HUJCQ) |
| 11 | Loctite thread adhesive - medium | 1 | [Link](https://www.amazon.com/dp/B000FIXQXK) |
| 12 | 2.2mm thick scuba knit neoprene fabric (only 4" x 4" total needed) | 1 | [Link](https://www.amazon.com/dp/B0DK1B5LZ7) |
| 13 | Finger knobs with pass-through M6 threads | 18 | [Link](https://www.amazon.com/dp/B07RW9ZH4H) |
| 14 | Mini PA speaker stand (or a stand with a compliant interface that matches your mount below) | 1 | [Link](https://www.amazon.com/dp/B094N9YG72) |
| 15 | Adjustable angle speaker bracket (or a compliant interface that matches your stand above) | 1 | [Link](https://www.amazon.com/dp/B0DR8NCZP6) |
| 16 | Rubber Taiko drum cover (optional but crucial for arcade feel. Any thin sound-dampening material may suffice) | 1 | [Link](https://taiko.ac/products/rubber-drum-pad) |
| 17 | Spring-loaded phone holder with gooseneck arm | 1 | [Link](https://www.amazon.com/dp/B0F32MLBZX)
| 18 | 1/4" Roundover Router Bit | 1 | [Link](https://www.amazon.com/dp/B01I1YQRTE) |
| 19 | Clear Spray Glaze/Lacquer | 1 | [Link](https://www.amazon.com/dp/B00D0293SA)
| 20 | Deburring Tool | 1 | [Link](https://www.amazon.com/dp/B07RM1D6WD)
</div>

---

# **4: Build the Circuit**

<div align="right"><sub><a href="#table-of-contents">-Back to Top-</a></sub></div>

<div align="center">

</div>

📸 **Photo Documentation Note:**
Some assembly photos show different terminal headers than what's in your parts list, and some signal wires may be routed slightly differently. Don't worry about these mismatches - the installation process is identical. You'll see the correct terminals used when you reach Step 8.

## **Circuit Overview**

This build uses a **single circuit board** design with everything mounted on one ElectroCookie double-column protoboard:

- **XIAO RP2040:** Brain of the system, handles drum sensors
- **MCP23017:** Controls OLED display and navigation buttons
- **OLED Display:** Status and menu display
- **14 Navigation Buttons:** Gamepad controls

## **Understanding Shared Rows**

The ElectroCookie protoboard has **shared rows** where multiple holes are electrically connected. This allows you to:

- Solder components into any hole in that row
- Connect wires between shared row holes without additional soldering
- Keep the build clean and organized

**When this guide specifies a hole location** (e.g., "Row D, hole 5"), you **must** use that exact hole. **When it says "any hole in the shared row,"** you have flexibility to choose the most convenient location in that shared/common row.

---

## **IMPORTANT: Board Orientation & Labeling**

This protoboard has **row letters and numbers printed on both sides**.

- **FRONT face** = Display and buttons side (use for Steps 1-2)
- **BACK face** = XIAO, MCP23017, and screw terminals side (use for Steps 3-12)

**⚠️ CRITICAL - Manufacturing Variance:**

Due to manufacturing variations within ElectroCookie production batches, **some boards MAY have reversed row labeling between front and back sides**. On affected boards, what appears as "Row A" on the FRONT may appear as "Row J" on the BACK (and vice versa).

**Before you begin:** Check your specific board's labeling on both sides. When this guide specifies a hole location (e.g., "Row D, hole 5"), **always use the row letter/number printed on the side you're currently working on**, not the opposite side.

**Example:** If the guide says to place a component in "Row E, hole 12" on the BACK face:
1. Flip to the BACK face
2. Locate the "Row E" label printed on the BACK (ignore what the front says)
3. Count to hole 12 in that row
4. Place your component

Always verify which side you're working on before placing components.

(This is not a problem, or a big deal, just be aware and make sure you don't blindly follow a step if you board is clearly labeled differently)

---

## **Step 1: Mount OLED Display (FRONT face)**

Mount the OLED display on the **top center** of the FRONT face.

**OLED Placement:**

- **Location:** Row J, holes 14-17 (FRONT face coordinates)
- **Orientation:** Screen facing up
- Solder in place

<div align="center">

</div>

**OLED Pin Locations** (Solder now, but these will be wired in Step 7):

- VCC (Row A, hole 15)
- GND (Row A, hole 14)
- SCL (Row A, hole 16)
- SDA (Row A, hole 17)

<div align="center">

</div>

---

## **Step 2: Mount Buttons (FRONT face)**

**Button Orientation:**

- Orient the buttons so that the 2 legs are horizontal on the **left and right side** (NOT top and bottom)
- For visual consistency: align all button tabs the same way (your buttons may have a top or bottom edge that looks slightly different - it is best to keep them all facing the same way for visual mounting consistency)

**CRITICAL - Use Exact Positions:**  
The table below specifies exact FRONT face hole positions. These align with the Control Box openings to ensure proper fit of the controller faceplate.

<div align="center">

</div>

Here are the exact hole locations for you to place your buttons in:

**Button Position Reference (FRONT face):**

| Button | Ground Leg Position | Signal Leg Position |
| --- | --- | --- |
| **LEFT SIDE BUTTONS**  | | |
| UP | Row E, hole 4 | Row E, hole 6 |
| Down | Row A, hole 4 | Row A, hole 6 |
| Left | Row C, hole 1 | Row C, hole 3 |
| Right | Row C, hole 7 | Row C, hole 9 |
| L | Row F, hole 1 | Row F, hole 3 |
| Select | Row A, hole 12 | Row A, hole 14 |
| Share | Row H, hole 7 | Row H, hole 9 |
| **RIGHT SIDE BUTTONS** | | |
| North | Row E, hole 27 | Row E, hole 25 |
| South | Row A, hole 27 | Row A, hole 25 |
| West | Row C, hole 24 | Row C, hole 22 |
| East | Row C, hole 30 | Row C, hole 28 |
| R | Row F, hole 30 | Row F, hole 28 |
| Start | Row A, hole 19 | Row A, hole 17 |
| Home | Row H, hole 24 | Row H, hole 22 |

**Installation:**

1. Insert each button into its specified position, bend legs behind board to hold in place
2. Solder both legs in place
3. Verify button alignment matches reference photos

<div align="center">

</div>

**CRITICAL NOTE - Prevent Signal Shorts:**  
Because of the shared row nature of the board, 2 buttons  will initially share signal rows with two other buttons—this would short without the following quick fix:

- The **NORTH Button and SOUTH button** legs will initially be sharing a row with each other

- The **UP Button and DOWN button** legs will also initially be sharing a row with each other

You will need to make a "break" in the shared row between these buttons so that the legs aren't electrically connected.

<div align="center">

</div>

<div align="center">

</div>

**Quick Fix (30 seconds per pair):**

1. Find the hole centered between the two signal legs of the two buttons
2. Remove/Scrape away copper with 3mm drill bit or knife
3. Test with multimeter: touch both signal legs - NO beep = success. If you hear a beep, remove more copper metal and try again
4. Repeat for second button pair

---

## **Step 3: Mount XIAO RP2040 (BACK face)**

**Flip board to BACK face.** 

<div align="center">

</div>

<div align="center">

</div>

**XIAO Placement:**

- Solder XIAO RP2040 on the **right side** of board using header pins or IC socket for easy removal
- Orient with **USB-C port facing left**
- **Top row of pins:** Row D, holes 1-7 (BACK face)
- **Bottom row of pins:** Row H, holes 1-7 (BACK face)

**Connect Ground:**

- Connect any pin in XIAO's **GND** shared row to the common GND rail
- Take a moment to jump/connect all GND rails together across the board

Here is a photo showing an example of the un-jumped power rails and then two photos (from and back) showing them as jumped.  This is done with a blob of solder, or a small jumper wire that is also soldered.  There are 4 total places to jump on the board used.

<div align="center">

</div>

<div align="center">

</div>

<div align="center">

</div>

---

## **Step 4: Install Drum Sensor Protection Circuits (BACK face)**

Each of the 4 drum sensors requires identical protection circuitry.

**Diode & Capacitor Placement:**

| Drum Zone | XIAO Pin | Diode Anode + Capacitor Location (BACK face) |
| --- | --- | --- |
| Left Ka | A0 | Row J, hole 7 |
| Left Don  | A1 | Row J, hole 6 |
| Right Don | A2 | Row J, hole 5 |
| Right Ka  | A3 | Row J, hole 4 |

**For Each Sensor:**

1. **Diode:** Place anode (non-striped end) of 1N4148 diode into the specific hole listed above (do not solder yet)

2. Place cathode (striped end) into GND rail hole directly below (do not solder yet)
   
   <div align="center">
   
   </div>
   
   <div align="center">
   
   </div>

3. **Capacitor:** Place either leg of 0.1uF capacitor into same hole as diode anode (do not solder yet)

4. Place other leg into same GND rail hole as the diode cathode (do not solder yet)
   
   <div align="center">
   
   </div>
   
   <div align="center">
   
   </div>

5. **Solder:** NOW, you can solder the combined diode + capacitor legs together into their respective hole. This saves space and keeps things looking clean.
   
   <div align="center">
   
   </div>

---

## **Step 5: Connect Button Grounds (BACK face)**

**Flip board as needed** - button legs are now accessible on BACK.

- Connect one leg of each button (ground leg) to GND rail
- **Recommended:** Daisy-chain grounds for cleaner routing - see reference photo for layout. Conversely, on the right set of buttons, designate the GND to all of the legs on the right side of the button (toward the left edge of the board) as ground legs.

<div align="center">

</div>

---

## **Step 6: Prepare MCP23017 Board**

**Solder Header Pins:**

1. Solder the **single row of 10 header pins** into the bottom row of holes on the MCP23017
2. This row starts with **A2** (left) and ends with **VCC** (right)
3. The double row of pins on top remains empty (for button signal connections later)

<div align="center">

</div>

---

## **Step 7: Pre-Wire I2C Lines Under MCP (BACK face)**

Before soldering/mounting the MCP23017 board onto the circuit board, pre-wire the power and I2C connections underneath where it will sit.

**Temporarily place** MCP23017 centered horizontally (Row E, holes 11-21, BACK face, double pins facing up). Note where it sits, then remove it.

<div align="center">

</div>

**Make these 4 connections underneath:**

| Connection | From (Under MCP) | To (OLED) | Purpose |
| --- | --- | --- | --- |
| VCC | Row A, hole 11 | Row A, hole 15 | Power to display |
| GND | Row A, hole 12 | Row A, hole 14 | Ground to display |
| SCL | Row A, hole 13 | Row A, hole 16 | I2C clock to display |
| SDA | Row A, hole 14 | Row A, hole 17 | I2C data to display  |

<div align="center">

</div>

(Photo shows SDA and SCL connection progress. You will also connect VCC and GND to the display in this step)

**Now mount MCP23017:**

- Place bottom single row of 10 pins into Row E, holes 11-21 (BACK face)
- Verify **VCC pin** is in Row E, hole 11
- Verify **A2 pin** is in Row E, hole 21
- Solder these header pins to the circuit board

<div align="center">

</div>

(In the above photo the VCC and GND were routed different than the guide, but work the same)

---

## **Step 8: Connect Power & Ground**

Connect/verify power and ground between XIAO, MCP23017, and display.

**Connections:**

1. **XIAO 3.3V** -> **MCP23017 VCC** -> **OLED VCC** (OLED already connected via Step 7)
2. **XIAO GND** -> **MCP23017 GND** -> **OLED GND** (OLED already connected via Step 7)
3. Verify all three components (XIAO, MCP, display) share common ground

---

## **Step 9: Connect I2C Data Lines**

<div align="center">

</div>

Connect I2C between XIAO and MCP23017.

| Connection | From XIAO | To MCP23017 |
| --- | --- | --- |
| SDA | Any pin in SDA shared row | Any pin in SDA shared row |
| SCL | Any pin in SCL shared row | Any pin in SCL shared row |

**Verify I2C connections:**

- XIAO SDA -> MCP23017 SDA -> Display SDA (all connected)
- XIAO SCL -> MCP23017 SCL -> Display SCL (all connected)

---

## **Step 10: Connect Button Signals to MCP23017 (BACK face)**

Connect button signal legs to MCP23017 pins. Button legs are accessible from the BACK face.

**Soldering Technique** (MCP holes are small):

1. **Prepare MCP holes:** Fill each MCP pin hole with small amount of solder
2. **Prepare wires:** Strip to 1-2mm max, tin the ends with solder
3. **Solder:** Place tinned wire on solder-filled hole, press iron down onto solder pad, wire sinks into solder
4. **Order:** Start with Row A pins (top), then Row B pins

**Complete Button Wiring Map:**

| Button | MCP Pin | Wire Connection |
| --- | --- | --- |
| **LEFT SIDE BUTTONS**  | | |
| UP | B0 | MCP B0 -> any hole in UP button signal shared row |
| Down | B1 | MCP B1 -> any hole in DOWN button signal shared row |
| Left | B2 | MCP B2 -> any hole in LEFT button signal shared row |
| Right | B3 | MCP B3 -> any hole in RIGHT button signal shared row  |
| L | B4 | MCP B4 -> any hole in L button signal shared row |
| Select | B5 | MCP B5 -> any hole in SELECT button signal shared row |
| Share | B6 | MCP B6 -> any hole in SHARE button signal shared row  |
| **RIGHT SIDE BUTTONS** | | |
| North | A0 | MCP A0 -> any hole in NORTH button signal shared row  |
| South | A1 | MCP A1 -> any hole in SOUTH button signal shared row  |
| West | A2 | MCP A2 -> any hole in WEST button signal shared row |
| East | A3 | MCP A3 -> any hole in EAST button signal shared row |
| R | A4 | MCP A4 -> any hole in R button signal shared row |
| Start | A5 | MCP A5 -> any hole in START button signal shared row  |
| Home | A6 | MCP A6 -> any hole in HOME button signal shared row |

**Wiring Tips:**

- Wire Row A pins first (work from closest to furthest button)
- Then wire Row B pins
- Route wires to minimize crossover and blocking

<div align="center">

</div>

<div align="center">

</div>

<div align="center">

</div>

<div align="center">

</div>

<div align="center">

</div>

The Navigation Buttons should look similar to this when complete:

<div align="center">

</div>

## **Step 11: Mount Terminal Blocks (BACK face)**

Place two 4-pin screw terminal blocks on BACK face.

**Terminal Block 1 (GND):**

- **Location:** Row A, holes 29, 27, 25, and 23 (BACK face)
- **Orientation:** Wire openings facing UP toward top of board
- Bridge all 4 pins together with solder or wire
- Connect this common GND cluster to nearest GND rail

**Terminal Block 2 (For Drum Signals):**

- **Location:** Row F, holes 30, 28, 26, and 24 (BACK face)
- **Orientation:** Wire openings facing DOWN toward bottom of board
- Leave one hole space between this block and the GND block

<div align="center">

</div>

**Label the signal block ports for easy future reference:**

- Pad 1/Left Ka (Row F, hole 24)
- Pad 2/Left Don (Row F, hole 26)
- Pad 3/Right Don (Row F, hole 28)
- Pad 4/Right Ka (Row F, hole 30)

## **Step 12: Connect Drum Signal Terminals (FRONT face)**

Connect terminal block signal pins to XIAO analog pins.

<div align="center">

</div>

<div align="center">

</div>

**Wiring Map:**

| Drum Pad  | From Terminal Block | To XIAO Pin |
| --- | --- | --- |
| Left Ka | Any hole in Row D, hole 24 shared row | A0 |
| Left Don  | Any hole in Row C, hole 26 shared row | A1 |
| Right Don | Any hole in Row B, hole 28 shared row | A2 |
| Right Ka  | Any hole in Row A, hole 30 shared row | A3 |

These screw terminals will connect to the drum sensor TRS jacks in a later step.

---

**CRITICAL: Be sure to visually go over BOTH sides of the entire completed circuit board and cut away ALL extra lengths of component legs that are still sticking through any holes.  Also make sure there are no unwanted blobs of solder or material anywhere on the board.  This is to ensure there are no unwanted electrical shorts.**

---

## **Circuit Complete!**

You now have a single-board circuit with:

✅ OLED Display  
✅ 14 Navigation Buttons  
✅ XIAO RP2040 (drum sensor controller)  
✅ MCP23017 (button/display controller)  
✅ Screw terminals for drum sensors

---

# **5: Build the Drum**

<div align="right"><sub><a href="#table-of-contents">-Back to Top-</a></sub></div>

**Important Scale Notice:** The SVG files provided in the download are the correct scale and should **NOT** be resized. The drum dimensions are precisely calculated to work with the sensor housings and other non-scalable components. If you try to make the drum smaller, other parts will not fit later in the project.

💡 **Scale Verification:** Before cutting, verify the SVG files are at correct scale by checking the shapes in the SVG file against the listed dimensions noted in the KEY section of that same SVG file. 

**No laser cutter or CNC access?** No worries - there are other options. Ask a friend, local shop, or check if your area has a Makerspace. Alternatively, you can print the SVG files full-size across multiple sheets of paper (ensure your printer is set to 100% scale / "Actual Size"), and then overlay the paper on your wood as a template.  You would then cut and drill by hand. Double check that your printed templates are sized properly before cutting or drilling anything.

---

## **5.1: Prepare the Wood**

### **Cut all MDF wood pieces per SVG templates**

💾 [SVG Template packet located here](#9-files--downloads)

Use your laser or CNC machine (or the method available to you) to cut out all of the wood components in the template files.

- You'll be printing one set of upper faceplates
- You'll be printing one set of lower faceplates
- You'll be printing 2x identical baseplates

<div align="center">

</div>

<div align="center">

</div>

---

### **Sand smooth as needed**

Sand down any rough edges and surfaces from the cutting step, and wipe off sawdust to prepare for gluing.

---

## **5.2: Assemble the Drum Structure**

### **Glue the rear baseplates together**

Use **wood glue** to glue the two identical rear baseplates together (they are 100% identical, just align the holes and glue together). Clamp securely or weigh down and let dry for several hours. You can also temporarily insert some 6mm bolts into the holes to ensure the two plates remain exactly aligned. Until the glue really starts to set, periodically check the plates to make sure no shifting has occurred - if so, re-align and clamp harder.

Leave the clamps and weight on for at least 6 hours. Let the glue fully cure for 24 hours before continuing past the gluing steps.

<div align="center">

</div>

<div align="center">

</div>

<div align="center">

</div>

---

### **Assemble and glue the drum faceplates together**

There will be 4 finished drum faceplates that you will be assembling during this step: Left Ka, Left Don, Right Don, and Right Ka. Each faceplate consists of TWO pieces - a smooth TOP plate along with a corresponding BOTTOM plate with holes in it.

<div align="center">

</div>

<div align="center">

</div>

**For Ka Plates:**

Let's start with the Ka plates - specifically, the Left Ka. You will be using the Left Ka TOP and the Left Ka BOTTOM plate.

Apply wood glue to the underside of the top Ka plate and apply wood glue to the topside of the lower Ka plate. Press the two pieces together and clamp or weigh them down. Until the glue really starts to set, periodically check the plates to make sure no shifting has occurred - if so, re-align and clamp harder. Leave the clamps and weight on for at least 6 hours. Let the glue fully cure for 24 hours before continuing past the gluing steps.

**Repeat this exact same process for the Right Ka.**

**For Don Plates:**

Apply wood glue to the underside of the top Don plate and apply wood glue to the topside of the lower Don plate (don't forget, each piece is exactly the same in this step only, so it is up to you which is the top part and which is the bottom part). Press the two pieces together and clamp or weigh them down. Until the glue really starts to set, periodically check the plates to make sure no shifting has occurred - if so, re-align and clamp harder. Leave the clamps and weight on for at least 6 hours. Let the glue fully cure for 24 hours before continuing past the gluing steps.

**Repeat this exact same process for the Right Don.**

When complete, you will have 4 faceplates - each consisting of a top half and a bottom half.

---
### **Sand all Don, Ka, and Baseplate Edges**
- Sand any extra glue off of the surfaces of the drum and
- Be EXTRA sure to sand off any excess glue that has dripped out of the edges/seams.  This will ensure a clean, uniform surface to work with.

<div align="center">

</div>

---
### **Rout/Chamfer all Don Ka rim edges**

Using a router and a 1/4" roundover bit, rout down every edge on the top and bottom of all glued pieces. If you don't have a router, you can use a deburring tool to lightly shave off the outer edges on the Don and Ka pieces.  Sandpaper can also achieve a similar effect.

This procedure helps prevent stick damage and wear and tear on your drum and cover, as well as gives your drum a professional, clean look by softening/rounding down all of the sharp, 90 degree edges.

<div align="center">

</div>

<div align="center">

</div>

<div align="center">

</div>

<div align="center">

</div>

<div align="center">

</div>

<div align="center">

</div>

---

### **Spray All Wood With Clear Lacquer**
You may now spray several coats of Clear Lacquer Spray Paint to the front back and sides all wood pieces.  This will help protect and seal the wood and reduce wear and tear.  Spray a single coat, let sit for 45 minutes.  Spray two more coats in a similar manner.  Let dry completely for 4 hours after the final coat before continuing.

---

### **Drill Holes For Threaded Inserts**

The following step allows the drum to be built with no visible mounting holes on the drum face. This improves aesthetics and reduces wear on sticks and the drum cover. You will drill holes into the underside of the top faceplates so the threaded inserts for the grommets can be installed from beneath and remain invisible.

The hols you will be workin with are on the underside of the bottom Drum Face Plates.

Using a Drill press, insert a **9mm** diameter drill bit (or the specialized drill bit that came with your threaded wood inserts), and set it up so that when you drill press is fully lowered, the bottom of the drill bit is exactly 2mm above your drill press plate/table.  This way, you can ensure that every time you lower the drill press, you're getting the exact depth needed each time.

<div align="center">

</div>

If you don't have a drill press, and only have a standard drill, that's still ok.  In that case, measure the exact thickness of your Don and Ka Plates (should be 12mm-13mm) and subtract 2mm from that measurement and mark that new, lower number on your 9mm drill bit with a piece of tape. 

For example, if your Plates are exactly 13mm thick, take a piece of tape and put it on your drill bit so that the bottom edge of the tape is at exactly 11mm from the tip of the drill bit.  You'll simply drill down until the bottom of the tape is at the surface of your plate.  It is suggested to practice holes on a scrap piece of wood to make sure you have the hang of it, and that everything is working as planned.

<div align="center">

</div>

<div align="center">

</div>

Now that your drill depth is set, locate the 14 pre-cut **9.5mm** holes located on the underside of the top plates where the rubber grommets will go - you will be using those holes as a drill guide.

Carefully Drill **straight** down into those 9.5mm holes and turn them into new **9.5mm wide x 11mm deep** holes (or whatever your calculated depth was). **Repeat this for all 14 similar holes.**

<div align="center">

</div>

---

### **Chamfer/Bevel holes**

Using a Deburring tool, Chamfer/Bevel the (inner) rim of each of the 14 holes you just drilled hole so that the tapered head of the threaded inserts will tighten down flush and feel smooth when your fingers pass over them. This chamfering can be done with a sharp screwdriver or a sharp knife if you don't have a deburring tool. 

Additionally, if you have a drill press, or you can actually just strist the drill bit using your hand, you can use an 11mm drill bit and drill straignt down intop the top of your new 9.5mm holes for the depth of ONLY anout 1-2mm.  this will create a chamfered rim just the same as the above steps.

Make sure you repeat this exact same process for all 14 holes.

<div align="center">

</div>

<div align="center">

</div>

---

### **Install the M6 threaded inserts**

Screw in the **14 individual M6 threaded wood inserts** into the corresponding holes until flush (add a drop of **Superglue** to the *outside* of threads to help permanently secure them to wood).  

If you feel that your threaded insert won't go flush, deburr a little more material to make the taper in the wood larger.

It is absolutely crucial that these threaded inserts are flush or JUST below the surface to ensure that the grommets in future steps will sit flush.

<div align="center">

</div>

<div align="center">

</div>

---

### **Install M3 threaded inserts into wooden faceplates**

Each faceplate has **two  4.5mm holes on the underside** where sensor housings will mount using M3 threaded inserts.  You'll be inserting a total of 8 M3x3mm threaded inserts

**Installation:**

Place a small drop of superglue on the outer edge of each M3x3 threaded insert before you install it.  Rest the insert on top of the 4.5mm hole with the narrow side down, and make sure the insert is level.

<div align="center">

</div>
Using a hammer or rubber mallet, tap the insert into the wood until it's perfectly flush with the surface.  **Two M3x3mm threaded inserts** will be installed beneath each Don and Ka Top Plate.

<div align="center">

</div>

<div align="center">

</div>

This is how it will look when all M6 and M3 threaded inserts are installed:

<div align="center">

</div>

---
### **Prepare The Stainless Steel Mounts**

The Official Taiko no Tatsujin Arcade Drum Controllers use large, machine-cut steel metal plates mounted to the rear of the wooden faceplates.  These metal plates add rigidity which, in turn, help absorb vibration, improve stick feedback, as well as help dampen the sound.  My original design for this project included plans to make your own metal plates, but that required heavy machinery which was extremely impractical and dangerous, not to mention, Steel plates can get very expensive.

I wouldn't let that stop me from creating the proper Arcade experience, however. I knew I needed to design a new method - a method that would replicate ALL of the benefits and feeling of the Steel Arcade Plates, without actual typical Steel Plate method.  After a few days of brainstorming, was able to create a solution that replaces the Steel Plates while retaining 100% of their benefit.

The 1/4" x 1-1/2 OD" Stainless Steel Fender Washers mounts you will be constructing in this next step is my perfect solution.  

You will still get the true arcade benefits of rigidity, vibration absorption, improved stick feedback, and sound dampening without ANY of trouble of using actual steel plates...and for only a few dollars!

**Prepare the Stainless Steel Washer Stacks:**

(Note, the washers may have one side that is slightly sloped/rounded, if so, make that the top face and orient them all the same)

1. Use rubbing alcohol to clean the top and bottom surfaces of 42 1/4" x 1-1/2 OD" Stainless Steel Fender Washers .

2. Each stack will consist of 3 washers superglued together to make a single unit.

   <div align="center">
   
   </div>

3. Place 3 drops of superglue on top of one of the washers.

   <div align="center">
   
   </div>

4. Place another washer on top of the glue dots.  Hold the stack of two washers in your fingers and press them together for 30 seconds, making sure the edges stay evenly aligned.

   <div align="center">
   
   </div>

5. Place 3 drops of superglue on top of the new stack of two washers that you just fastened together.  Place the third washer on top of those new glue dots.

   <div align="center">
   
   </div>

6. Hold the new stack of three washers in your fingers and press them together for 30 seconds, making sure the edges stay evenly aligned.  This stack is complete, set it to the side.

   <div align="center">
   
   </div>

7. Repeat this until you have 14 stacks of 3 washers superglued together.

   <div align="center">
   
   </div>

8. Set these stacks off to the side and let them cure for at least 30 minutes while you assemble the rubber isolators in the next step.

## **5.3: Assemble The Rubber Isolators**

### **Cut nylon bolt head**

1. Measure 20mm of length on one of the 35mm Nylon Bolts.
2. Using a pair of cutters, cut and discard the remining portion of the bolt that has the head attached.  We will only be using the straight 20mm bolt portion for this project.
3. Repeat this process until you have 14 20mm bolts.

<div align="center">

</div>

<div align="center">

</div>

---

### **Apply Loctite to isolator**

Apply one drop or less of **Loctite** to threads on the inside of the rubber isolator threaded hole.

---

### **Install bolt in isolator**

Screw one end of the 20mm bolt into isolator until it stops.

<div align="center">

</div>

---

### **Apply Loctite to drum plate inserts**

Add one drop or less of **Loctite** to inside threads of the M6 threaded inserts on the bottom face of the drum plates.

---

### **Install isolator/Steel Washer assemblies**

(<a href="[URL_GOES_HERE](https://youtu.be/N6h3QC_hvl8?si=WZEyYCb-pd2_z-tV)">HERE</a> is a timelapse video demonstrating how to mount the Isolators and Washers to to the faceplate)

1. Place a washer stack over one of the 6mm threaded insert holes on the bottom of one of the faceplates.

   <div align="center">
   
   </div>

2. Feed the nylon end of the Isolator through the washer stack, and into the threaded insert.  Finger tighten and ensure that the washers do not move/spin and that there's no gap between the wood and the washers, or the washers and the grommet.

   <div align="center">
   
   </div>

3. This is how the sideview of the assembled Isolator/Washer set should look.  If there is a gap, ensure that the 6mm threaded insert is in fact flush to the wood surface.  If the washer stack IS flush, and a gap still remains, unscrew the nylon bolt from the wood, and carefully cut off an additional 1mm of length, and try again.  Repeat if necessary, only removing the smallest amount of bolt needed until everything is flush and snug.

   <div align="center">
   
   </div>

4. Repeat this step for all 14 mounting holes.

   <div align="center">
   
   </div>

---

## **5.4: Print Sensor Housings**

### **Print The Sensor Housings**

💾 [Sensor Housing files are in the file packet here](#9-files--downloads)

Print 4 complete sets of Sensor Housings (each set has a top and bottom).

Use **PLA filament**.

**Printer Settings:** 0.2mm layer height, 40% Gyroid infill, no supports needed.

---

## **5.5: Assemble Sensor Electronics**

🎥 [Video overview of sensor housing assembly](https://youtu.be/tQe-xDEqEdY)

### **Cut neoprene discs**

Cut four **12mm neoprene discs** by using the SVG template.

💾 [Neoprene Disc Template Files are in the file packet here](#9-files--downloads)

---

### **Glue neoprene disc to housing**

Place several drops of **Superglue** into the raised center ring in the bottom shell of the housing. Place a single neoprene disc in this ring on top of the glue. Press lightly for 30 seconds.

<div align="center">

</div>

---

### **Strip Siamese wire**

Take a **12" length of Siamese wire**, strip both ends exposing approximately 12mm of the two wires within.

---

### **Solder TRS Jack**

Take one end of the wire and solder the two exposed wires to the male TRS jack:

- **Red** connects to the **TIP** of the male TRS jack
- **Black** connects to the **SLEEVE** of the male TRS jack

💡 **Tip:** You can use your multimeter in Continuity mode to confirm which terminal is the Sleeve and which is the Tip.

<div align="center">

</div>

---

### **Solder to Piezo**

Take the *other* end of the stripped wire, and solder the **red** wire to piezo center disc, and solder the **black** wire to outer brass ring. The video linked at the beginning of this section illustrates how to do this properly.

<div align="center">

</div>

---

### **Glue Piezo to Neoprene Mount**

Add several drops of **Superglue** onto the top surface of neoprene that is already glued to the bottom housing shell. Center the **piezo sensor** face up (the all-brass side faces *down*, your wires will be on the top) onto the neoprene. Press lightly for 30 seconds. Be sure that the wire is laying across the strain relief channel portion on one side of the bottom housing channel.

💡 **Note:** Pic varies slightly from your version - this was an earlier version. You will have a more pronounced strain relief channel.

<div align="center">

</div>

---

### **Enclose Housing**

Add a drop of **Superglue** to the strain relief channel *below* the wire, as well as on top, and add a few drops to the upper housing around the inside rim. Now assemble the top and bottom housing pieces together, press and hold for 30 seconds. The top shell of the housing will nest into place when aligned properly.

<div align="center">

</div>

#### **Repeat these steps so that you end up with 4 complete sensor assemblies**

---

### **Mount the Sensor Housings to The Drum**

(Here is a timelapse video demonstrating how to mount the sensor housing to the faceplates)

Mount your 4 completed housings to the underside of drum faces using **two M3x8mm screws** for each housing and screwing them into the threaded inserts. Be sure that the bottom of the housing (the side with the neoprene disc glued to it) is flast against the wood.

Tighten snug so that the sensor housing is firmly pressed against the wood - but don't over-tighten.

<div align="center">

</div>

<div align="center">

</div>

Repeat this for each Don and Ka faceplate.

<div align="center">

</div>

---

## **5.6: Mounting Hardware And Faceplates**

### **Mount Adjustable Speaker Plate**

1. Place your **speaker bracket** against the rear/bottom of your baseplate so aligns with the 4 pre-cut mounting holes.

2. Feed **Four M6x16 bolts** though a single 1/4" x 1-1/2 OD" Stainless Steel Fender Washer and then through the four mounting holes on the baseplate so that they come out through the speaker mounting plate holes.  Use 4 M6 knobs to tightly secure the mounting plate against the rear of the Drum

<div align="center">

</div>

<div align="center">

</div>

---

### **Assemble Drum Faceplates to Rear Baseplate**

(Here is a timelapse video demonstrating how to mount the faceplates to the baseplate)

Now assemble the rest of the drum structure by feeding the 14 **M6x18 bolts** on the bottom of the 4 drum faces through baseplate holes of the rear baseplate. Be sure to route the sensor wires through the nearest, round cut-out in the baseplate.

<div align="center">

</div>

<div align="center">

</div>

---

### **Attach TRS barrel mounts**

💾 [Barrel Mount Files are in the file packet here](#9-files--downloads)

1. Carefully flip the partially assembled drum over so that the drum faces dont fall out.
2. 3D Print and Attach **TRS barrel mounts** with adhesive tape as seen in picture.

2. Place the four TRS couplers in the mounts. You will have one pair of Barrel Mounts on each side of the drum.
3. Attach the sensor wires to the top of their respective Barrel Connector

<div align="center">

</div>

---

### **Attach the 6mm Knobs**

Attach a 6mm knob to all of the exposed bolts and tighten finger tight.  Now all 4 faceplates are securely fastened to the baseplate.

<div align="center">

</div>

### **Connect Control Box Extension cables**

Connect the ends of the coiled 3.5mm extension cables to the bottom of the Barrel Connectors.  These extension cables will eventually plug into the female TRS jacks on your Control Box. 

<div align="center">

</div>

---

# **6: Control Box**

<div align="right"><sub><a href="#table-of-contents">-Back to Top-</a></sub></div>

You're almost there!

If you built the board to the exact specifications in my guide, you'll be able to 3D print the included enclosure box for a professional finish to your circuit.

---

## **6.1: 3D Print and Assemble The Control Box**

### **Print the Enclosure**

<div align="center">

</div>

💾 [Controller Enclosure Files are in the file packet here](#9-files--downloads)

Print the Control Box base and lid using the following settings:

--Layer Height: .20mm

--Infill: Gyroid fill @ 20%

--Supports: Automatic

### **Add TRS Terminal Jacks & USB Coupler**

<div align="center">

</div>
Add the 4 TRS jacks into the 4 holes in the back of the base. You will see 4 slight depressions in the base floor to help you align them. Push the female ports all the way into the hole, through the back wall, until it stops. Use a small amount of hot glue to ensure the jacks stay in place.

<div align="center">

</div>

Place the USB coupler in the bottom opening in the base.  Use the slight depression in the base floor to help you align it.  Orient the coupler so that the USB-A port is facing out, and the USB-C port is facing inside the box.  Use a small amount of hot glue to ensure the coupler stays in place.

<div align="center">

</div>

### **Mount The Circuit To The Enclosure Lid**

<div align="center">

</div>
Set one M2x4 heat insert into each of the 4 built-in standoffs on the lid.  Make sure the smooth lip of the grommet is facing down. 

<div align="center">

</div>
Using the included soldering iron heat insert tip to gently press the inserts into the standoffs until the top of the insert is flush with the standoff.  Be sure that the insert remains vertical and does not go in at an angle.

<div align="center">

</div>

Place the circuit board face with buttons and display through the holes in the lid.  Everything should align perfectly.

<div align="center">

</div>
Using 4 M4x4mm bolts, attach the circuit board to the standoffs that you outfitted with threaded inserts.  Tighten snug.

### **Attach Lid To The Control Box Hinges**

<div align="center">

</div>

The hinges on the box were cleverly designed to be fastened using a piece of standard, 1.75mm filament as opposed to a metal hinge pin.

<div align="center">

</div>

Cut off a small section of filament that is  long enough to fit through each set of three hinge sections.  Cut the end at an angle, and gently, yet firmly, feed it all the way through all 3 sections of the hinge you're working on.  It will be snug, but that is by design Cut each end flush.  Repeat this for the other hinge as well.  

---

## **6.2: Connect Circuit Wiring To Control Box**

### **Create the Wires**

<div align="center">

</div>

From the spool of 20 AWG 4-wire ribbon cable, cut 2 lengths of ribbon cable approximately 215mm each.  Crimp the ends using 22 AWG wire ferrules (with small gauge wire like this, going a size smaller on the ferrule helps secure the crimp better and prevent it from pulling off).

One set of 4 wires will be the SIGNAL set, and the other set of 4 wires will be the GROUND set.

### **Connect The Ground Wires**

<div align="center">

</div>

Using the GROUND wire set, connect one end of 4 wires to the GND terminal block on the circuit board.

<div align="center">

</div>

Connect the opposite end of the GROUND wire set to the GND terminal in each of the 4 TRS jacks in your Control Box.  There is no specific order for the GND wires here.  Any GND terminal on the circuit board can connect to any TRS GND terminal.

### **Connect The Signal Wires**

<div align="center">

</div>

<div align="center">

</div>

Using the set of SINGNAL wires, connect the 4 wires ends to the SIGNAL terminal block on the circuit board in the following manner: 
| Terminal Pin | Connects To |
|---|---|
| Pin 1 | TIP terminal of TRS Jack 1 |
| Pin 2 | TIP terminal of TRS Jack 2 |
| Pin 3 | TIP terminal of TRS Jack 3 |
| Pin 4 | TIP terminal of TRS Jack 4 | 

<div align="center">

</div>

### **Connect The XIAO Board To The Control Box USB Coupler**

Using the short USB-C to USB-C cable, connect the XIAO board to the USB-C coupler inside the Control Box.

This is how the final, wired product should look:

<div align="center">

</div>

<div align="center">

</div>

<div align="center">

</div>

------

## **6.3: Floor Stand And Control Box Mount**

### **Mount Drum to speaker stand**

Mount the angled speaker bracket to the speaker stand.

<div align="center">

</div>
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

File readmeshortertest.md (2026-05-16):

<div align="center">

</div>

---

<div align="center">
<i>In Japanese, “ouchi” means “home,” and “taiko” means “drum.”  
Together, OuchiTaiko represents the joy of bringing the arcade Taiko experience into your own space.</i>
</div>

---

# 1. Project Overview

### The Finished Build
My guide walks you through building a full arcade‑style Taiko drum controller that can be used in either **Floor‑Standing Tripod Mode** or **Table‑Top Mode**.

<div align="center">

</div>

<div align="center">

</div>

---

Hi, I’m KillerQ — creator of the **OuchiTaiko Project**, an open‑source guide for building a professional, arcade‑grade Taiko drum controller.

This project is the result of over a year of R&D focused on solving the high cost, limited availability, and inconsistent performance of commercial Taiko controllers. By combining **Adaptive Baseline Software Intelligence (ABSI)**, a custom through‑hole PCB, and a mechanically isolated sensor system, OuchiTaiko delivers arcade‑level responsiveness with approachable DIY construction.

All you need is basic soldering and woodworking skill. The linked parts are verified to work together, though compatible alternatives are welcome.

This guide is intentionally thorough — the goal is simple: **less guessing, more building.**

---

# Key Features

## World‑First Innovations

Traditional Taiko controllers often require constant threshold tuning, firmware recompiles, or compromises between sensitivity and false triggers.

**OuchiTaiko solves these issues with three core systems:**

1. Guided Calibration  
2. Adaptive Baseline Software Intelligence (ABSI)  
3. Custom Sensor Suspension System
---

### 1) Guided Calibration
OuchiTaiko includes two guided calibration options:

- HTML Guided Calibration for the preferred full setup workflow  
- on-device Guided Calibrate for the same method on the controller  
- no recompiling required  
- fast threshold refinement  
- easier crosstalk diagnosis  
- quick retesting after hardware changes  

---

### 2) Adaptive Baseline Software Intelligence (ABSI)
ABSI improves stability through software rather than complex analog circuitry.

- automatic sensitivity adjustment based on environmental noise  
- dynamic baseline tracking  
- stable long‑term behavior without drift  

---

### 3) Custom Arcade Sensor Suspension
A mechanically isolated sensor housing improves consistency and reduces noise.

Benefits include:

- More consistent hit detection  
- Reduced mechanical crosstalk  
- Cleaner signal processing  
- Long‑term durability  

---

## Complete Hardware & Features

### Standalone Testing & Display
No PC required for basic verification.

- OLED display with live feedback  
- Visual confirmation of all 14 navigation buttons  
- Live hit display and mode readout  
- Instant wiring verification using only USB power  

---

### Professional Hardware

- Custom PCB designed specifically for this project  
- 14 navigation buttons for full game control  
- Adjustable drum mounting options  
- Dedicated sensor inputs for all four drum lanes  

---

### Controller Modes

| Mode | Platform Compatibility
|---|---|
| **Switch Tatacon** | Nintendo Switch
| **Switch Pro** | Nintendo Switch 
| **PS3 Dualshock3** | PC/Steam only
| **PS4 Tatacon** | PC/Steam only
| **PS4 Dualshock4** | PC/Steam only
| **Keyboard P1** | PC
| **Keyboard P2** | PC
| **Xbox 360** | PC/Xbox
| **Android (XInput)** | Android devices
| **iOS (XInput)** | iOS devices
| **Analog P1** | PC (TaikoArcadeLoader)
| **Analog P2** | PC (TaikoArcadeLoader)
| **MIDI** | PC/DAW software
| **Debug** | Development/Testing

---

### Zero Coding Required

- Drag‑and‑drop firmware flashing  
- On‑device menus  
- No recompiling for normal setup  
- No programming knowledge needed  

---

### Demo Video

- Gameplay: https://youtu.be/p4eFeo_LB5I?si=jDKb93B7uYx1qAux

---

# 2. Parts List for Electronics

<div align="right"><sub><a href="#table-of-contents">-Back to Top-</a></sub></div>

These linked parts are verified to work together as tested.

| Item | Pieces Needed | Product Link |
| --- | --- | --- |
| Waveshare RP2040‑Zero | 1 | https://www.amazon.com/dp/B09SBCKYSC |
| 1N4148 diodes | 4 | https://www.amazon.com/dp/B0DN62QFYS |
| 0.1uF / 100nF ceramic capacitors | 4 | https://www.amazon.com/dp/B08B3VCK42 |
| 3.5mm female audio jack, PJ‑320A | 4 | https://www.amazon.com/dp/B07KY862P6 |
| 3.5mm TRS male plugs with leads | 4 | https://www.amazon.com/dp/B0D72TV7Y5 |
| 1K ohm resistor, 1/2W | 4 | https://www.amazon.com/dp/B0FP1YFMVM |
| 27mm piezo sensors | 4 | https://www.amazon.com/dp/B07RK2TQ8D |
| 128x64 mono OLED display (I2C) | 1 | https://www.amazon.com/dp/B09T6SJBV5 |
| 6mm tactile switches with caps | 14 | https://www.amazon.com/dp/B07VQF8P2Y |
| 6" coiled 3.5mm TRS extension cable | 4 | https://www.amazon.com/dp/B0D7CXJ5LQ |
| 3.5mm TRS barrel coupler | 4 | https://www.amazon.com/dp/B07YSCGBL7 |
| 6ft USB‑A to USB‑C cable | 1 | https://www.amazon.com/dp/B0CKXZML11 |

---

# 3. Parts List for Hardware

<div align="right"><sub><a href="#table-of-contents">-Back to Top-</a></sub></div>

## Required Tools & Supplies

1. Laser cutter, CNC, or alternative cutting method  
2. Soldering iron + solder  
3. Wire strippers / cutters  
4. Screwdrivers  
5. Hot glue gun  
6. Strong clamps  
7. Drill  
8. Router  
9. Sandpaper  
10. Utility knife  
11. Rubber mallet  

## Hardware Parts List

| Item | Pieces Needed | Product Link |
| --- | --- | --- |
| 1/4" (6mm) MDF, 2ft x 4ft | 2 | https://www.homedepot.com/p/1-4-in-x-2-ft-x-4-ft-MDF-1508104/202089069 |
| 1/4" x 1‑1/2" OD stainless fender washers | 46 | https://www.amazon.com/dp/B0D8ZRL1CP |
| Wood glue | 1 | https://www.amazon.com/dp/B0002YQ378 |
| M3 x 8mm bolts | 8 | https://www.amazon.com/dp/B07CMQ1SQH |
| M3 x 5mm threaded inserts | 8 | https://www.amazon.com/dp/B0CLKCQ2SH |
| M6 x 10mm wood threaded inserts | 14 | https://www.amazon.com/dp/B0CNLRFFH1 |
| M6 x 35mm nylon bolts | 14 | https://www.amazon.com/dp/B07L9ZS21T |
| M6 threaded 20mm x 15mm rubber isolators | 14 | https://www.amazon.com/dp/B0BKPHT6Y9 |
| PLA filament | 1 | https://www.amazon.com/dp/B081S5N5PC |
| Gel superglue | 1 | https://www.amazon.com/dp/B0006HUJCQ |
| Medium thread adhesive / Loctite | 1 | https://www.amazon.com/dp/B000FIXQXK |
| 2.2mm scuba knit neoprene fabric | 1 | https://www.amazon.com/dp/B0DK1B5LZ7 |
| Finger knobs with pass‑through M6 threads | 18 | https://www.amazon.com/dp/B07RW9ZH4H |
| Mini PA speaker tripod stand (optional) | 1 | https://www.amazon.com/dp/B094N9YG72 |
| Desktop monitor stand (optional) | 1 | https://www.amazon.com/dp/B072QDMRS8 |
| Adjustable angle speaker bracket | 1 | https://www.amazon.com/dp/B0DR8NCZP6 |
| Phone holder w/ gooseneck arm (optional) | 1 | https://www.amazon.com/dp/B0F32MLBZX |
| Rubber Taiko drum cover (recommended) | 1 | https://taiko.ac/products/rubber-drum-pad |
| 1/4" roundover router bit | 1 | https://www.amazon.com/dp/B0C5DVBNLS |
| Clear spray glaze / lacquer | 1 | https://www.amazon.com/dp/B00D0293SA |
| Deburring tool (optional) | 1 | https://www.amazon.com/dp/B07RM1D6WD |

---

# 4. Assemble the Control PCB

<div align="right"><sub><a href="#table-of-contents">-Back to Top-</a></sub></div>

<div align="center">

</div>

<div align="center">

</div>

## Control PCB Overview

The custom PCB integrates controller logic, display wiring, navigation buttons, and drum input circuitry into one compact board.

You will solder:

- **1× Waveshare RP2040‑Zero**  
- **14× tactile buttons**  
- **4× 1N4148 diodes**  
- **4× 1K resistors**  
- **4× 0.1uF capacitors**  
- **1× I2C OLED**  
- **4× PJ‑320A TRS jacks**

---

## Recommended Assembly Order

### Step 1: Solder Passive Components
Install:

- `R1–R4` = 1K resistors  
- `C1–C4` = 0.1uF capacitors  
- `D1–D4` = 1N4148 diodes  

Ensure diode black bands match the silkscreen (cathode to the **left** when viewed from above).

---

### Step 2: Solder the 14 Buttons
Install all navigation buttons in their labeled positions.

The rectangular pin layout must match the PCB footprint. Ensure each button sits flat before soldering all four legs.

---

### Step 3: Mount the OLED
Install the OLED using the following pin order (verify yours matches):

- GND  
- VCC  
- SCL  
- SDA  

---

### Step 4: Install the TRS Drum Input Jacks
Install the four PJ‑320A jacks. Their pin layout only fits one orientation.

---

### Step 5: Mount the RP2040‑Zero
Install the Waveshare RP2040‑Zero. Only the 20 castellated perimeter pads need soldering.

A helpful soldering demonstration:  
https://youtu.be/rGvvwXrv310?t=312

---

## Inspect Your Work

Before powering on, confirm:

- RP2040‑Zero is aligned correctly  
- OLED pins are correct  
- All 14 buttons are soldered  
- All four drum lanes have resistor, capacitor, and diode installed  
- No solder bridges  
- All joints look solid  

Firmware flashing is covered in **Section 7**.

---

# **5: Build the Drum**

<div align="right"><sub><a href="#table-of-contents">-Back to Top-</a></sub></div>

**Important Scale Notice:** The SVG files provided in the download are the correct scale and should **NOT** be resized. The drum dimensions are precisely calculated to work with the sensor housings and other non-scalable components. If you try to make the drum smaller, other parts will not fit later in the project.

💡 **Scale Verification:** Before cutting, verify the SVG files are at correct scale by checking the shapes in the SVG file against the listed dimensions noted in the KEY section of that same SVG file. 

**No laser cutter or CNC access?** No worries - there are other options. Ask a friend, local shop, or check if your area has a Makerspace. Alternatively, you can print the SVG files full-size across multiple sheets of paper (ensure your printer is set to 100% scale / "Actual Size"), and then overlay the paper on your wood as a template.  You would then cut and drill by hand. Double check that your printed templates are sized properly before cutting or drilling anything.

---

## **5.1: Prepare the Wood**

### **Cut all MDF wood pieces per SVG templates**

💾 [SVG Template packet located here](#9-files--downloads)

Use your laser or CNC machine (or the method available to you) to cut out all of the wood components in the template files.

- You'll be printing one set of upper faceplates
- You'll be printing one set of lower faceplates
- You'll be printing 2x identical baseplates

<div align="center">

</div>

<div align="center">

</div>

---
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

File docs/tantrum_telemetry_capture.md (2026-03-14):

# Tantrum Telemetry Capture

Use this command from repo root:

```powershell
powershell -ExecutionPolicy Bypass -File .\scripts\capture_tantrum_logs.ps1 -Runs 4
```

Optional explicit COM port:

```powershell
powershell -ExecutionPolicy Bypass -File .\scripts\capture_tantrum_logs.ps1 -Port COM7 -Runs 4
```

What it does:
- Creates a timestamped folder at `logs/calibration/YYYYMMDD_HHMMSS/`
- Saves:
  - `session.txt`
  - `raw.log`
  - `tantrum_runs.csv`
- Updates `logs/calibration/latest.txt` with the latest folder path

Recommended workflow:
1. Run auto-calibration in your normal gameplay mode (for example Tatacon).
2. After calibration completes, switch to `Calibrate/Debug` mode.
3. Start this script to download persisted telemetry from flash.
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

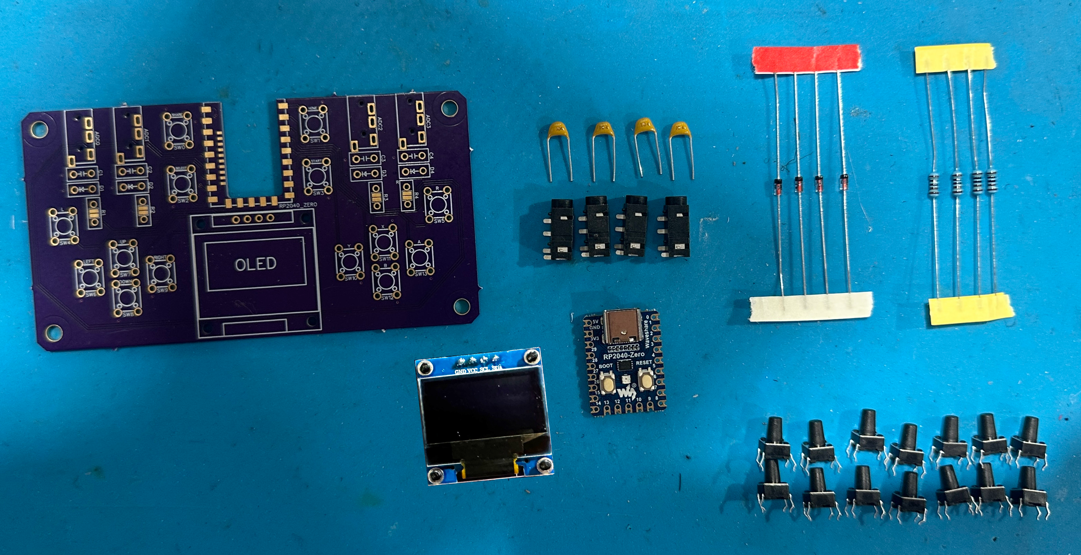
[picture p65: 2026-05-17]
images/Pictures/pcbpartsall.png

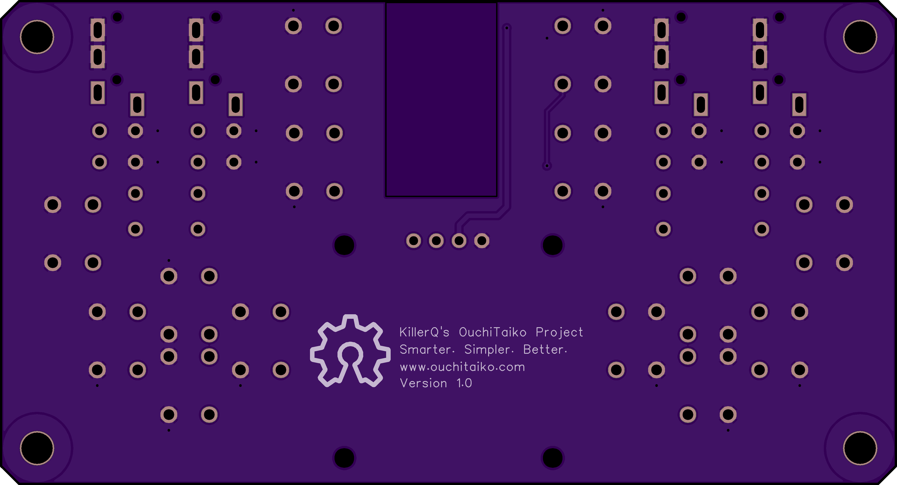
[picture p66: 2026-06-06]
images/Pictures/f58799217b39971759f265c647769d1b.png

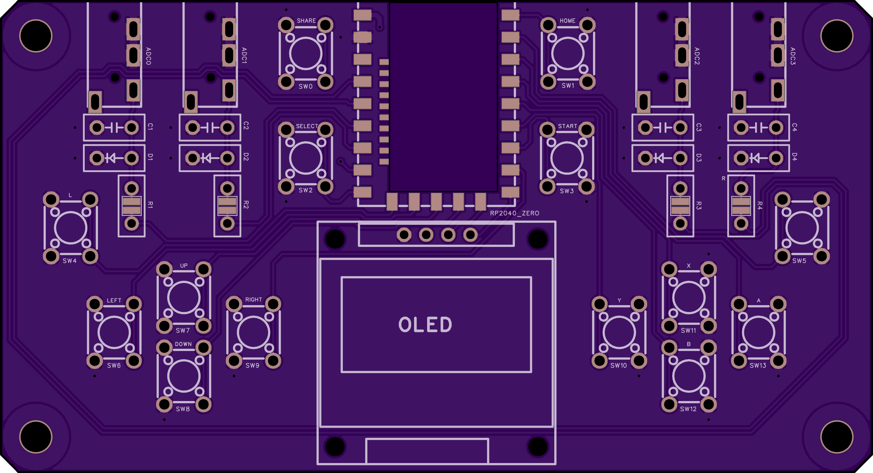
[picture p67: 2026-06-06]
images/Pictures/0220031ec2efd1bc80251761098dc16e.png

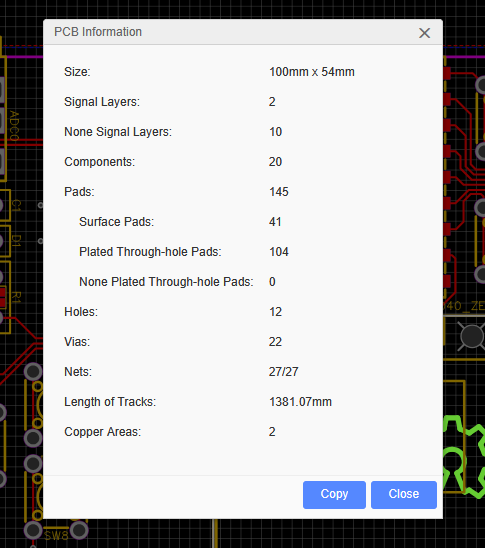
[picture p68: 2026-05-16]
.pcb/OT v3/Screenshot 2026-03-29 231634.png

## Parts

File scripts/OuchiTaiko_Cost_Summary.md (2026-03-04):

# OuchiTaiko Build Cost Summary

| Item | Link | Buy Qty | Checkout Cost | Used Value |
| :--- | :--- | :--- | :--- | :--- |
|  | [Amazon Link](https://www.amazon.com/dp/B0DRNTQ338) | 1 | $10.99 | $10.99 |
| GODIYMODULES MCP23017 I2C expander board | [Amazon Link](https://www.amazon.com/dp/B0DSLPRKKZ) | 1 | $9.99 | $9.99 |
| 1N4148 diodes | [Amazon Link](https://www.amazon.com/dp/B0DN62QFYS) | 1 | $5.99 | $0.20 |
| 0.1uF/100nF ceramic capacitors | [Amazon Link](https://www.amazon.com/dp/B08B3VCK42) | 1 | $6.99 | $0.23 |
| 3.5mm TRS female jacks w/ screw terminals | [Amazon Link](https://www.amazon.com/dp/B017CBTLJK) | 1 | $5.99 | $5.99 |
| 3.5mm TRS male plugs w/ standard ends | [Amazon Link](https://www.amazon.com/dp/B07Y8JGFS1) | 1 | $6.99 | $6.99 |
| 27mm piezo sensors | [Amazon Link](https://www.amazon.com/dp/B07RK2TQ8D) | 1 | $7.79 | $1.56 |
| 128x64 mono OLED display (I2C) | [Amazon Link](https://www.amazon.com/dp/B09T6SJBV5) | 1 | $14.99 | $3.00 |
| 6mm x 6mm x 8mm tactile switches | [Amazon Link](https://www.amazon.com/dp/B0827LX3FV) | 1 | $8.99 | $1.50 |
| 22 AWG Siamese wire | [Amazon Link](https://www.amazon.com/dp/B0CN76L8G3) | 1 | $8.99 | $8.99 |
| USB-C to USB-A female coupler | [Amazon Link](https://www.amazon.com/dp/B0CY314DCJ) | 1 | $5.99 | $3.00 |
| Short USB-C to USB-C extension cable | [Amazon Link](https://www.amazon.com/dp/B0DFHG5LNY) | 1 | $7.99 | $2.66 |
| 6 inch, coiled 3.5mm TRS audio extension cable (male to male) | [Amazon Link](https://www.amazon.com/dp/B0D7CXJ5LQ) | 2 | $17.98 | $17.98 |
| 3.5mm TRS barrel coupler | [Amazon Link](https://www.amazon.com/dp/B072J3LGSQ) | 1 | $6.99 | $6.99 |
| 4-pin, 0.2 inch pitch screw terminal blocks | [Amazon Link](https://www.amazon.com/dp/B098QMNHPJ) | 1 | $8.99 | $0.90 |
| 22 AWG 4-wire ribbon connection wire | [Amazon Link](https://www.amazon.com/dp/B09X47XBFS) | 1 | $14.98 | $14.98 |
| ElectroCookie circuit board (88.9mm x 96.5mm) | [Amazon Link](https://www.amazon.com/dp/B07YSCGBL7) | 1 | $11.99 | $4.00 |
| 10ft USB-A to USB-A cable | [Amazon Link](https://www.amazon.com/dp/B08FTDWPTX) | 1 | $9.99 | $9.99 |
| M2 x 3 x 3 threaded inserts | [Amazon Link](https://www.amazon.com/dp/B0FD7DQS8Y) | 1 | $9.99 | $0.13 |
| M2 x 4 bolts | [Amazon Link](https://www.amazon.com/dp/B0D3X4LJD2) | 1 | $7.99 | $0.04 |
| 22 AWG wire ferrules and crimper | [Amazon Link](https://www.amazon.com/dp/B0DRJ9CDNG) | 1 | $14.24 | $14.24 |
|  | [Amazon Link](https://www.amazon.com/dp/B0D8ZRL1CP) | 1 | $8.85 | $0.35 |
| Strong wood glue | [Amazon Link](https://www.amazon.com/dp/B0002YQ378) | 1 | $4.98 | $4.98 |
| M3 x 8mm bolts | [Amazon Link](https://www.amazon.com/dp/B07CMQ1SQH) | 1 | $6.96 | $0.56 |
| M3 x 5mm threaded inserts | [Amazon Link](https://www.amazon.com/dp/B0CLKCQ2SH) | 1 | $8.98 | $0.60 |
| M6 x 10mm wood threaded inserts | [Amazon Link](https://www.amazon.com/dp/B0CNLRFFH1) | 1 | $9.49 | $1.33 |
| M6 x 35mm nylon bolts | [Amazon Link](https://www.amazon.com/dp/B07L9ZS21T) | 1 | $9.99 | $2.80 |
| M6 threaded 20mm x 15mm rubber isolators (one side M6 female, other side with M6 x 18mm bolt) | [Amazon Link](https://www.amazon.com/dp/B0BKPHT6Y9) | 4 | $47.96 | $41.97 |
| 3D printer filament (PLA) | [Amazon Link](https://www.amazon.com/dp/B081S5N5PC) | 1 | $22.99 | $22.99 |
| Gel superglue | [Amazon Link](https://www.amazon.com/dp/B0006HUJCQ) | 1 | $2.99 | $2.99 |
| Loctite thread adhesive - medium | [Amazon Link](https://www.amazon.com/dp/B000FIXQXK) | 1 | $9.99 | $9.99 |
| 2.2mm thick scuba knit neoprene fabric (only 4" x 4" total needed) | [Amazon Link](https://www.amazon.com/dp/B0DK1B5LZ7) | 1 | $17.00 | $17.00 |
| Finger knobs with pass-through M6 threads | [Amazon Link](https://www.amazon.com/dp/B07RW9ZH4H) | 4 | $26.00 | $23.40 |
| Mini PA speaker stand (or a stand with a compliant interface that matches your mount below) | [Amazon Link](https://www.amazon.com/dp/B094N9YG72) | 1 | $39.99 | $39.99 |
| Adjustable angle speaker bracket (or a compliant interface that matches your stand above) | [Amazon Link](https://www.amazon.com/dp/B0DR8NCZP6) | 1 | $15.98 | $15.98 |
| Rubber Taiko drum cover (optional but crucial for arcade feel. Any thin sound-dampening material may suffice) | [Amazon Link](https://taiko.ac/products/rubber-drum-pad) | 1 | $99.99 | $99.99 |
| Spring-loaded phone holder with gooseneck arm | [Amazon Link](https://www.amazon.com/dp/B0F32MLBZX) | 1 | $14.99 | $14.99 |
| 1/4" Roundover Router Bit | [Amazon Link](https://www.amazon.com/dp/B01I1YQRTE) | 1 | $8.99 | $8.99 |
| Clear Spray Glaze/Lacquer | [Amazon Link](https://www.amazon.com/dp/B00D0293SA) | 1 | $7.33 | $7.33 |
| Deburring Tool | [Amazon Link](https://www.amazon.com/dp/B07RM1D6WD) | 1 | $14.99 | $14.99 |
| **TOTAL** | | | **$583.26** | **$455.55** |

### Financial Breakdown
- **Total to Purchase:** $583.26
- **Actual Value in Drum:** $455.55
- **Spare Parts Value:** $127.71

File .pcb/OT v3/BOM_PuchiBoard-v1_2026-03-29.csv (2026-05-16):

ID | Name | Designator | Footprint | Quantity | Manufacturer Part | Manufacturer | Supplier | Supplier Part | Price | Pins | 3DModel
1 | AUDIO-TH_PJ-320A | ADC3,ADC2,ADC1,ADC0 | AUDIO-TH_PJ-320A | 4 | PJ-320A RHOS | ReliaPro | LCSC | C12569 |  | 4 | AUDIO-TH_PJ-320A
2 | COMM-SMD_RP2040-ZERO | RP2040_ZERO | COMM-SMD_RP2040-ZERO | 1 | RP2040-Zero | Waveshare(微雪电子) | LCSC | C5350143 | 5.999 | 33 | COMM-TH_RP2040-ZERO
3 | SW-TH_4P-L6.0-W6.0-P4.50-LS6.5 | SW0,SW1,SW9,SW10,SW2,SW3,SW7,SW8,SW6,SW12,SW11,SW13,SW4,SW5 | SW-TH_4P-L6.0-W6.0-P4.50-LS6.5 | 14 | TS-1095-A11B3-D1 | Yuandi | LCSC | C493055 | 0.036 | 4 | SW-TH_4P-L6.0-W6.0-H5.0-LS6.5-P4.50
4 | OLED-TH_OLED0.96-I2C | OLED | OLED-TH_OLED0.96-I2C | 1 | ZJY096S0700BG01蓝色 | AZDelivery |  | AZDelivery |  | 4 | COMM-TH_L27.3-W27.8-0.96INCH-OLED-MMC096GX

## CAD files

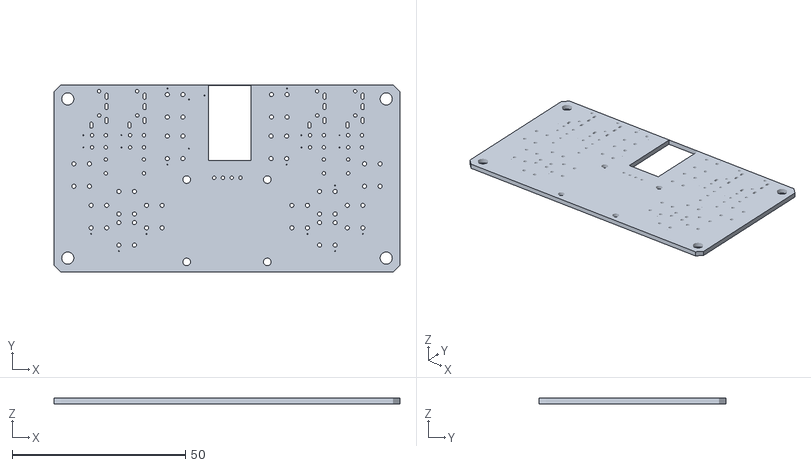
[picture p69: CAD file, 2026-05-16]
.pcb/mainboard.stl
100.0 x 54.0 x 1.61

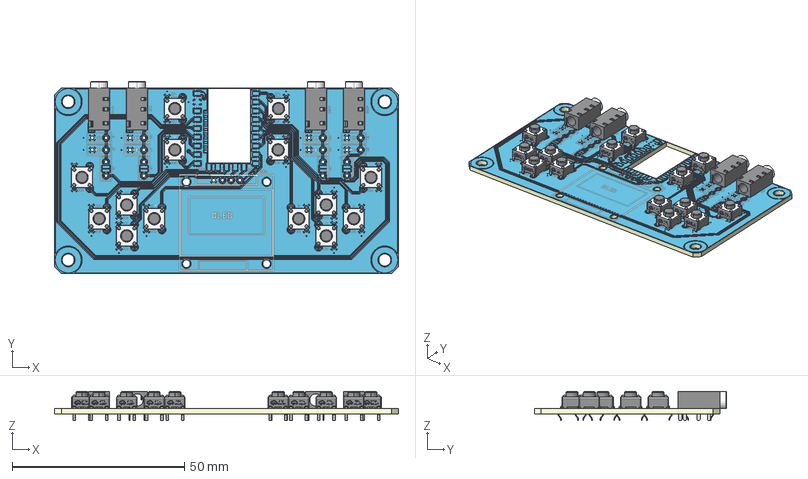
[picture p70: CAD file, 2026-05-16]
.pcb/3D_PCB_PCB_Drum_2026-03-27_2026-03-27.step
100.0 x 55.9 x 8.50 mm
Board~1ksc
TopCopper~1ksc
BottomCopper~1ksc
TopSilkscreen~1ksc
BottomSilkscreen~1ksc
TopFpcStiffener~1ksc
BottomFpcStiffener~1ksc
SW-TH_4P-L6.0-W6.0-P4.50-LS6.5~SW-TH_ 4P-L6.0-W6.0-H5.0-LS6.5-P4.50~1ksc x 14
AUDIO-TH_PJ-320A~AUDIO-TH_PJ-320A~1ksc x 4

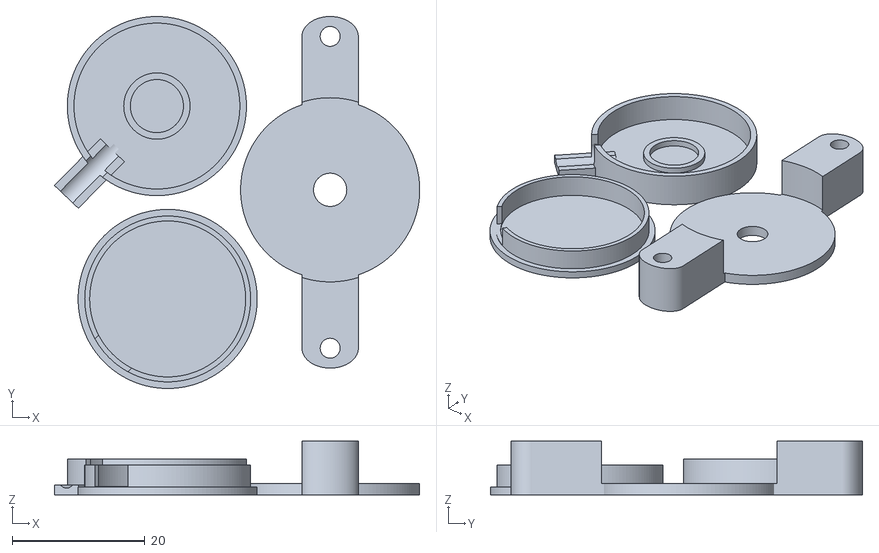
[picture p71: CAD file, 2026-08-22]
download_files/ouchitaiko_sensor_housing_small.stl
55.1 x 56.1 x 8.07

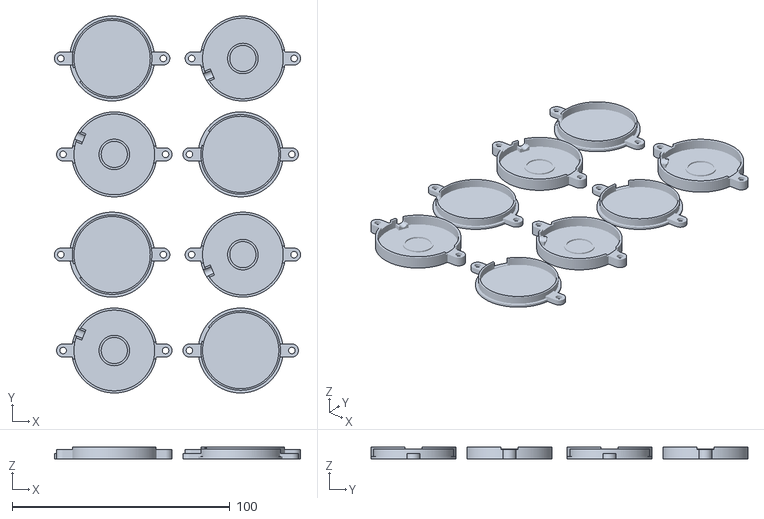
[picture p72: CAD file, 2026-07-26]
download_files/ouchitaiko_sensor_housing.stl
113.0 x 173.0 x 5.41

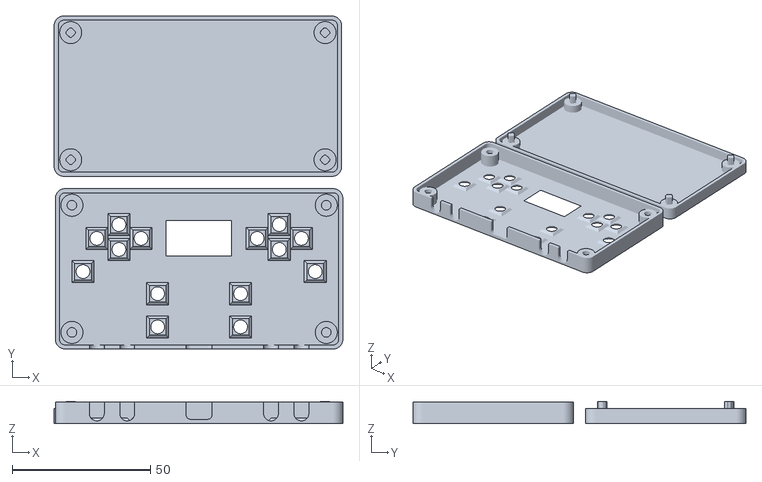
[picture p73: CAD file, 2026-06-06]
download_files/ouchitaiko_controller_shell.stl
104.4 x 120.4 x 8.10

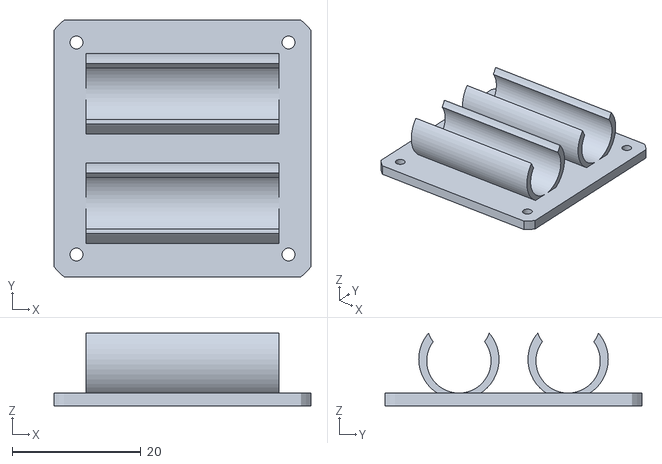
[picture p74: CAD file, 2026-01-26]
download_files/ouchitaiko_barrel_connector_mount.stl
40.0 x 40.0 x 11.3

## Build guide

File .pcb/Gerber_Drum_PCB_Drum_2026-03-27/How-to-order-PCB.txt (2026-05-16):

How to Order PCB

Please refer to:
https://docs.easyeda.com/en/PCB/Order-PCB

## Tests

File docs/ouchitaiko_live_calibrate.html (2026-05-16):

OuchiTaiko Live Calibrate

Not connected

## Connect your drum in Debug/Calibrate mode

Set your drum to Calibrate/Debug USB mode using the on-device menu.
Plug in via USB, then click Connect.
Requires Chrome or Edge.

Connect Serial Port

Choose Mode

Thresholds

### Live Calibrate

Live thresholds, signal trace, lane validation, and guided calibration.

Crosstalk

### Pad Isolation Test

Sticky green/red result view for finding which extra pad leaks when you strike hard.

Buttons

### Button Tester

Jump to the browser gamepad tester to confirm non-debug gamepad mappings.

Live Calibrate Pad Isolation Test Mode Home

Live Signal and Hit Lane

Live Apply: Off Save to Drum Load Release Baseline

- 200 +

Ka Left

- 175 +

Don Left

- 175 +

Don Right

- 200 +

Ka Right

Hit Scope - fast 4-lane hit timeline. Each dot is one accepted hit; double hits appear as stacked or closely-spaced dots.

Live Accuracy Diagnostics

Total Hits

0

Ka L / Don L

0 / 0

Don R / Ka R

0 / 0

Cross-Blocked

0

Arb-Blocked

0

Held-High Suppress

0

Last Event

Interpretation

Stable

Hits / Sec

0.0

Peak Hits / Sec

0.0

Auto-Calibrate

Calibrate Thresholds

Deep auto-calibration (about 3 minutes) — repetitive high-speed and stress passes for each pad to maximize out-of-box reliability. Click Start Calibration to begin.

0

Ka Left

0

Don Left

0

Don Right

0

Ka Right

Start Calibration

Suggested Thresholds

Ka Left—

Ka Right—

Don Left—

Don Right—

Apply & Save to Drum

? Advanced — confidence levels, crosstalk matrix & debug log ?

Threshold Analysis

Pad | Current | | Suggested | Confidence | Reason

Crosstalk Matrix

Columns = pad hit · Rows = bleed onto · Red = above threshold · Amber = close · Green = fine

Serial Log

Hit 5 Times Lane Validation Guided Test Suite Copy Log Pause Log

Waiting for hits…

Save to Drum Clear Real-Time Hit Data Disconnect

Sticky Pad Isolation Test

Strike any pad firmly. A clean hit flashes green and clears automatically. If any extra pad triggers, the intended pad stays green and the extra pad sticks red until Reset.

Reset Sticky Result Copy Summary Live. Strike any pad.

KA LEFT

DON LEFT

DON RIGHT

KA RIGHT

Strikes

0

Clean

0

Doubles

0

Last Pair

Strike a pad. Clean hits clear automatically; red bleed pads stay sticky until Reset.

Switch your drum to any non-Debug mode, then press any button to detect it.

No gamepad

L

L

Share

Share

?

?

?

?

Select

OuchiTaiko

? ? ? ?

Ka L

Don L

Don R

Ka R

¦

Home

+

Start

R

R

X

Y

A

B

Switch to a gamepad mode (e.g. Switch Tatacon) and press any button

Gamepad Hit Scope — logical button hits detected through the browser Gamepad API.

How to use: Switch your drum out of Debug/Calibrate mode into any gamepad mode (Switch Tatacon, PS4, XInput, etc.).
Plug in via USB — it appears as a gamepad. Press any button and it lights up above matching your actual PCB.

Drum hits: Ka pads = ZL/ZR · Don pads = L3/R3 in Switch Tatacon mode · Face: X=North B=South Y=West A=East

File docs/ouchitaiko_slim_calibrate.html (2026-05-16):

OuchiTaiko Slim Calibrate

Hit the current lane. If another lane says Increase Me, raise that lane and test again.

Not connected

Connect Controller Debug Mode Save to Drum

## Recommended workflow

Set the controller to Web Calibrate mode. Hit the green test lane. If another lane shows Increase Me, raise that lane until only the target lane stays clean, then press Next.

Step 1 of 4

Ka Left

Current target is Ka Left.

Previous Next Reset Step Reload Thresholds

Waiting for connection.

Slim Debug Log

Copy Log Clear Log

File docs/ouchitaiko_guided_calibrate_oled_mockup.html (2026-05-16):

# Guided Calibrate OLED Workflow

This is a full screen-by-screen mockup of the intended on-device guided calibration flow. It is laid out in the order the player would see it, with branch screens inline where bleed, retry, review, save, or cancel paths appear.

## Main Path

Clean version of the workflow we want: one target pad at a time, repeated normal hits, one hard hit at the end, then review and save.

1. Drum Tuning MenuEntry point

DRUM TUNING

> Guided Calibrate Manual Thresholds Reset Thresholds

UP/DN SelectA Enter

User enters the tuning menu and chooses the guided workflow instead of direct manual threshold editing.

main path

2. Guided StartIntro screen

GUIDED CALIBRATE

Tests one drum pad at a time. Raises only the pads that bleed.

B BackA Start

Short explanation. This should feel like a tool, not a mystery algorithm.

main path

3. How It WorksExpectation setting

HOW IT WORKS

Per drum pad: 5 fast normal hits 1 hard hit at end

B BackA Continue

This copies the web workflow rhythm the user already trusts.

main path

4. Test Ka LeftNormal hit phase

TEST KA LEFT (1/4)

5 normal hits Hits: 0 / 5

Target: KLB Cancel

The first active pad. Same layout repeats for `Don Left`, `Don Right`, then `Ka Right`.

main path

5. Normal Hit ProgressSame screen updates live

TEST KA LEFT (1/4)

5 normal hits Hits: 4 / 5

Looking for bleedB Cancel

We keep the screen stable and only update the hit count so the user stays oriented.

main path

6. Hard Hit PromptFinal validation hit

TEST KA LEFT (1/4)

HIT HARD NOW

Final hitB Cancel

This gives the hard hit its own clear moment so the user cannot confuse it with the normal five.

main path

7. Pad CleanCurrent target passed

KA LEFT CLEAN

No bleed detected. Threshold stays at 285.

Loading next pad...

Short confirmation before the firmware advances to the next target pad automatically.

main path

8. Repeat for Don LeftSecond pad

TEST DON LEFT (2/4)

5 normal hits Hits: 0 / 5

Target: DLB Cancel

Same structure repeats for all four pads. Only the target name and index change.

main path

9. Repeat for Don RightThird pad

TEST DON RIGHT (3/4)

5 normal hits Hits: 0 / 5

Target: DRB Cancel

Still the same workflow. Consistency matters here more than novelty.

main path

10. Repeat for Ka RightFourth pad

TEST KA RIGHT (4/4)

5 normal hits Hits: 0 / 5

Target: KRB Cancel

This is the pad that exposed the cross-side Ka issue in testing, so the user will trust this step a lot.

main path

11. Review ThresholdsAfter all 4 pass

REVIEW THRESHOLDS

KL 285 DL 285 DR 285 KR 285 Ready to save

B CancelA Save

Compact summary screen. This is where the user should feel in control before writing to flash.

main path

12. SavingFlash write

SAVING

WRITING TO FLASH

Please wait...

No user decision here. Just a clean, brief state so it feels deliberate.

main path

13. CompleteEnd state

DONE

Thresholds saved. Guided calibrate complete.

Returning to play...

Simple completion state. The user should leave feeling the process is finished and trustworthy.

main pathend state

## Branch Screens

These appear only when something needs correction or the user chooses to back out. They are still part of the workflow and should feel just as clear as the main path.

A. Bleed DetectedCore corrective moment

BLEED DETECTED

Right Ka caused Left Ka to move. Raised KL +5

KL now 290A Hit Again

This is the most important branch screen. It explains cause, response, and next step without ambiguity.

branch

B. Multiple Pads RaisedRare but possible

BLEED DETECTED

Raised: DL +5 KR +5

Repeat same padA Continue

If more than one non-target pad bleeds, the screen should still stay readable and list the changes clearly.

branch

C. Retry Current PadAfter automatic adjustment

TEST KA LEFT (1/4)

Thresholds updated. Repeat 5 normal hits.

KL 290B Cancel

This resets the user back into the same target pad flow after the firmware makes its small correction.

branch

D. Save ConfirmationOptional extra guard

SAVE THRESHOLDS?

KL 285 DL 285 DR 285 KR 285

B BackA Save

If we want one extra safety step before writing flash, this is the right place for it.

optional branch

E. Cancel ConfirmationExit path

CANCEL GUIDED CAL?

Current changes will not be saved.

B NoA Cancel

A clean escape hatch prevents accidental exits from feeling like data loss or confusion.

branch

F. CancelledBack out state

GUIDED CAL CANCELLED

No thresholds saved. Returning to menu.

Safe exit...

If the user bails out, we should end cleanly and explicitly say nothing was saved.

branchend state

Notes: this mockup is for workflow review, not a pixel-perfect copy of the current firmware screens. It intentionally reflects the cleaner HTML-style guided process we discussed: one target pad at a time, repeated normal hits, one hard hit, detect bleed, raise only offending pads, then review and save.

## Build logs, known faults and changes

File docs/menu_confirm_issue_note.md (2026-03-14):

## Menu A-Button Issue (Resolved)

### Symptom
- `A` appeared to work on some menu sections (`Menu` pages like `Advanced`, `Drum Tuning`) but not others (notably `About` and other informational `Selection` entries).
- Behavior looked selective and inconsistent.

### Root Cause
- In `Menu::update()`, `Descriptor::Type::Selection` treated confirm (`A`) as `gotoParent(false)` for most cases.
- Informational selection entries (where action is `Action::None`, such as `About`) should not have been auto-closed by `A`.
- Result: pressing `A` could enter a page and immediately trigger back behavior, making it appear like `A` did not work.

### Fix
- Updated `Selection` confirm handling:
  - If selected entry action is `Action::None`, ignore `A` and require `B` for back.
  - Keep existing explicit behavior for special pages (`TaikoTantrum`, `DeviceMode`).

### Build Marker
- First build with this fix: `Build 68 Onyx`.

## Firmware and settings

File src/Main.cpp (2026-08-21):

//beginning of Main.cpp

#include "peripherals/Controller.h"
#include "peripherals/Display.h"
#include "peripherals/Drum.h"
#include "peripherals/StatusLed.h"
#include "usb/device/hid/ps4_auth.h"
#include "usb/device_driver.h"
#include "utils/InputReport.h"
#include "utils/InputState.h"
#include "utils/Menu.h"
#include "utils/PS4AuthProvider.h"
#include "utils/SettingsStore.h"

#include "GlobalConfiguration.h"
#include "PS4AuthConfiguration.h"

#include "pico/bootrom.h"
#include "pico/multicore.h"
#include "pico/stdlib.h"
#include "pico/time.h"
#include "pico/util/queue.h"

#include <cstdio>
#include "tusb.h"

using namespace OuchiTaiko;

namespace {

queue_t control_queue;
queue_t menu_display_queue;
queue_t drum_input_queue;
queue_t controller_input_queue;
queue_t bringup_test_queue;

queue_t auth_challenge_queue;
queue_t auth_signed_challenge_queue;

// Queue for sending drum pointer to core 1
queue_t drum_reference_queue;

// NEW: Queue for sending fresh threshold data to Display
queue_t thresholds_queue;

enum class ControlCommand : uint8_t {
    SetUsbMode,
    SetPlayerLed,
    SetLedBrightness,
    SetLedEnablePlayerColor,
    EnterMenu,
    ExitMenu
};

struct ControlMessage {
    ControlCommand command;
    union {
        usb_mode_t usb_mode;
        usb_player_led_t player_led;
        uint8_t led_brightness;
        bool led_enable_player_color;
        char mode_name[32];  // For Big Hit Mode confirmation
    } data;
};

void core1_task() {
    multicore_lockout_victim_init();

    gpio_set_function(Config::Default::i2c_config.sda_pin, GPIO_FUNC_I2C);
    gpio_set_function(Config::Default::i2c_config.scl_pin, GPIO_FUNC_I2C);
    gpio_pull_up(Config::Default::i2c_config.sda_pin);
    gpio_pull_up(Config::Default::i2c_config.scl_pin);
    i2c_init(Config::Default::i2c_config.block, Config::Default::i2c_config.speed_hz);

    Peripherals::Controller controller(Config::Default::controller_config);
    Peripherals::StatusLed led(Config::Default::led_config);
    Peripherals::Display display(Config::Default::display_config);

    Utils::PS4AuthProvider ps4authprovider;
    std::array<uint8_t, Utils::PS4AuthProvider::SIGNATURE_LENGTH> auth_challenge{};

    Utils::InputState input_state;
    Utils::Menu::State menu_display_msg{};
    ControlMessage control_msg{};
    Peripherals::Display::BringupTestState bringup_test_state{};

    // Receive drum pointer from core 0
    Peripherals::Drum *drum_ptr = nullptr;
    queue_remove_blocking(&drum_reference_queue, &drum_ptr);
    display.setDrumReference(drum_ptr);

    // NEW: Storage for fresh threshold data
    Peripherals::Drum::Config::Thresholds fresh_thresholds{};

    while (true) {
        controller.updateInputState(input_state);

        // Queue controller samples so short taps are not overwritten before Core 0 sees them.
        if (!queue_try_add(&controller_input_queue, &input_state.controller)) {
            Utils::InputState::Controller dropped{};
            queue_try_remove(&controller_input_queue, &dropped);
            queue_try_add(&controller_input_queue, &input_state.controller);
        }
        
        queue_try_remove(&drum_input_queue, &input_state.drum);

        // NEW: Receive fresh threshold data from Core 0
        if (queue_try_remove(&thresholds_queue, &fresh_thresholds)) {
            display.setCurrentThresholds(fresh_thresholds);
        }

        if (queue_try_remove(&control_queue, &control_msg)) {
            switch (control_msg.command) {
            case ControlCommand::SetUsbMode:
                display.setUsbMode(control_msg.data.usb_mode);
                break;
            case ControlCommand::SetPlayerLed:
                switch (control_msg.data.player_led.type) {
                case USB_PLAYER_LED_ID:
                    display.setPlayerId(control_msg.data.player_led.id);
                    break;
                case USB_PLAYER_LED_COLOR:
                    led.setPlayerColor({.r = control_msg.data.player_led.red,
                                        .g = control_msg.data.player_led.green,
                                        .b = control_msg.data.player_led.blue});
                }
                break;
            case ControlCommand::SetLedBrightness:
                led.setBrightness(control_msg.data.led_brightness);
                break;
            case ControlCommand::SetLedEnablePlayerColor:
                led.setEnablePlayerColor(control_msg.data.led_enable_player_color);
                break;
            case ControlCommand::EnterMenu:
                display.showMenu();
                break;
            case ControlCommand::ExitMenu:
                display.showIdle();
                break;
            }
        }
        if (queue_try_remove(&menu_display_queue, &menu_display_msg)) {
            display.setMenuState(menu_display_msg);
        }
        if (queue_try_remove(&bringup_test_queue, &bringup_test_state)) {
            display.setBringupTestState(bringup_test_state);
            if (bringup_test_state.active) {
                display.showBringupTest();
            }
        }
        
        // Drive calibration wizard display from GuidedCalState mode.
        // Fail-safe: force the wizard screen state every frame while active so we never
        // remain on Idle/Menu due to a missed mode-change edge.
        {
            using Mode = Peripherals::Drum::GuidedCalState::Mode;
            if (drum_ptr && drum_ptr->isGuidedCalActive()) {
                const auto& ts = drum_ptr->getGuidedCalState();
                switch (ts.current_mode) {
                case Mode::Welcome:
                case Mode::Instructions:
                case Mode::CancelConfirm:
                case Mode::Cancelled:
                    display.showGuidedCalWelcome();
                    break;
                case Mode::PadNormal:
                case Mode::PadHard:
                    display.showGuidedCalPadTest();
                    break;
                case Mode::BleedDetected:
                    display.showGuidedCalError();
                    break;
                case Mode::Review:
                    display.showGuidedCalOverview();
                    break;
                case Mode::Saving:     display.showGuidedCalSaving();     break;
                case Mode::Complete:   display.showGuidedCalComplete();   break;
                default: break;
                }
            }
        }

        if (queue_try_remove(&auth_challenge_queue, auth_challenge.data())) {
            const auto signed_challenge = ps4authprovider.sign(auth_challenge);
            queue_try_remove(&auth_signed_challenge_queue, nullptr);
            queue_try_add(&auth_signed_challenge_queue, &signed_challenge);
        }

        led.setInputState(input_state);
        display.setInputState(input_state);

        led.update();
        display.update();
    }
}

} // namespace

int main() {
    queue_init(&control_queue, sizeof(ControlMessage), 1);
    queue_init(&menu_display_queue, sizeof(Utils::Menu::State), 1);
    queue_init(&drum_input_queue, sizeof(Utils::InputState::Drum), 1);
    queue_init(&controller_input_queue, sizeof(Utils::InputState::Controller), 8);
    queue_init(&bringup_test_queue, sizeof(Peripherals::Display::BringupTestState), 1);
    queue_init(&auth_challenge_queue, sizeof(std::array<uint8_t, Utils::PS4AuthProvider::SIGNATURE_LENGTH>), 1);
    queue_init(&auth_signed_challenge_queue, sizeof(std::array<uint8_t, Utils::PS4AuthProvider::SIGNATURE_LENGTH>), 1);
    queue_init(&drum_reference_queue, sizeof(Peripherals::Drum*), 1);
    
    // NEW: Initialize queue for fresh threshold data
    queue_init(&thresholds_queue, sizeof(Peripherals::Drum::Config::Thresholds), 1);

    stdio_init_all();

    Peripherals::Drum drum(Config::Default::drum_config);

    Utils::InputReport input_report;
    Utils::InputState input_state;
    Utils::InputState::Controller latest_controller_state{};
    
    // NEW: Hotkey state variables are now local to main, allowing manual reset
    uint32_t start_menu_last_press_ms = 0;
    uint32_t select_menu_last_press_ms = 0;
    bool start_menu_prev_down = false;
    bool select_menu_prev_down = false;
    bool start_select_menu_latched = false;

    // NEW: Function to manually reset the hotkey state
    const auto resetHotkeyState = [&]() {
        start_menu_last_press_ms = 0;
        select_menu_last_press_ms = 0;
        start_menu_prev_down = false;
        select_menu_prev_down = false;
        start_select_menu_latched = false;
    };

    // Quick START + SELECT combo to enter the menu without relying on a long
    // single-button hold that can overlap with game UI shortcuts.
    const auto checkMenuCombo =
        [&input_state,
         &start_menu_last_press_ms,
         &select_menu_last_press_ms,
         &start_menu_prev_down,
         &select_menu_prev_down,
         &start_select_menu_latched]() {
            static const uint32_t COMBO_WINDOW_MS = 200;

            const bool start_down = input_state.controller.buttons.start;
            const bool select_down = input_state.controller.buttons.select;
            const bool dpad_active = input_state.controller.dpad.up ||
                                     input_state.controller.dpad.down ||
                                     input_state.controller.dpad.left ||
                                     input_state.controller.dpad.right;
            const uint32_t current_time = to_ms_since_boot(get_absolute_time());

            if (start_down && !start_menu_prev_down) {
                start_menu_last_press_ms = current_time;
            }
            if (select_down && !select_menu_prev_down) {
                select_menu_last_press_ms = current_time;
            }

            bool combo_triggered = false;
            if (!start_select_menu_latched && start_down && select_down && !dpad_active &&
                start_menu_last_press_ms != 0 && select_menu_last_press_ms != 0) {
                const uint32_t delta =
                    (start_menu_last_press_ms > select_menu_last_press_ms)
                        ? (start_menu_last_press_ms - select_menu_last_press_ms)
                        : (select_menu_last_press_ms - start_menu_last_press_ms);
                if (delta <= COMBO_WINDOW_MS) {
                    combo_triggered = true;
                    start_select_menu_latched = true;
                }
            }

            if (!start_down && !select_down) {
                start_select_menu_latched = false;
            }

            start_menu_prev_down = start_down;
            select_menu_prev_down = select_down;
            return combo_triggered;
        };

    // Hold HOME for 5 seconds to reboot into bootloader (BOOTSEL) mode.
    // Saves wear on physical BOOTSEL button -- no need to hold while plugging in.
    const auto checkHoldHome = [&input_state]() {
        static uint32_t home_hold_start = 0;
        static bool was_held = false;
        static uint8_t press_count = 0;
        static const uint32_t HOLD_DURATION_MS = 5000;
        static const uint8_t DEBOUNCE_THRESHOLD = 3;

        bool home_pressed = input_state.controller.buttons.home;
        uint32_t current_time = to_ms_since_boot(get_absolute_time());

        if (home_pressed) {
            press_count++;
            if (press_count >= DEBOUNCE_THRESHOLD && home_hold_start == 0) {
                home_hold_start = current_time;
                was_held = false;
            }
            if (home_hold_start != 0 && !was_held && (current_time - home_hold_start) >= HOLD_DURATION_MS) {
                was_held = true;
                press_count = 0;
                home_hold_start = 0;
                return true;
            }
        } else {
            press_count = 0;
            home_hold_start = 0;
            was_held = false;
        }
        return false;
    };

    // Hold START for 2 seconds to reboot into bootloader (BOOTSEL) mode.
    // Same behaviour as hold HOME — goes through the BootselMsg countdown splash.
    const auto checkHoldStart = [&input_state]() {
        static uint32_t start_hold_start = 0;
        static bool was_held = false;
        static uint8_t press_count = 0;
        static const uint32_t HOLD_DURATION_MS = 2000;
        static const uint8_t DEBOUNCE_THRESHOLD = 3;

        bool start_pressed = input_state.controller.buttons.start;
        uint32_t current_time = to_ms_since_boot(get_absolute_time());

        if (start_pressed) {
            press_count++;
            if (press_count >= DEBOUNCE_THRESHOLD && start_hold_start == 0) {
                start_hold_start = current_time;
                was_held = false;
            }
            if (start_hold_start != 0 && !was_held && (current_time - start_hold_start) >= HOLD_DURATION_MS) {
                was_held = true;
                press_count = 0;
                start_hold_start = 0;
                return true;
            }
        } else {
            press_count = 0;
            start_hold_start = 0;
            was_held = false;
        }
        return false;
    };

    auto settings_store = std::make_shared<Utils::SettingsStore>();
    const auto clamp_u16 = [](uint16_t v, uint16_t lo, uint16_t hi) -> uint16_t {
        return (v < lo) ? lo : ((v > hi) ? hi : v);
    };
    const auto readSettings = [&]() {
        const auto sendCtrlMessage = [&](const ControlMessage &msg) { queue_add_blocking(&control_queue, &msg); };
        const auto current_mode = settings_store->getUsbMode();

        // Sanitize stored drum settings so stale/corrupt flash values cannot
        // silently choke hit detection after schema or firmware changes.
        auto thresholds = settings_store->getTriggerThresholds();
        const uint16_t raw_hit_hold = settings_store->getHitHoldMs();
        const uint16_t safe_hit_hold = clamp_u16(raw_hit_hold, 1, 30);
        thresholds.don_left  = clamp_u16(thresholds.don_left, 10, 1500);
        thresholds.ka_left   = clamp_u16(thresholds.ka_left, 10, 1500);
        thresholds.don_right = clamp_u16(thresholds.don_right, 10, 1500);
        thresholds.ka_right  = clamp_u16(thresholds.ka_right, 10, 1500);

        if (safe_hit_hold != raw_hit_hold || thresholds.don_left != settings_store->getTriggerThresholds().don_left ||
            thresholds.ka_left != settings_store->getTriggerThresholds().ka_left ||
            thresholds.don_right != settings_store->getTriggerThresholds().don_right ||
            thresholds.ka_right != settings_store->getTriggerThresholds().ka_right) {
            settings_store->setHitHoldMs(safe_hit_hold);
            settings_store->setTriggerThresholds(thresholds);
        }

        sendCtrlMessage({.command = ControlCommand::SetUsbMode, .data = {.usb_mode = current_mode}});
        sendCtrlMessage({.command = ControlCommand::SetLedBrightness,
                         .data = {.led_brightness = settings_store->getLedBrightness()}});
        sendCtrlMessage({.command = ControlCommand::SetLedEnablePlayerColor,
                         .data = {.led_enable_player_color = settings_store->getLedEnablePlayerColor()}});

        drum.setHitHoldMs(safe_hit_hold);
        drum.setTriggerThresholds(thresholds);
    };

    Utils::Menu menu(settings_store);

    static constexpr bool kEnableBringupTest = false;
    static constexpr uint8_t kBringupTargetCount = 18;
    uint8_t bringup_current_index = 0;
    bool bringup_active = kEnableBringupTest;
    Utils::InputState previous_bringup_input{};

    const auto pushBringupState = [&]() {
        Peripherals::Display::BringupTestState state{
            .active = bringup_active,
            .current_index = bringup_current_index,
        };
        queue_try_remove(&bringup_test_queue, nullptr);
        queue_try_add(&bringup_test_queue, &state);
    };

    const auto bringupTargetTriggered =
        [&](uint8_t index, const Utils::InputState &current, const Utils::InputState &previous) -> bool {
        switch (index) {
        case 0:  return current.controller.buttons.share && !previous.controller.buttons.share;
        case 1:  return current.controller.buttons.home && !previous.controller.buttons.home;
        case 2:  return current.controller.buttons.select && !previous.controller.buttons.select;
        case 3:  return current.controller.buttons.start && !previous.controller.buttons.start;
        case 4:  return current.controller.buttons.l && !previous.controller.buttons.l;
        case 5:  return current.controller.buttons.r && !previous.controller.buttons.r;
        case 6:  return current.controller.dpad.left && !previous.controller.dpad.left;
        case 7:  return current.controller.dpad.up && !previous.controller.dpad.up;
        case 8:  return current.controller.dpad.down && !previous.controller.dpad.down;
        case 9:  return current.controller.dpad.right && !previous.controller.dpad.right;
        case 10: return current.controller.buttons.west && !previous.controller.buttons.west;   // Y
        case 11: return current.controller.buttons.north && !previous.controller.buttons.north; // X
        case 12: return current.controller.buttons.south && !previous.controller.buttons.south; // B
        case 13: return current.controller.buttons.east && !previous.controller.buttons.east;   // A
        case 14: return current.drum.ka_left.triggered && !previous.drum.ka_left.triggered;
        case 15: return current.drum.don_left.triggered && !previous.drum.don_left.triggered;
        case 16: return current.drum.don_right.triggered && !previous.drum.don_right.triggered;
        case 17: return current.drum.ka_right.triggered && !previous.drum.ka_right.triggered;
        default: return false;
        }
    };

    std::array<uint8_t, Utils::PS4AuthProvider::SIGNATURE_LENGTH> auth_challenge_response{};
    if (Config::PS4Auth::config.enabled) {
        ps4_auth_init(Config::PS4Auth::config.key_pem.c_str(), Config::PS4Auth::config.key_pem.size() + 1,
                      Config::PS4Auth::config.serial.data(), Config::PS4Auth::config.signature.data(),
                      [](const uint8_t *challenge) { queue_try_add(&auth_challenge_queue, challenge); });
    }

    // Send drum pointer to core 1 before launching
    Peripherals::Drum *drum_ptr = &drum;
    queue_add_blocking(&drum_reference_queue, &drum_ptr);

    multicore_launch_core1(core1_task);
    pushBringupState();

    usbd_driver_init(settings_store->getUsbMode());
    usbd_driver_set_player_led_cb([](usb_player_led_t player_led) {
        const auto ctrl_message =
            ControlMessage{.command = ControlCommand::SetPlayerLed, .data = {.player_led = player_led}};
        queue_try_add(&control_queue, &ctrl_message);
    });

    readSettings();

    uint32_t ps4_auth_start_time = 0;
    
    // Guided calibration state tracking for auto-save
    bool last_guided_cal_active = false;
    
    // Guided calibration results display timing
    bool results_displaying = false;

    // Prevent the same A press used to select "Start Guided" from immediately
    // advancing Welcome -> PadNormal in the first active frame.
    bool guided_cal_wait_for_confirm_release = false;

    while (true) {
        const auto mode = settings_store->getUsbMode();
        drum.updateInputState(input_state, mode);

        // Drain queue to the most recent controller sample each frame.
        // This avoids stale "button still down" states that can block edge detection.
        Utils::InputState::Controller sampled_controller{};
        while (queue_try_remove(&controller_input_queue, &sampled_controller)) {
            latest_controller_state = sampled_controller;
        }
        input_state.controller = latest_controller_state;

        if (bringup_active) {
            if (bringup_current_index < kBringupTargetCount &&
                bringupTargetTriggered(bringup_current_index, input_state, previous_bringup_input)) {
                ++bringup_current_index;
                if (bringup_current_index >= kBringupTargetCount) {
                    bringup_active = true; // keep PASS screen visible until power cycle
                }
                pushBringupState();
            }
            previous_bringup_input = input_state;
        }

        // Keep the display and live drum thresholds in sync while editing in the menu.
        // This makes manual tuning feel immediate, while CANCEL still works because the
        // menu restores SettingsStore before exit.
        if (menu.active()) {
            auto fresh_thresholds = settings_store->getTriggerThresholds();
            drum.setTriggerThresholds(fresh_thresholds);
            queue_try_remove(&thresholds_queue, nullptr);
            queue_try_add(&thresholds_queue, &fresh_thresholds);
        }

        // Drive guided calibration A/B buttons in main loop (Core 0)
        const auto& guided_cal_state = drum.getGuidedCalState();
        bool guided_cal_active = guided_cal_state.isActive();
        using TMode = Peripherals::Drum::GuidedCalState::Mode;

        if (guided_cal_active) {
            // Debounce: track A button edge
            static bool last_east = false;
            static bool last_south = false;
            static uint32_t south_hold_start_ms = 0;
            static bool south_cancel_latched = false;
            static constexpr uint32_t SOUTH_CANCEL_HOLD_MS = 180;
            bool east_pressed  = input_state.controller.buttons.east  && !last_east;
            bool south_pressed = input_state.controller.buttons.south && !last_south;
            bool south_down = input_state.controller.buttons.south;
            uint32_t now_ms = to_ms_since_boot(get_absolute_time());
            last_east  = input_state.controller.buttons.east;
            last_south = input_state.controller.buttons.south;
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

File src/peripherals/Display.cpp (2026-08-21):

// Beginning of file Display.cpp

#include "peripherals/Display.h"
#include "peripherals/Drum.h"

#include "hardware/gpio.h"
#include "pico/time.h"

#include "bitmaps/MenuScreens.h"

#include <list>
#include <numeric>
#include <string>
#include <cmath>
#include <sstream>
#include <cstring>
#include <cstdio>

namespace OuchiTaiko::Peripherals {

// Namespace for bitmap resources (forward declarations to avoid missing bitmaps errors)
namespace bitmaps {
    extern const uint8_t IdleDonLeft[];
    extern const uint8_t IdleKaLeft[];
    extern const uint8_t IdleDonRight[];
    extern const uint8_t IdleKaRight[];
}

// ==========================================================
// File-scope Helper Functions
// ==========================================================

static void drawUpArrow(ssd1306_t *display, int x, int y) {
    ssd1306_draw_pixel(display, x + 2, y);
    ssd1306_draw_pixel(display, x + 1, y + 1);
    ssd1306_draw_pixel(display, x + 2, y + 1);
    ssd1306_draw_pixel(display, x + 3, y + 1);
    ssd1306_draw_pixel(display, x + 1, y + 2);
    ssd1306_draw_pixel(display, x + 2, y + 2);
    ssd1306_draw_pixel(display, x + 3, y + 2);
    ssd1306_draw_pixel(display, x, y + 3);
    ssd1306_draw_pixel(display, x + 1, y + 3);
    ssd1306_draw_pixel(display, x + 2, y + 3);
    ssd1306_draw_pixel(display, x + 3, y + 3);
    ssd1306_draw_pixel(display, x + 4, y + 3);
    ssd1306_draw_pixel(display, x, y + 4);
    ssd1306_draw_pixel(display, x + 1, y + 4);
    ssd1306_draw_pixel(display, x + 2, y + 4);
    ssd1306_draw_pixel(display, x + 3, y + 4);
    ssd1306_draw_pixel(display, x + 4, y + 4);
    ssd1306_draw_pixel(display, x, y + 5);
    ssd1306_draw_pixel(display, x + 1, y + 5);
    ssd1306_draw_pixel(display, x + 2, y + 5);
    ssd1306_draw_pixel(display, x + 3, y + 5);
    ssd1306_draw_pixel(display, x + 4, y + 5);
    ssd1306_draw_pixel(display, x, y + 6);
    ssd1306_draw_pixel(display, x + 1, y + 6);
    ssd1306_draw_pixel(display, x + 2, y + 6);
    ssd1306_draw_pixel(display, x + 3, y + 6);
    ssd1306_draw_pixel(display, x + 4, y + 6);
}

static void drawDownArrow(ssd1306_t *display, int x, int y) {
    ssd1306_draw_pixel(display, x, y);
    ssd1306_draw_pixel(display, x + 1, y);
    ssd1306_draw_pixel(display, x + 2, y);
    ssd1306_draw_pixel(display, x + 3, y);
    ssd1306_draw_pixel(display, x + 4, y);
    ssd1306_draw_pixel(display, x, y + 1);
    ssd1306_draw_pixel(display, x + 1, y + 1);
    ssd1306_draw_pixel(display, x + 2, y + 1);
    ssd1306_draw_pixel(display, x + 3, y + 1);
    ssd1306_draw_pixel(display, x + 4, y + 1);
    ssd1306_draw_pixel(display, x, y + 2);
    ssd1306_draw_pixel(display, x + 1, y + 2);
    ssd1306_draw_pixel(display, x + 2, y + 2);
    ssd1306_draw_pixel(display, x + 3, y + 2);
    ssd1306_draw_pixel(display, x + 4, y + 2);
    ssd1306_draw_pixel(display, x, y + 3);
    ssd1306_draw_pixel(display, x + 1, y + 3);
    ssd1306_draw_pixel(display, x + 2, y + 3);
    ssd1306_draw_pixel(display, x + 3, y + 3);
    ssd1306_draw_pixel(display, x + 4, y + 3);
    ssd1306_draw_pixel(display, x + 1, y + 4);
    ssd1306_draw_pixel(display, x + 2, y + 4);
    ssd1306_draw_pixel(display, x + 3, y + 4);
    ssd1306_draw_pixel(display, x + 1, y + 5);
    ssd1306_draw_pixel(display, x + 2, y + 5);
    ssd1306_draw_pixel(display, x + 3, y + 5);
    ssd1306_draw_pixel(display, x + 2, y + 6);
}

static void drawLeftArrow(ssd1306_t *display, int x, int y) {
    ssd1306_draw_pixel(display, x + 4, y);
    ssd1306_draw_pixel(display, x + 3, y + 1);
    ssd1306_draw_pixel(display, x + 4, y + 1);
    ssd1306_draw_pixel(display, x + 2, y + 2);
    ssd1306_draw_pixel(display, x + 3, y + 2);
    ssd1306_draw_pixel(display, x + 4, y + 2);
    ssd1306_draw_pixel(display, x + 1, y + 3);
    ssd1306_draw_pixel(display, x + 2, y + 3);
    ssd1306_draw_pixel(display, x + 3, y + 3);
    ssd1306_draw_pixel(display, x + 4, y + 3);
    ssd1306_draw_pixel(display, x + 2, y + 4);
    ssd1306_draw_pixel(display, x + 3, y + 4);
    ssd1306_draw_pixel(display, x + 4, y + 4);
    ssd1306_draw_pixel(display, x + 3, y + 5);
    ssd1306_draw_pixel(display, x + 4, y + 5);
    ssd1306_draw_pixel(display, x + 4, y + 6);
}

static void drawRightArrow(ssd1306_t *display, int x, int y) {
    ssd1306_draw_pixel(display, x, y);
    ssd1306_draw_pixel(display, x, y + 1);
    ssd1306_draw_pixel(display, x + 1, y + 1);
    ssd1306_draw_pixel(display, x, y + 2);
    ssd1306_draw_pixel(display, x + 1, y + 2);
    ssd1306_draw_pixel(display, x + 2, y + 2);
    ssd1306_draw_pixel(display, x, y + 3);
    ssd1306_draw_pixel(display, x + 1, y + 3);
    ssd1306_draw_pixel(display, x + 2, y + 3);
    ssd1306_draw_pixel(display, x + 3, y + 3);
    ssd1306_draw_pixel(display, x, y + 4);
    ssd1306_draw_pixel(display, x + 1, y + 4);
    ssd1306_draw_pixel(display, x + 2, y + 4);
    ssd1306_draw_pixel(display, x, y + 5);
    ssd1306_draw_pixel(display, x + 1, y + 5);
    ssd1306_draw_pixel(display, x, y + 6);
}

namespace {

std::string modeToString(usb_mode_t mode) {
    switch (mode) {
    case USB_MODE_SWITCH_TATACON:
        return "Switch Tatacon";
    case USB_MODE_SWITCH_HORIPAD:
        return "Switch Pro";
    case USB_MODE_DUALSHOCK3:
        return "Dualshock 3";
    case USB_MODE_PS4_TATACON:
        return "PS4 Tatacon";
    case USB_MODE_DUALSHOCK4:
        return "Dualshock 4";
    case USB_MODE_KEYBOARD_P1:
        return "Keyboard P1";
    case USB_MODE_KEYBOARD_P2:
        return "Keyboard P2";
    case USB_MODE_XBOX360:
        return "Xbox 360";
    case USB_MODE_ANDROID:
        return "Android";
    case USB_MODE_IOS:
        return "iOS";
    case USB_MODE_XBOX360_ANALOG_P1:
        return "Analog P1";
    case USB_MODE_XBOX360_ANALOG_P2:
        return "Analog P2";
    case USB_MODE_MIDI:
        return "MIDI";
    case USB_MODE_DEBUG:
        return "Guided Cal";
    }
    return "?";
}

} // namespace

// ==========================================================
// Display Class Implementation
// ==========================================================

Display::Display(const Config &config) : 
    m_config(config),
    m_boot_splash_start(to_ms_since_boot(get_absolute_time()))
{
    m_display.external_vcc = false;
    ssd1306_init(&m_display, 128, 64, m_config.i2c_address, m_config.i2c_block);
    ssd1306_clear(&m_display);
    
    // Initialize all rings as inactive
    for (int i = 0; i < 4; i++) {
        for (int j = 0; j < MAX_RINGS_PER_DRUM; j++) {
            m_rings[i][j].active = false;
            m_rings[i][j].radius = 0;
        }
    }
    
    // Initialize particles as inactive
    for (int i = 0; i < MAX_PARTICLES; i++) {
        m_particles[i].active = false;
    }
}

void Display::setInputState(const Utils::InputState &state) { m_input_state = state; }
void Display::setUsbMode(usb_mode_t mode) { m_usb_mode = mode; };
void Display::setPlayerId(uint8_t player_id) { m_player_id = player_id; };
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

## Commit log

2026-01-26 OuchiTaiko v15.0 - Public Release
    [OuchiTaiko-Project-Bachi-Stick-Holder.stl, OuchiTaiko-Project-Control-Box-Base.stl, OuchiTaiko-Project-Control-Box-Lid.stl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]
2026-03-14 Fix cut off difficulty text
    [Display.cpp, Drum.cpp, Drum.h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]
2026-06-06 all update
    [OuchiTaiko-Project-Bachi-Stick-Holder.stl, OuchiTaiko-Project-Sensor-Housing-Both.stl, PCB-Shell-Both.stl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]
2026-08-21 post test
    [smaller_housing_bottom.stl, smaller_housing_bracket.stl, smaller_housing_top.stl]
2026-08-22 GIT CLEAN
    [.codex_old_firmware_files.csv, .codex_target_window_files.csv, ouchitaiko_sensor_housing_small.stl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]
2026-08-22 git case

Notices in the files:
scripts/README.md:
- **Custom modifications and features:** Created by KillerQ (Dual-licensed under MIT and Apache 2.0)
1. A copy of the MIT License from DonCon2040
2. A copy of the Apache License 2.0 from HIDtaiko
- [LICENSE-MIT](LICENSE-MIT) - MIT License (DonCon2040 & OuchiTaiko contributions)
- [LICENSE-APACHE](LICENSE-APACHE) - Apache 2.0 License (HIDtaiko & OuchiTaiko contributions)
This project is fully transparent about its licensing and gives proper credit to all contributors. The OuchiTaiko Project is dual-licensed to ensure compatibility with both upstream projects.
